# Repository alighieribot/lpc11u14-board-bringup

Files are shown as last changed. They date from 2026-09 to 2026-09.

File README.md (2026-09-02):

# Board Bring-Up e Validação de Protótipo Eletrônico Embarcado
## Plataforma de Instrumentação e Controle Baseada no MCU NXP LPC11U14F (ARM Cortex-M0)








Este repositório reúne a documentação técnica integral, os projetos de engenharia eletrônica (esquemático elétrico, layout de PCI de 2 camadas e modelos 3D desenvolvidos no KiCad 9) e o firmware embarcado modular em linguagem C (bare-metal) estruturado em **Máquina de Estados Finitos (FSM)** para validação física e *board bring-up* de uma placa com o microcontrolador **NXP LPC11U14F** (núcleo ARM Cortex-M0).

O projeto foi concebido e implementado no âmbito da disciplina **PBLE02 (Projeto Baseado em Laboratório de Engenharia / Projeto de Hardware e Firmware)** do **Instituto de Engenharia de Sistemas e Tecnologia da Informação (IESTI)** da **Universidade Federal de Itajubá (UNIFEI)**, sob a orientação do **Prof. Dr. Rodrigo Maximiano Antunes de Almeida**.

---

## Equipe do Projeto (Grupo 1)

| Integrante | Matrícula |
| :--- | :---: |
| **Leonardo Mendonça Costa** | `2024001025` |
| **Fabricio Augusto Antonio** | `2025000031` |
| **Pedro Henrique Oliveira Francisco** | `2022003245` |
| **Luis Gustavo Ribeiro Chacon** | `2025004890` |

**Agradecimentos Institucionais:**
À equipe técnica de laboratório do IESTI/UNIFEI, em especial aos técnicos em eletrônica **José Anderson Reis** e **Nedson Joaquim Maia**, pelo auxílio instrumental de bancada, suporte de montagem e retrabalho de protótipos; e ao **Prof. Dr. Rodrigo Maximiano Antunes de Almeida** pelas orientações e direcionamento técnico durante a validação experimental.

---

## Visão Geral da Placa de Circuito Impresso (PCB)

A placa física foi projetada respeitando dimensões compactas de $80 \times 80\text{ mm}^2$ em substrato de fibra de vidro FR-4 de duas camadas condutivas, espessura de 1,6 mm, acabamento superficial HASL com chumbo, máscara de solda verde e serigrafia branca, fabricada pela JLCPCB.

| Face Superior 3D (Revisão Final Corrigida) | Face Inferior 3D (Plano de Terra Sólido) |
| :---: | :---: |
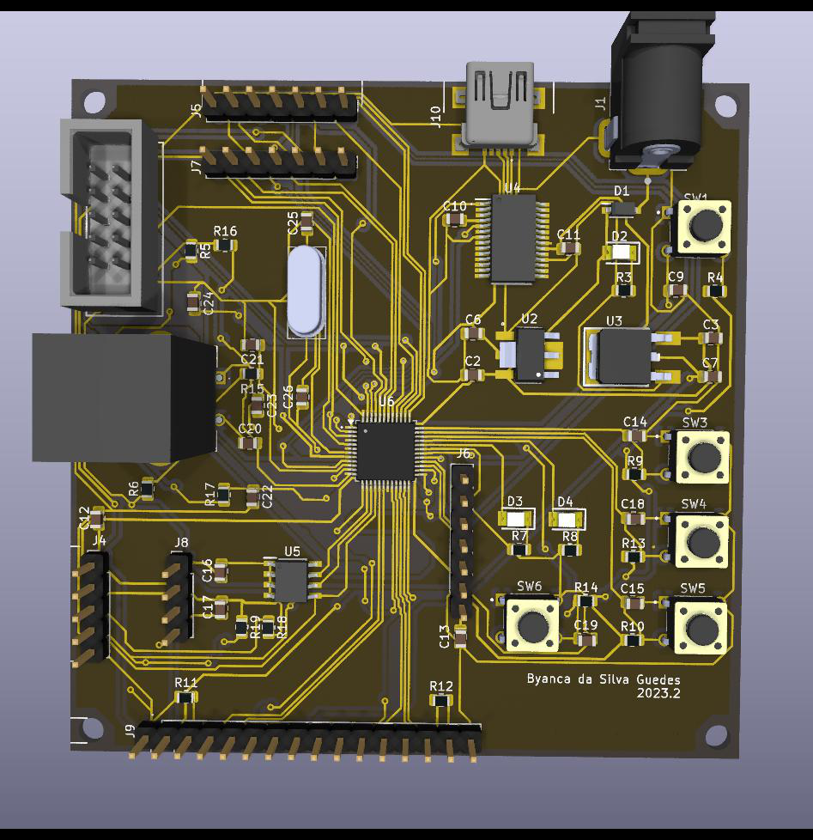
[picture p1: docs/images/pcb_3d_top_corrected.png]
PCB Top View
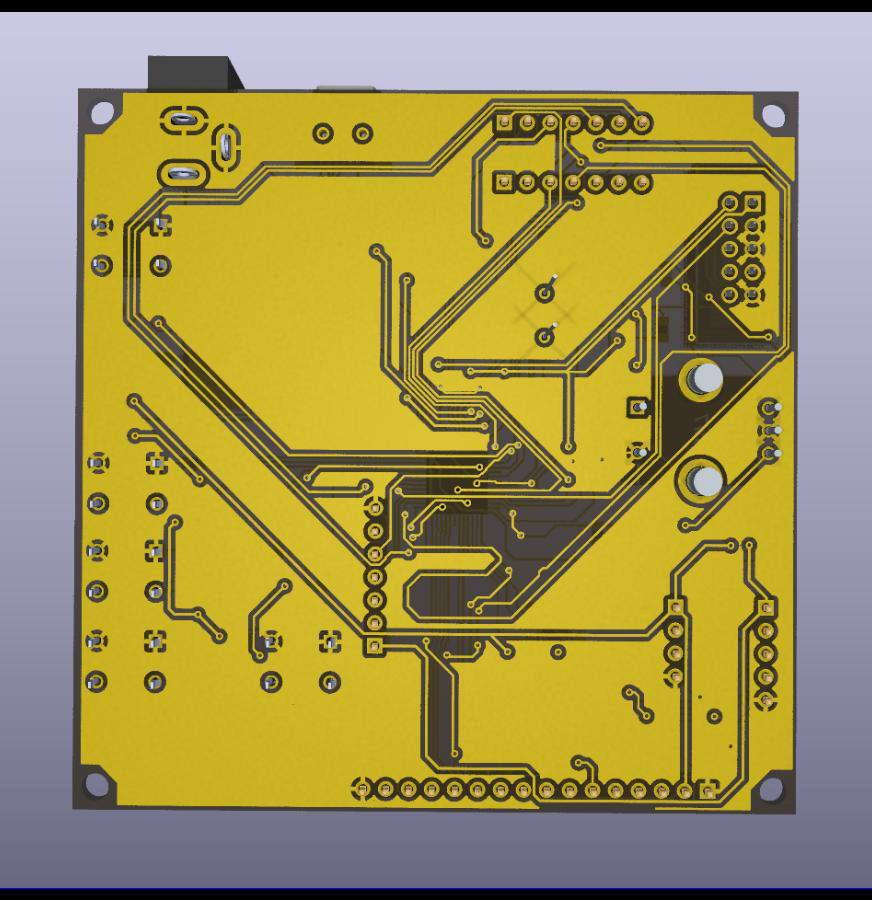
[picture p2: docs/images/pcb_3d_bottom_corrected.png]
PCB Bottom View
|  |  |

| Comparativo Histórico: Face Superior 3D Original |
| :---: |
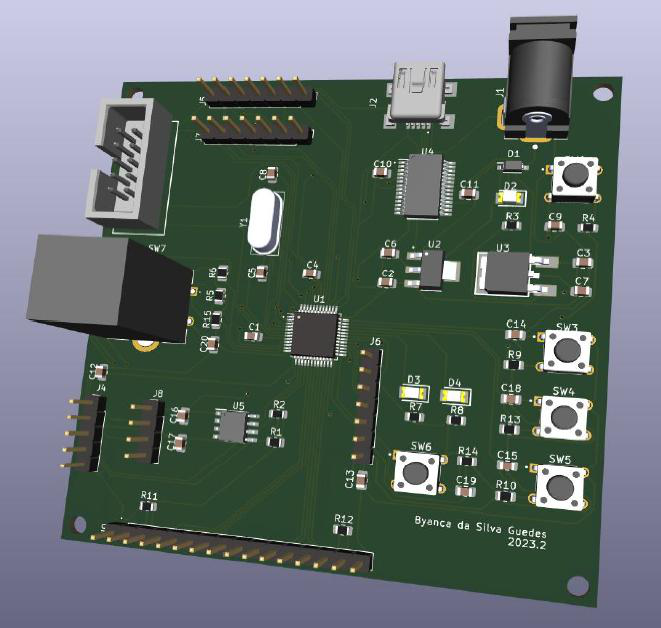
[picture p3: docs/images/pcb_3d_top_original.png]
PCB Top Original
|  |

> **BOM Interativo (iBOM):** O repositório inclui a lista de materiais interativa gerada pelo plugin *Interactive HTML BOM*. Para navegar visualmente por cada componente, ilha e footprint na placa, abra em seu navegador o arquivo [`KiCad/Projeto_Final/bom/ibom.html`](KiCad/Projeto_Final/bom/ibom.html).

---

## Arquitetura de Hardware & Subcircuitos

O sistema é subdividido em 5 subsistemas funcionais integrados:

```mermaid
graph TD
    PS["1. Subcircuito de Alimentação<br/>Jack DC 7-12V -> LD1117 5.0V & 3.3V"] --> MCU["2. Processamento Central<br/>NXP LPC11U14F ARM Cortex-M0 @ 48MHz"]
    PS --> COMM["5. Comunicação Serial<br/>FTDI FT232RL USB-UART"]
    PS --> HMI["3. Interface Homem-Máquina<br/>LCD 16x2, Encoder Bourns, 4x Teclas, LEDs"]
    PS --> PERIPH["4. Periféricos & Armazenamento<br/>EEPROM I2C 24LC512 + Headers Expansão"]

    MCU <-->|"UART 115200 bps"| COMM
    MCU <-->|"Barramento I2C 3.3V"| PERIPH
    MCU <-->|"GPIOs & PWM / Timers"| HMI
    MCU <-->|"ADC 10-bit / SPI / Expansão"| PERIPH
```

### 1. Subcircuito de Alimentação
- **Entrada:** Conector Jack fêmea P4 (PJ-002A) compatível com fontes externas DC na faixa de **7V a 12V**.
- **Proteção:** Diodo Schottky `1N5819HW-7-F` em série para bloqueio contra inversão de polaridade e transientes.
- **Regulação Linear em Cascata:**
  - `LD1117DT50TR` (DPAK): Converte a tensão de entrada para o barramento de **5.0V DC** (alimentação do display LCD).
  - `LD1117S33TR` (SOT-223): Fornece **3.3V DC** regulados (para microcontrolador, transceptor USB e EEPROM).
- **Filtragem e Desacoplamento:** Associação de capacitores eletrolíticos de $10\ \mu\text{F}$ e cerâmicos multicamada X7R de $220\text{ nF}$ nas entradas e saídas. LED piloto indicador de barramento energizado com resistor limitador de $1\text{ k}\Omega$.

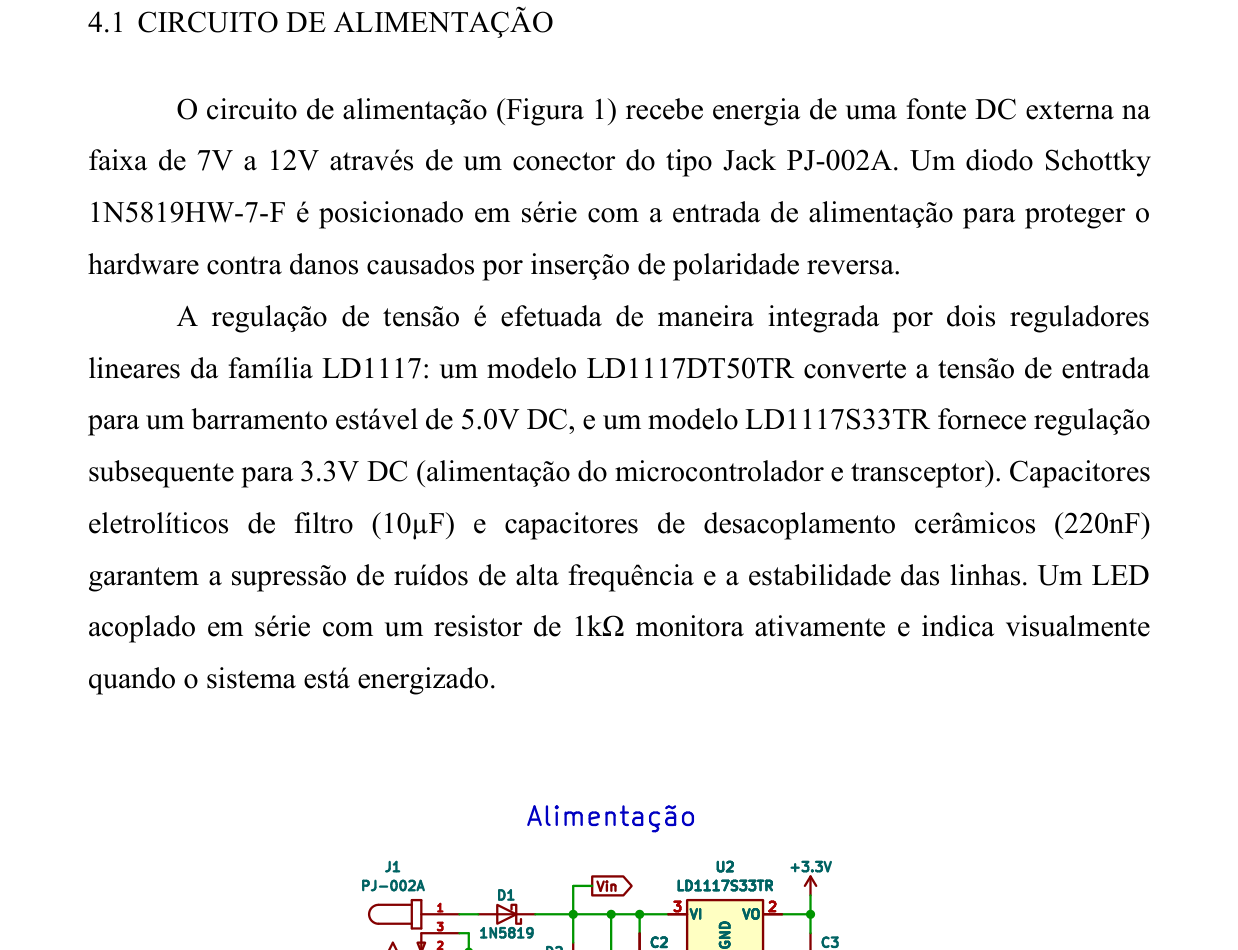
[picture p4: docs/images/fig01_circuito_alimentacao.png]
Circuito de Alimentação


---

### 2. Subcircuito de Processamento
- **MCU:** NXP `LPC11U14F/201` em encapsulamento LQFP-48, núcleo ARM Cortex-M0 operando a até **48 MHz**, dotado de 32 KB de memória Flash, 6 KB de SRAM, 4 KB de EEPROM integrada e controlador USB full-speed.
- **Oscilador de Clock:** Cristal de quartzo de alta precisão de **12.000 MHz** (CTS ATS12A) associado a capacitores de carga externos dimensionados em **18 pF**.
- **Reset e Bootloader ISP:**
  - Reset mestre com botão táctil `SW1`, pull-up de $4.7\text{ k}\Omega$ e capacitor de debounce de $10\ \mu\text{F}$.
  - Chave de programação em sistema (ISP) `SW6` com pull-up, interligada ao pino oficial de bootloader `PIO0_1` (Pino 4).
- **Depuração / Programação:** Header SWD (*Serial Wire Debug*) com pinos `SWDIO` (Pino 39) e `SWDCLK` (Pino 29).

| Processamento Original (LPC1114) | Processamento Corrigido (LPC11U14F) |
| :---: | :---: |
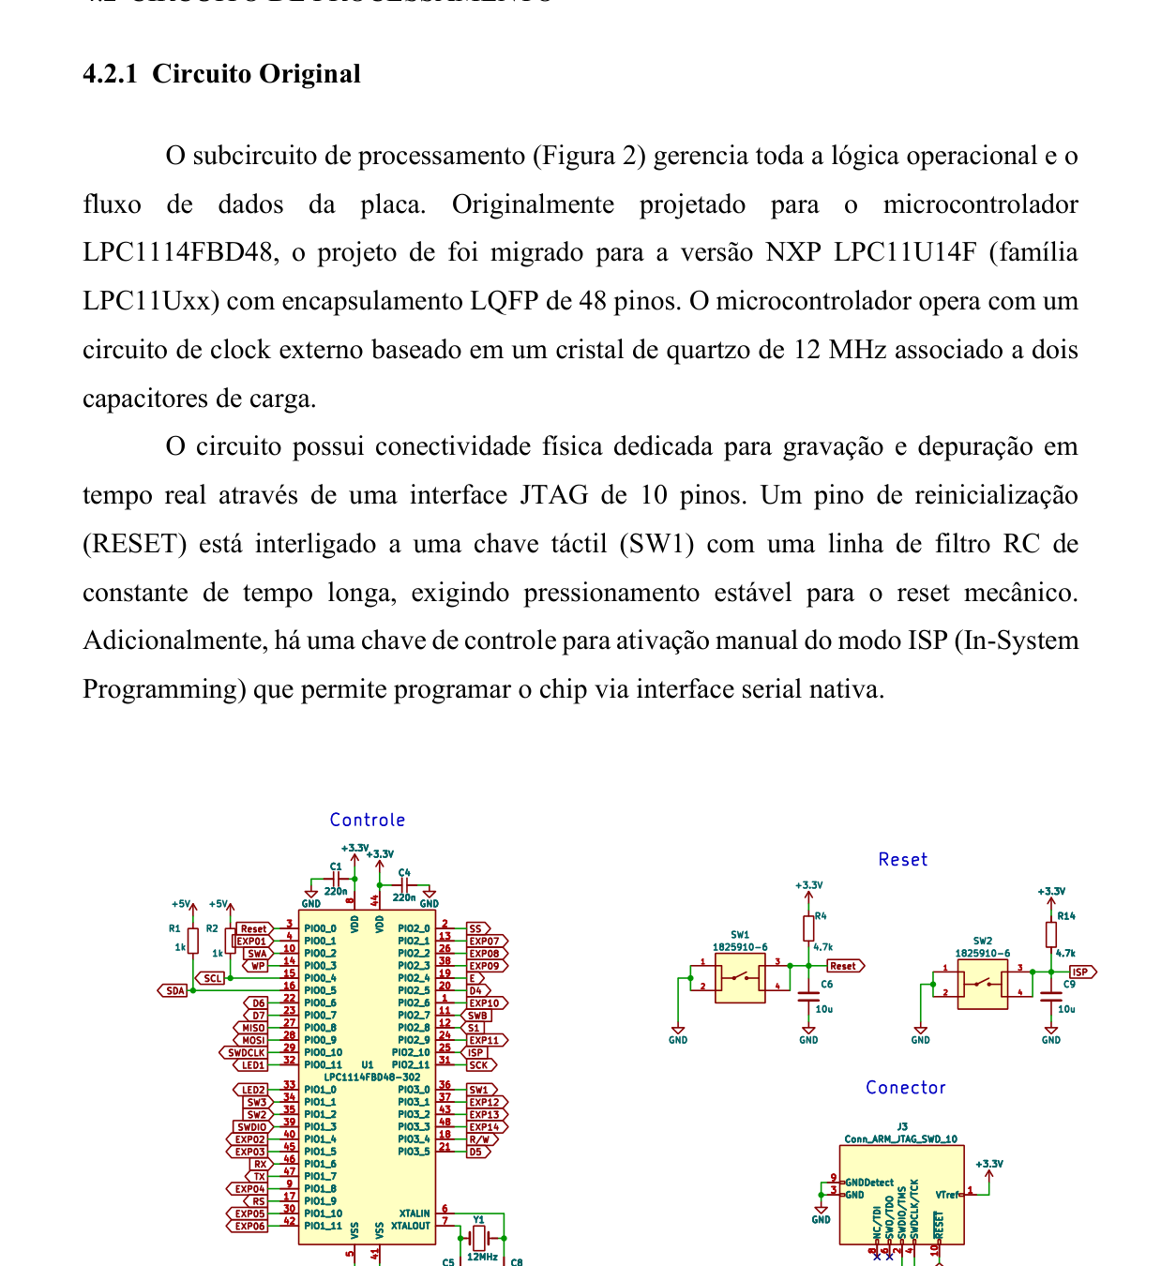
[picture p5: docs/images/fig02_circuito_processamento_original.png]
Processamento Original
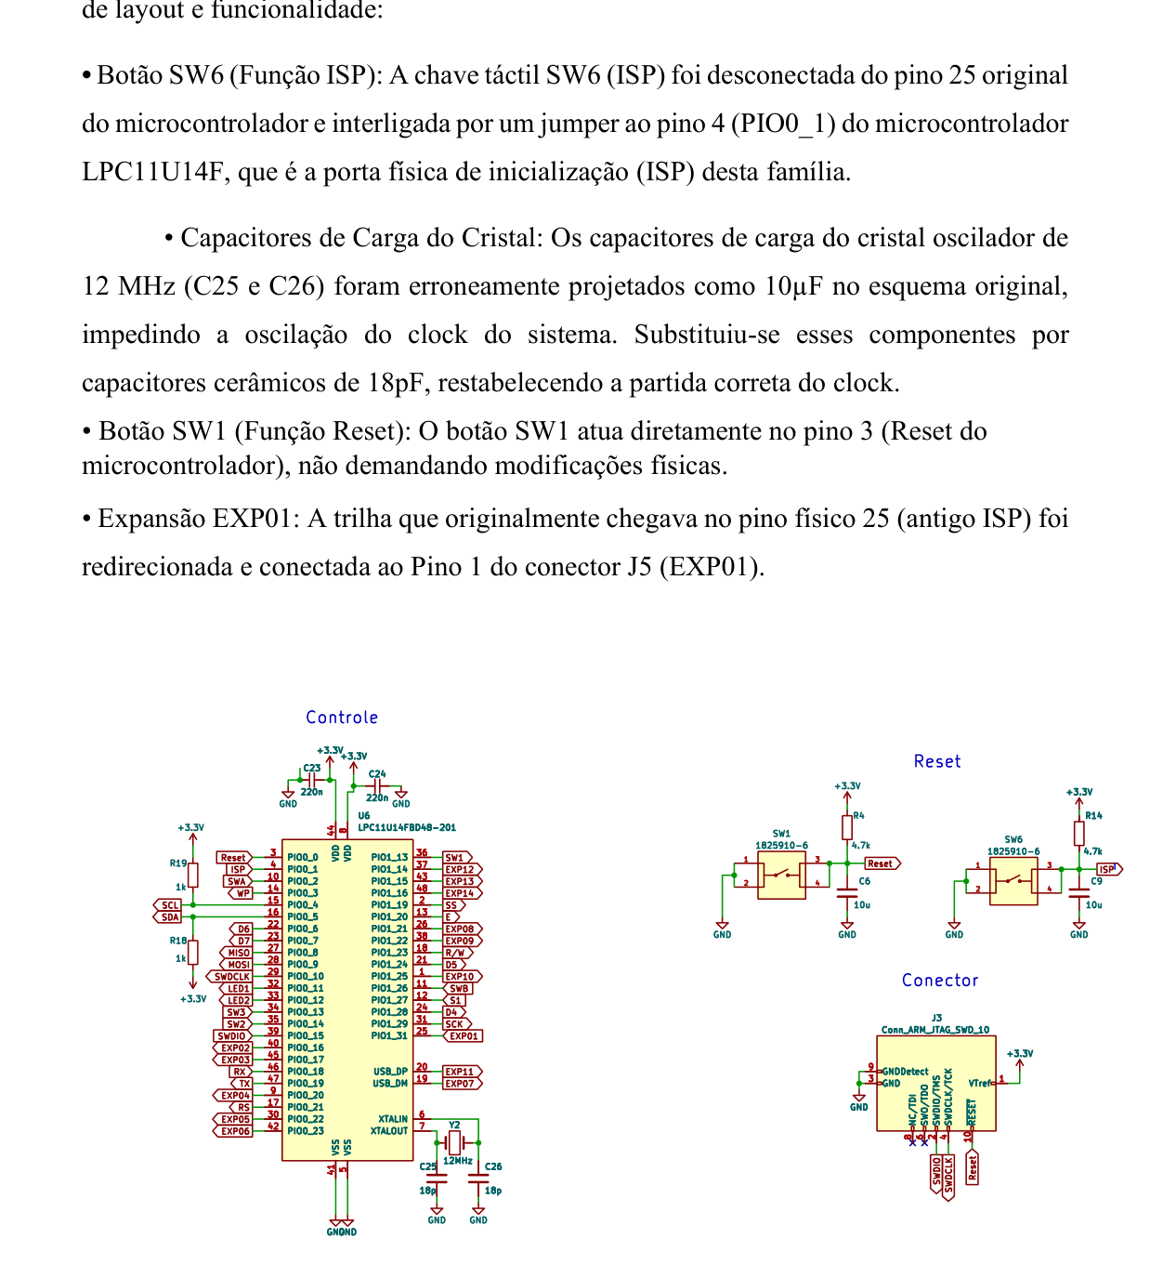
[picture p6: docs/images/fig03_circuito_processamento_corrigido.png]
Processamento Corrigido
|  |  |

---

### 3. Subcircuito de Interação com o Usuário (IHM)
- **Display Alfanumérico:** LCD 16×2 (compatível com controlador HD44780 / JHD162A) operando em barramento paralelo de **4 bits** (`D4` a `D7`), com controle pelos sinais `RS`, `R/W` e `ENABLE`. Ajuste de contraste via trimpot de precisão de $10\text{ k}\Omega$.
- **Encoder Rotativo Incremental:** Bourns `PEC12R` com 24 pulsos por rotação, canais em quadratura A e B, botão de clique central e filtro RC passivo anti-ruído mecânico (*debounce*).
- **Teclado Táctil:** 4 chaves tácteis push-button (`SW2`, `SW3`, `SW4`, `SW5`) com resistores de pull-up de $10\text{ k}\Omega$.
- **Sinalizadores Visuais:** Três LEDs SMD (`D2`, `D3`, `D4`) acionados diretamente pelas saídas digitais do microcontrolador com resistores limitadores de $100\ \Omega$.

| Interação Original | Interação Corrigida (Ajuste de R e C) |
| :---: | :---: |
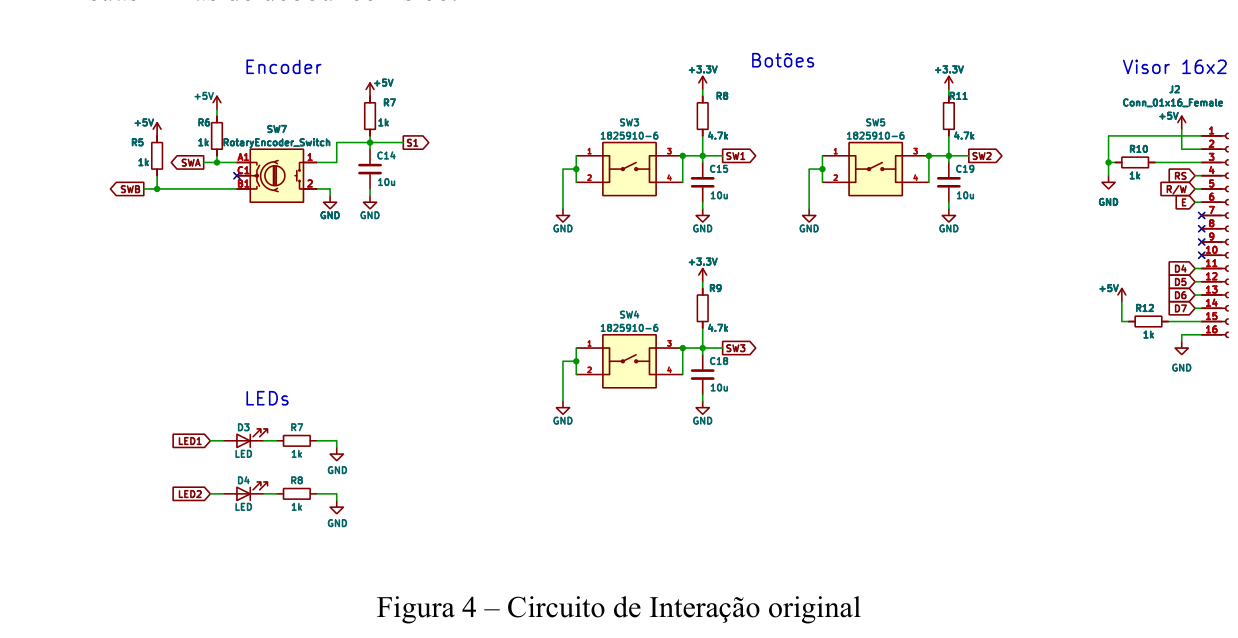
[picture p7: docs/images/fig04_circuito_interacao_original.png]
Interação Original
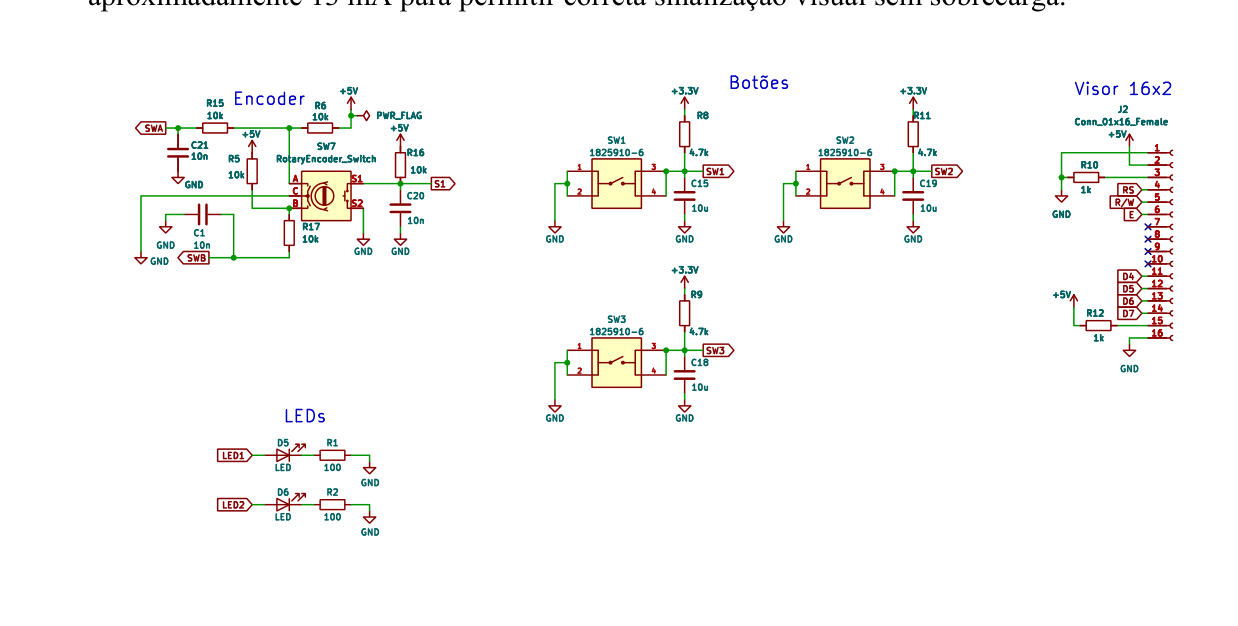
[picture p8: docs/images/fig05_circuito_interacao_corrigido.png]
Interação Corrigida
|  |  |

---

### 4. Subcircuito de Periféricos & Armazenamento
- **Memória EEPROM Externa:** Microchip `24LC512` (512 Kbit / 64 KByte) operando via barramento **I²C** com resistores de pull-up de $1\text{ k}\Omega$ polarizados em 3.3V.
- **Barramentos de Expansão:** Headers macho de passo 2.54 mm (`J4` a `J8`) expondo portas analógicas do ADC (10 bits), barramento SPI (`SCK`, `MISO`, `MOSI`, `SSEL`), alimentação e GPIOs livres.
- **Condicionamento de Sinal:** Canal de amplificação operacional para transdução de sinais analógicos externos com compensação de ganho em software (`GANHO_AMPOP`).

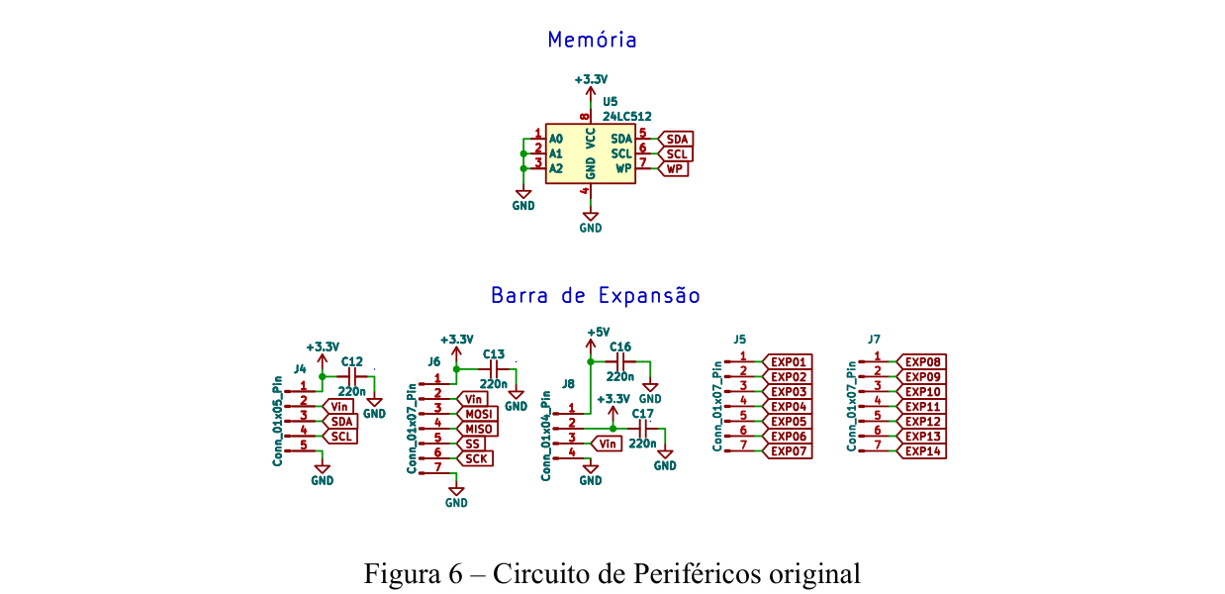
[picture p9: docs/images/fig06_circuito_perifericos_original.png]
Circuito de Periféricos


---

### 5. Subcircuito de Comunicação Serial
- **Transceptor USB-UART:** Chip dedicado FTDI `FT232RL` (SSOP-28) realizando a ponte entre o barramento USB da estação hospedeira e as portas seriais assíncronas do microcontrolador (`PIO0_18/RXD` e `PIO0_19/TXD`).
- **Conector Físico:** Porta Mini-USB Tipo B com filtragem e desacoplamento de alta frequência.

| Comunicação Original | Comunicação Corrigida (Isolamento VBUS) |
| :---: | :---: |
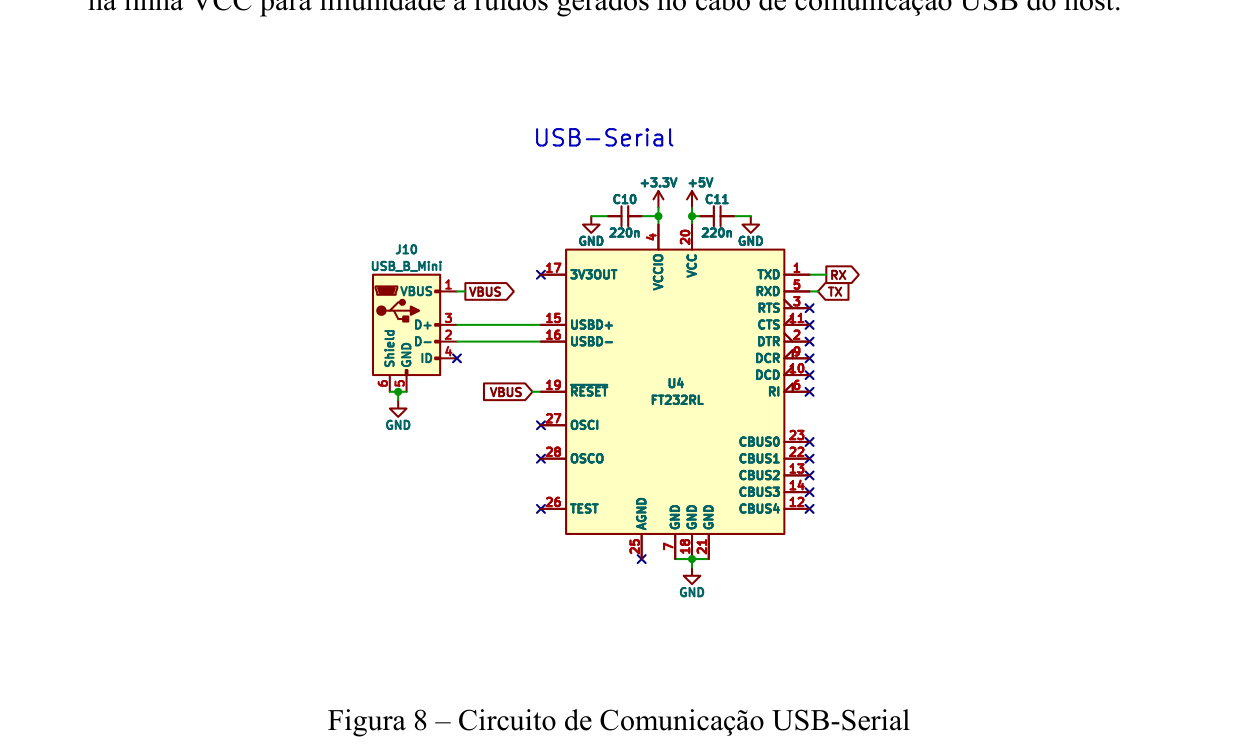
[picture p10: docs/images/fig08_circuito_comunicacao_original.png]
Comunicação Original
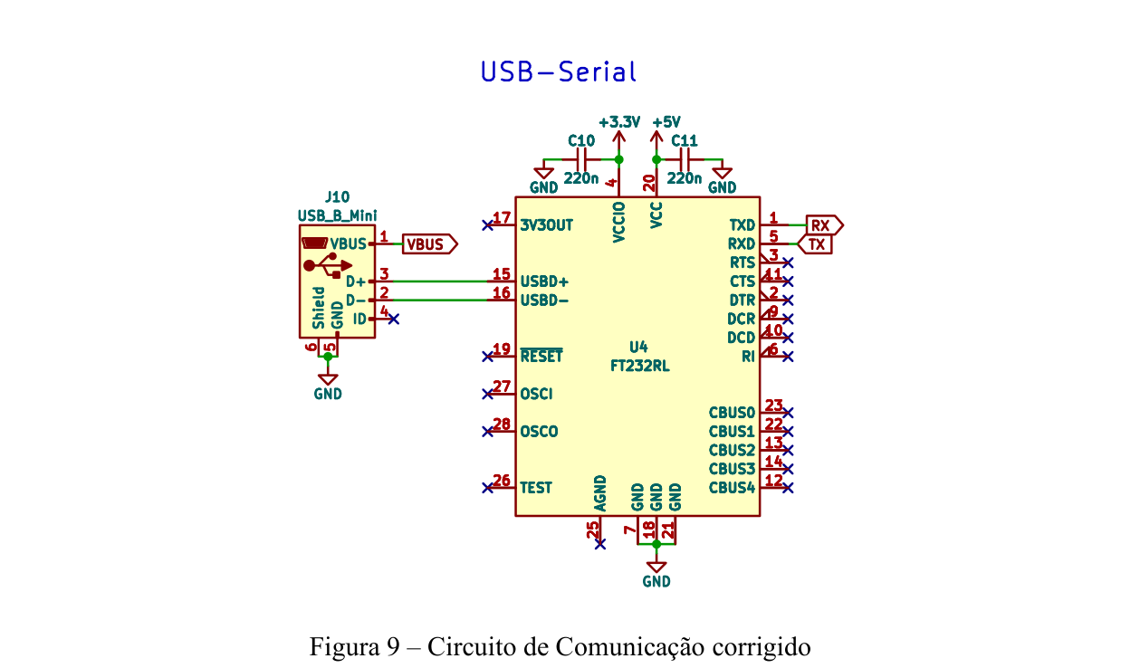
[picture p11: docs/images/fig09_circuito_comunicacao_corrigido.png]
Comunicação Corrigida
|  |  |

---

### Verificação de Regras Elétricas (ERC) e de Layout (DRC)
Durante o desenvolvimento no KiCad 9, a conformidade de conexões e fabricabilidade foi atestada:

| Esquema Elétrico ERC Original (Avisos) | Esquema Elétrico ERC Corrigido (0 Erros) |
| :---: | :---: |
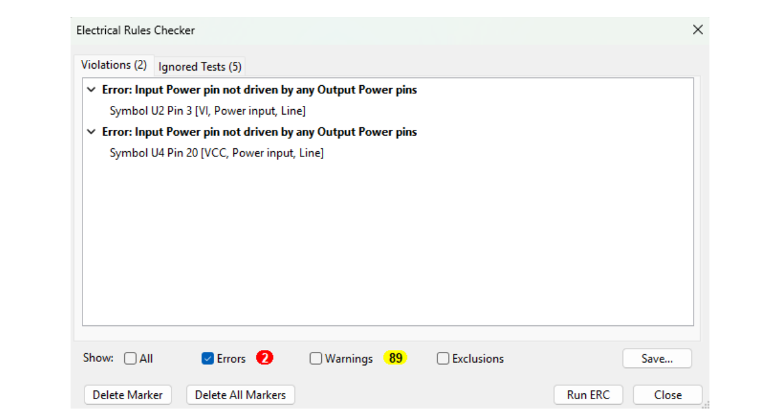
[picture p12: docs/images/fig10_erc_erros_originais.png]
ERC Original
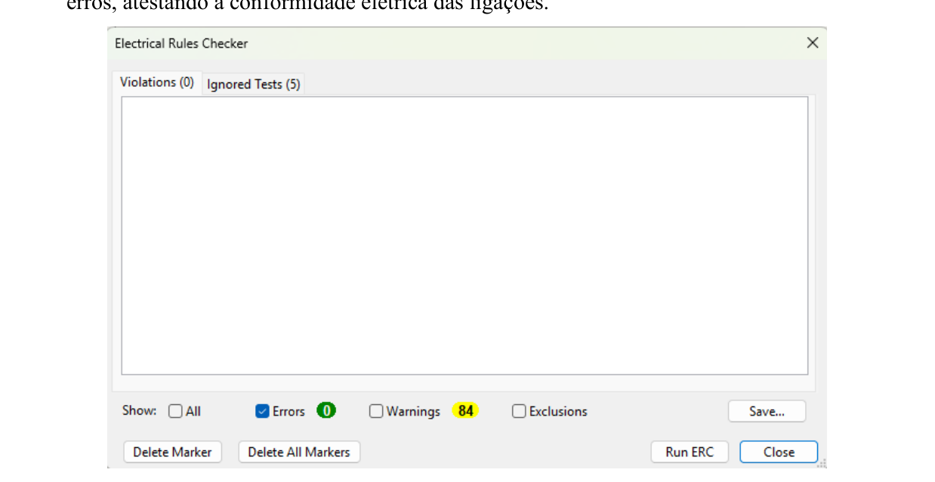
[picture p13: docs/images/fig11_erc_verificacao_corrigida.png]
ERC Corrigido
|  |  |

| DRC da Placa Original (Conflitos e Ilhas Isoladas) | DRC da Placa Corrigida (100% Validada) |
| :---: | :---: |
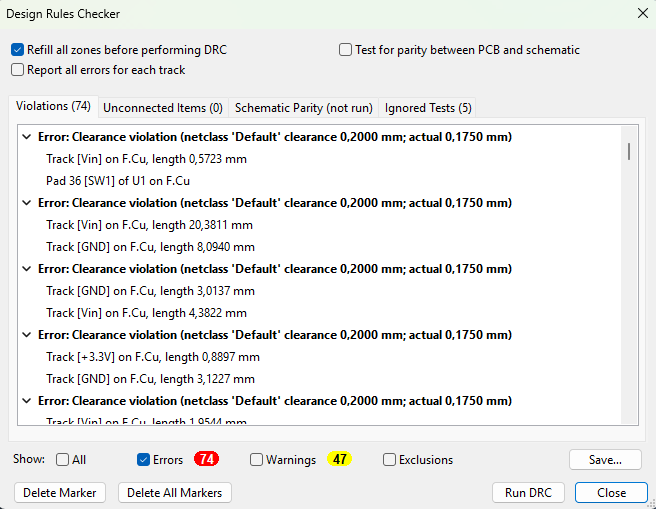
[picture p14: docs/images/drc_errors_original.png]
DRC Original
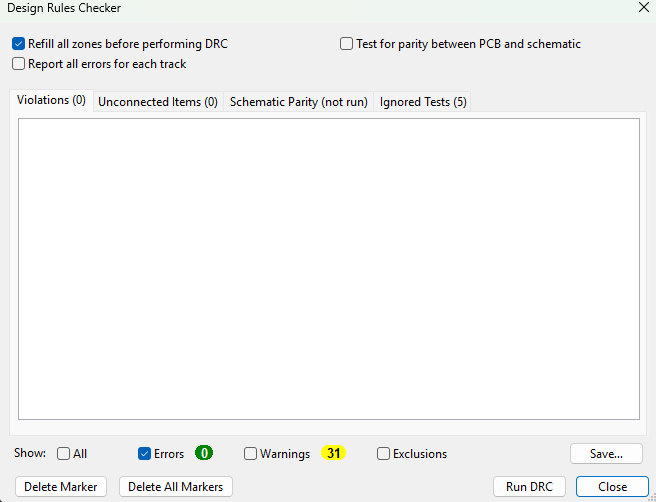
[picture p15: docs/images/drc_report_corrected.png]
DRC Corrigido
|  |  |

---

## Board Bring-Up: Modificações Físicas & Memorial de Cálculos

Durante a etapa prática de validação e *bring-up* em bancada com osciloscópio digital e multímetro de precisão, foram diagnosticadas discrepâncias no circuito original que demandaram **engenharia de retrabalho** (cortes de trilhas na PCI, soldagem de *jumpers* de precisão e readequação de componentes passivos).

### 1. Dimensionamento dos Capacitores de Carga do Cristal Oscilador (C25 e C26)
- **Problema Diagnosticado:** O esquemático original previa erroneamente capacitores de $10\ \mu\text{F}$ nas linhas `XTALIN` e `XTALOUT`. O excesso de reatância capacitiva aterrou os sinais de alta frequência e impediu qualquer ressonância do cristal de quartzo de 12 MHz, travando a inicialização do núcleo ARM.
- **Memorial de Cálculo da Capacitância Externa ($C_{ext}$):**
  O cristal de quartzo de 12 MHz (CTS ATS12A) especifica capacitância de carga nominal $C_L = 12\text{ pF}$. A capacitância parasita combinada das trilhas da PCI e pinos do chip é estimada em $C_s \approx 3\text{ pF}$. Como os dois capacitores de carga externos são idênticos ($C_1 = C_2 = C_{ext}$):
  $$C_L = \frac{C_1 \cdot C_2}{C_1 + C_2} + C_s = \frac{C_{ext}^2}{2 \cdot C_{ext}} + C_s = \frac{C_{ext}}{2} + C_s$$
  $$C_{ext} = 2 \cdot (C_L - C_s) = 2 \cdot (12\text{ pF} - 3\text{ pF}) = 2 \cdot 9\text{ pF} = \mathbf{18\text{ pF}}$$
- **Ação Realizada:** Substituição imediata dos capacitores $C_{25}$ e $C_{26}$ por cerâmicos C0G/NP0 de **18 pF**, viabilizando a oscilação estável do clock a 12 MHz.

---

### 2. Constante de Tempo do Filtro RC do Encoder Rotativo
- **Problema Diagnosticado:** O filtro RC do encoder `SW7` continha capacitores de $10\ \mu\text{F}$ com pull-ups de $10\text{ k}\Omega$, gerando constante de tempo $\tau = 100\text{ ms}$. Isso deformava os trens de pulso de quadratura durante giros normais, impossibilitando a leitura do sentido de rotação.
- **Memorial de Cálculo de Resposta em Frequência e Debounce:**
  Para filtrar o repique de contato mecânico (*bouncing*, típico de dezenas a centenas de microssegundos conforme Bourns) sem degradar giros manuais rápidos, os capacitores foram redimensionados para $C = 10\text{ nF}$:
  $$\tau = R \cdot C = (10 \times 10^3\ \Omega) \cdot (10 \times 10^{-9}\text{ F}) = 100\ \mu\text{s} = \mathbf{0.1\text{ ms}}$$
  A frequência de corte do filtro passa-baixas resultante é:
  $$f_c = \frac{1}{2 \cdot \pi \cdot R \cdot C} = \frac{1}{2 \cdot \pi \cdot 100\ \mu\text{s}} \approx \mathbf{1.59\text{ kHz}}$$
- **Ação Realizada:** Troca dos capacitores para **10 nF**, garantindo imunidade a repiques mecânicos e leitura instantânea de rotação em ambos os sentidos.

---

### 3. Tensão Lógica e Corrente de Dreno (Sink) no Barramento I²C
- **Problema Diagnosticado:** Os resistores de pull-up $R_1$ e $R_2$ ($1\text{ k}\Omega$) estavam conectados à malha de **5.0V**. Pela especificação oficial do protocolo I²C, a corrente de dreno em nível baixo ($I_{OL}$) em saídas open-drain não deve ultrapassar $3.0\text{ mA}$ para assegurar $V_{OL} \le 0.4\text{ V}$.
  $$I_{OL(5V)} = \frac{5.0\text{ V} - 0.4\text{ V}}{1\text{ k}\Omega} = \mathbf{4.6\text{ mA}} \quad (\text{Excede o limite normativo de 3 mA!})$$
- **Memorial de Cálculo com Alimentação Corrigida em 3.3V:**
  $$I_{OL(3.3V)} = \frac{3.3\text{ V} - 0.4\text{ V}}{1\text{ k}\Omega} = \mathbf{2.9\text{ mA}} \quad (< 3.0\text{ mA}, \text{em estrita conformidade})$$
- **Ação Realizada:** Corte da ilha de 5V e ligação por *jumper* dos resistores de pull-up $R_1$ e $R_2$ à tensão de 3.3V do pino 8 da EEPROM (U5).

---

### 4. Dimensionamento dos Resistores Limitadores dos LEDs (D2, D3, D4)
- **Problema Diagnosticado:** Com resistores originais de $1\text{ k}\Omega$ sob alimentação de 3.3V e queda direta $V_F = 2.0\text{ V}$ dos LEDs verdes Lite-On, a corrente era inexpressiva:
  $$I_{LED} = \frac{3.3\text{ V} - 2.0\text{ V}}{1\text{ k}\Omega} = \mathbf{1.3\text{ mA}}$$
- **Memorial de Cálculo para Corrente Nominal de Sinalização ($R_d$):**
  Para assegurar fluxo luminoso adequado com corrente de $\approx 13\text{ mA}$ (dentro do limite máximo de 40 mA por porta do LPC11U14F):
  $$R_d = \frac{V_{DD} - V_F}{I_{desejado}} = \frac{3.3\text{ V} - 2.0\text{ V}}{13\text{ mA}} = \frac{1.3\text{ V}}{0.013\text{ A}} = \mathbf{100\ \Omega}$$
- **Ação Realizada:** Instalação de resistores SMD de **100 Ω** (código 101).

---

### 5. Retrabalhos Físicos de Roteamento (Cortes e Jumpers)
1. **Migração LPC1114 -> LPC11U14F:** Adaptação da distribuição de pinos do microcontrolador e inclusão do header `LPC11Uxx.h` no firmware.
2. **LCD ENABLE (E):** Trilha cortada no pino 19 (`USB_DM`) e religada por *jumper* ao pino 13 (`PIO1_20`).
3. **LCD DATA 4 (DB4):** Trilha cortada no pino 20 (`USB_DP`) e religada por *jumper* ao pino 24 (`PIO1_28`).
4. **Tecla Bootloader ISP (SW6):** Desconectada do pino 25 e religada por *jumper* ao pino 4 (`PIO0_1`), pino de hardware que força a entrada no bootloader ISP ROM do LPC11U14F.
5. **Linha de Expansão EXP01:** Desviada para o pino 1 do conector `J5` (associada ao pino 25 `PIO1_31`).
6. **Proteção de Barramento USB (VBUS):** Corte da trilha que injetava 5V do conector Mini-USB no barramento da placa, eliminando circulação de corrente indesejada entre a fonte externa e o computador hospedeiro.

---

## Arquitetura de Software & Firmware Embarcado

O firmware foi desenvolvido em **C (padrão C99)** bare-metal para microcontroladores ARM Cortex-M0, estruturado em uma arquitetura orientada a eventos e baseada em uma **Máquina de Estados Finitos (FSM - Finite State Machine)** determinística.

### Diagrama UML da Arquitetura do Software
O design modular desacopla a camada de aplicação/controle da camada de drivers de baixo nível de hardware:

Diagrama UML da Arquitetura do Software

---

### Diagrama da Máquina de Estados Finitos (FSM)

A lógica central da aplicação é governada por estados mutuamente exclusivos que respondem a eventos gerados assincronamente pelo teclado, encoder, temporizadores ou recepção serial:

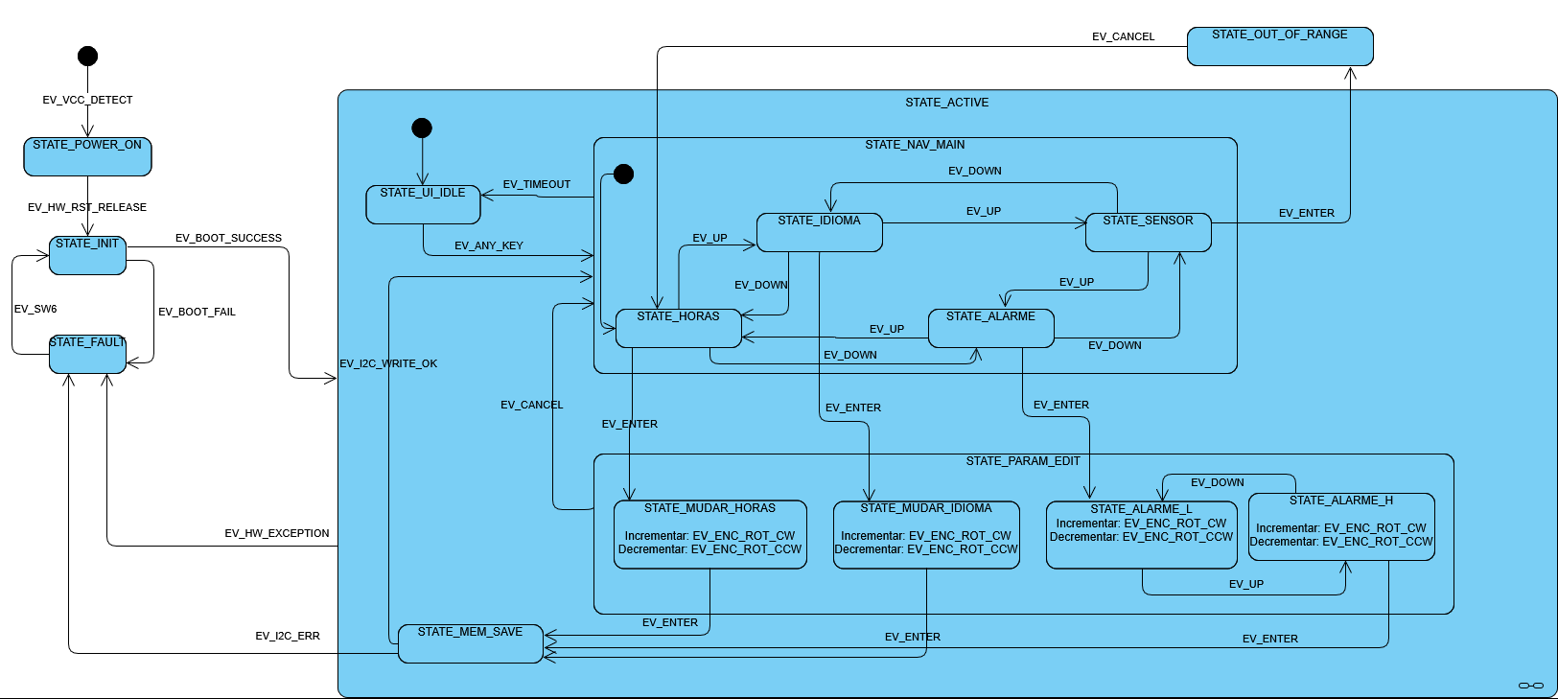
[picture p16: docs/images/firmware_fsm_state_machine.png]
Máquina de Estados do Firmware


#### Tabela de Estados Principais:
| Estado | Descrição Funcional | Transições & Eventos |
| :--- | :--- | :--- |
| `STATE_INIT` | Inicialização dos periféricos (GPIO, I²C, UART, Timer, LCD), restauração dos parâmetros salvos na EEPROM. | Avança automaticamente para `STATE_NAV_MAIN`. |
| `STATE_NAV_MAIN` | Carrossel principal de menus: Horas, Alarme, Leitura do Sensor e Idioma. | `EV_UP` (SW5) / `EV_DOWN` (SW3) alternam os menus. `EV_ENTER` (SW4) acessa o modo de edição. |
| `STATE_HORAS` | Exibição em tempo real do relógio RTC no display LCD. | `EV_ENTER` desvia para `STATE_MUDAR_HORAS`. |
| `STATE_MUDAR_HORAS`| Edição de horas e minutos em memória RAM. | Rotação horária (`EV_ENC_ROT_CW`) ou anti-horária (`EV_ENC_ROT_CCW`) ajusta o valor. Clique do encoder (`EV_CANCEL`) cancela. `EV_ENTER` salva na EEPROM (`STATE_MEM_SAVE`). |
| `STATE_ALARME` | Monitoramento dos limites de disparo de alarme de janela (Low e High). | `EV_ENTER` acessa edição dos limites `STATE_ALARME_L` e `STATE_ALARME_H`. |
| `STATE_SENSOR` | Aquisição contínua do valor analógico pelo conversor A/D (10 bits) com conversão em tensão ($V$). | Se a leitura violar os limites configurados, dispara `EV_OUT_OF_RANGE`. |
| `STATE_OUT_OF_RANGE`| **Estado de Segurança:** Alerta visual com piscamento em alta prioridade de LEDs e mensagem no LCD indicando condição anômala. | O sistema trava o alerta até que a variável analógica retorne à faixa de tolerância. |
| `STATE_IDIOMA` | Exibição do idioma de interface ativo (Português / Inglês). | `EV_ENTER` desvia para `STATE_MUDAR_IDIOMA`. |
| `STATE_MEM_SAVE` | Executa a rotina de gravação não-volátil na EEPROM externa via barramento I²C. | Retorna para `STATE_NAV_MAIN` após sucesso. |
| `STATE_UI_IDLE` | Modo de economia de energia por inatividade de teclas e escurecimento de display (*backlight*). | Disparado por `EV_TIMEOUT`. Qualquer tecla (`EV_ANY_KEY`) acorda o sistema. |
| `STATE_FAULT` | Tratamento de falha crítica (erro de barramento I²C ou perda de integridade). | Recuperação via `SW1` (Reset de hardware). |

---

### Estrutura Modular do Código-Fonte (`Código/PBLE02/src/`)
- **`programa.c / .h`**: Ponto de entrada (`main`), rotinas de inicialização de clock e laço infinito (`smLoop` e `processaComandoSerial`).
- **`ctl/stateMachine.c / .h`**: Implementação da FSM, definição dos estados e lógica de transição.
- **`ctl/event.c / .h`**: Amostragem periódica de periféricos e fila circular de eventos (`EV_UP`, `EV_DOWN`, `EV_ENTER`, `EV_CANCEL`, etc.).
- **`ctl/timer.c / .h`**: Configuração da interrupção periódica SysTick (base de tempo de 1 ms).
- **`ctl/var.c / .h`**: Gestão de variáveis globais do sistema, strings de menu multilíngue e controle de alarmes.
- **`ctl/output.c / .h`**: Mapeamento das saídas visuais e atualização de display.
- **`hardware/LCD.c / .h`**: Driver de baixo nível para display alfanumérico HD44780 em barramento de 4 bits.
- **`hardware/ENCODER.c / .h`**: Decodificador de quadratura dos canais A/B do encoder Bourns.
- **`hardware/Teclado.c / .h`**: Varredura das teclas tácteis de navegação com debounce digital.
- **`hardware/EEPROM.c / .h` & `I2C.c / .h`**: Driver mestre I²C para leitura/gravação não-volátil de blocos na memória 24LC512.
- **`hardware/RTC.c / .h`**: Relógio de tempo real implementado por software com base no SysTick.
- **`hardware/Serial.c / .h`**: Driver assíncrono UART com buffer circular de recepção/transmissão e decodificador ASCII.
- **`hardware/ADC.c / .h` & `DAC.c / .h`**: Amostragem analógica de 10 bits e conversão D/A.
- **`hardware/LED.c / .h`**: Acionamento e controle de estados dos LEDs.

---

### Protocolo de Telemetria e Comandos Serial (UART @ 115200 bps)

O transceptor USB-Serial executa um *parser* de comandos ASCII permitindo tanto a consulta (*getters*) quanto a calibração remota de parâmetros (*setters*):

| Comando Serial | Direção | Formato da Resposta / Ação | Exemplo de Saída |
| :--- | :---: | :--- | :--- |
| `gettime` | Entrada | Retorna o horário atual do RTC interno | `#time=14:32:05#` |
| `getsensor` | Entrada | Retorna o valor raw do ADC (10 bits) e a tensão calibrada em Volts | `#sensor=0512/1.65V#` |
| `getalarmelow` | Entrada | Retorna o limiar inferior do alarme | `#alarmeLow=250#` |
| `getalarmehigh`| Entrada | Retorna o limiar superior do alarme | `#alarmeHigh=400#` |
| `alarmelow:<val>` | Entrada | Ajusta o limiar inferior e grava na EEPROM | `#alarmeLow=280#` |
| `alarmehigh:<val>`| Entrada | Ajusta o limiar superior e grava na EEPROM | `#alarmeHigh=420#` |
| `time:<hh>:<mm>:<ss>`| Entrada| Sincroniza o relógio RTC de software | `#time=09:15:00#` |
| `language:<0\|1>`| Entrada | Seleciona o idioma (0: Português, 1: Inglês) | `#language=0#` |
| `'0'`, `'1'`, `'2'`, `'3'` | Entrada | Comuta (*toggle*) o estado lógico dos LEDs indicadores de status | Ecoa o caractere transmitido |

---

## Mapa de Pinos do Microcontrolador LPC11U14F

Diagrama oficial do encapsulamento LQFP-48 e mapa de conexão das portas com o hardware físico:

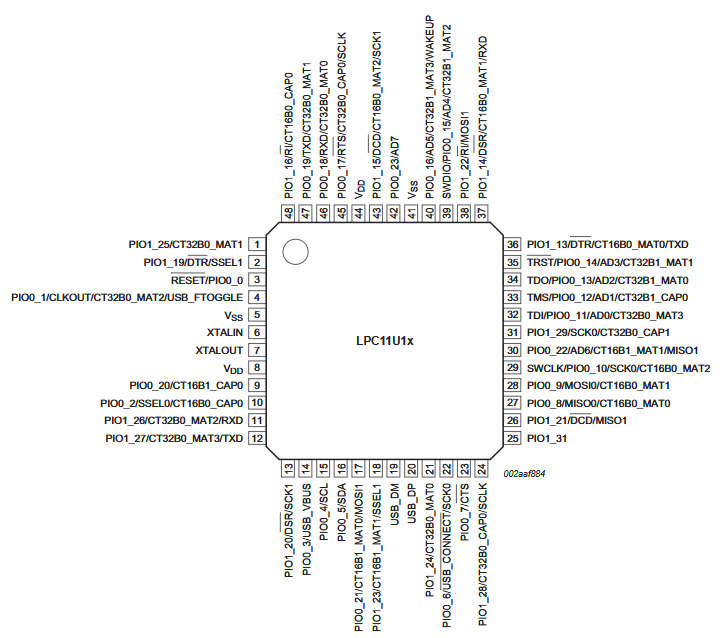
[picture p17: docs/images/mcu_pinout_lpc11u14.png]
Pinout LPC11U14F


<details open>
<summary><b>Tabela Completa dos 48 Pinos do LPC11U14F</b></summary>

| Pino | Porta GPIO | Função / Conexão no Esquemático | Destino Físico |
| :---: | :---: | :--- | :--- |
| 1 | `PIO1_25` | `EXP10` | Header de Expansão J7.3 |
| 2 | `PIO1_19` | `SS` (SPI Slave Select) | Header de Expansão J6.5 |
| 3 | `PIO0_0` | `RESET` | Botão Reset SW1 com pull-up |
| 4 | `PIO0_1` | `ISP` (Bootloader de Gravação) | Botão táctil SW6 (Jumper de correção) |
| 5 | `VSS` | Terra Digital (`GND`) | Plano de Terra |
| 6 | `XTALIN` | Entrada do Oscilador de Quartzo | Cristal 12MHz Pino 1 / C25 (18pF) |
| 7 | `XTALOUT`| Saída do Oscilador de Quartzo | Cristal 12MHz Pino 3 / C26 (18pF) |
| 8 | `VDD` | Alimentação Positiva `+3.3V` | Barramento de 3.3V |
| 9 | `PIO0_20` | `EXP04` | Header de Expansão J5.4 |
| 10 | `PIO0_2` | Canal A do Encoder Rotativo (`SWA`) | Chave Bourns SW7.A1 |
| 11 | `PIO1_26` | Canal B do Encoder Rotativo (`SWB`) | Chave Bourns SW7.B1 |
| 12 | `PIO1_27` | Botão Integrado do Encoder (`S1`) | Chave Bourns SW7.1 |
| 13 | `PIO1_20` | Habilitação do LCD (`ENABLE` / `E`) | Conector LCD J9.6 (Jumper de correção) |
| 14 | `PIO0_3` | Proteção de Escrita da EEPROM (`WP`) | Pino 7 da EEPROM U5 |
| 15 | `PIO0_4` | Clock I²C (`SCL`) | Pino 6 da EEPROM U5 (Pull-up em 3.3V) |
| 16 | `PIO0_5` | Dados I²C (`SDA`) | Pino 5 da EEPROM U5 (Pull-up em 3.3V) |
| 17 | `PIO0_21` | Seleção de Registrador LCD (`RS`) | Conector LCD J9.4 |
| 18 | `PIO1_23` | Leitura/Escrita do LCD (`R/W`) | Conector LCD J9.5 |
| 19 | `USB_DM` | `EXP07` (Livre após corte do LCD) | Header de Expansão J5.7 |
| 20 | `USB_DP` | `EXP11` (Livre após corte do LCD) | Header de Expansão J7.4 |
| 21 | `PIO1_24` | Barramento de Dados LCD (`D5`) | Conector LCD J9.12 |
| 22 | `PIO0_6` | Barramento de Dados LCD (`D6`) | Conector LCD J9.13 |
| 23 | `PIO0_7` | Barramento de Dados LCD (`D7`) | Conector LCD J9.14 |
| 24 | `PIO1_28` | Barramento de Dados LCD (`D4`) | Conector LCD J9.11 (Jumper de correção) |
| 25 | `PIO1_31` | `EXP01` | Header de Expansão J5.1 |
| 26 | `PIO1_21` | `EXP08` | Header de Expansão J7.1 |
| 27 | `PIO0_8` | Linha SPI `MISO` | Header de Expansão J6.4 |
| 28 | `PIO0_9` | Linha SPI `MOSI` | Header de Expansão J6.3 |
| 29 | `PIO0_10` | Depuração SWD Clock (`SWDCLK`) | Header de Gravação J3.4 |
| 30 | `PIO0_22` | `EXP05` | Header de Expansão J5.5 |
| 31 | `PIO1_29` | Linha SPI Clock (`SCK`) | Header de Expansão J6.6 |
| 32 | `PIO0_11` | LED Indicador de Status 1 | LED D3.2 |
| 33 | `PIO0_12` | LED Indicador de Status 2 | LED D4.2 |
| 34 | `PIO0_13` | Tecla Navegação Baixo (`SW3`) | Chave Táctil SW5.3 |
| 35 | `PIO0_14` | Tecla Confirmação Enter (`SW2`) | Chave Táctil SW4.3 |
| 36 | `PIO1_13` | Tecla Navegação Cima (`SW1`) | Chave Táctil SW3.3 |
| 37 | `PIO1_14` | `EXP12` | Header de Expansão J7.5 |
| 38 | `PIO1_22` | `EXP09` | Header de Expansão J7.2 |
| 39 | `PIO0_15` | Depuração SWD Dados (`SWDIO`) | Header de Gravação J3.2 |
| 40 | `PIO0_16` | `EXP02` | Header de Expansão J5.2 |
| 41 | `VSS` | Terra Digital (`GND`) | Plano de Terra |
| 42 | `PIO0_23` | `EXP06` | Header de Expansão J5.6 |
| 43 | `PIO1_15` | `EXP13` | Header de Expansão J7.6 |
| 44 | `VDD` | Alimentação Positiva `+3.3V` | Barramento de 3.3V |
| 45 | `PIO0_17` | Linha Analógica ADC (`EXP03`) | Header de Expansão J5.3 |
| 46 | `PIO0_18` | Recepção Serial UART (`RXD`) | Saída TXD do transceptor FT232RL |
| 47 | `PIO0_19` | Transmissão Serial UART (`TXD`) | Entrada RXD do transceptor FT232RL |
| 48 | `PIO1_16` | `EXP14` | Header de Expansão J7.7 |

</details>

---

## Balanço Elétrico & Consumo de Potência

A estimativa do consumo total do protótipo foi calculada considerando correntes máximas em regime contínuo:

| Subsistema / Componente | Tensão ($V$) | Corrente Máx. Estimada ($mA$) | Potência Ativa ($W$) |
| :--- | :---: | :---: | :---: |
| Microcontrolador NXP LPC11U14F | $3.3\text{ V}$ | $100\text{ mA}$ | $0.330\text{ W}$ |
| Transceptor USB-Serial FT232RL | $3.3\text{ V}$ | $25\text{ mA}$ | $0.082\text{ W}$ |
| Memória EEPROM 24LC512 | $3.3\text{ V}$ | $3\text{ mA}$ | $0.010\text{ W}$ |
| Módulo Display LCD 16×2 (com Backlight)| $5.0\text{ V}$ | $120\text{ mA}$ | $0.600\text{ W}$ |
| LEDs Indicadores (3x) | $3.3\text{ V}$ | $39\text{ mA}$ | $0.129\text{ W}$ |
| Carga de Expansão / Sensores (Reserva Máx.) | $3.3\text{ V} / 5.0\text{ V}$ | $\approx 600\text{ mA}$ | $\approx 3.080\text{ W}$ |
| **Total Máximo Projetado em Carga Plena** | ‒ | ‒ | **$\approx 4.23\text{ W}$** |

---

## Orçamento e Custos de Fabricação

- **Lote de Componentes Eletrônicos (BOM):** **US$ 29,54** (aquisição em distribuidores autorizados como Mouser e Digi-Key).
- **Manufatura das Placas (JLCPCB):** **US$ 2,00** (lote com 5 unidades em FR-4 dupla face, 1.6 mm, 1 oz cobre, acabamento HASL).
- **Logística e Envio Internacional:** **US$ 3,30** (frete econômico internacional).
- **Investimento Consolidado:** **US$ 34,84** (custo unitário de fabricação da placa avulsa de apenas US$ 1,06).

---

## Guia de Compilação e Gravação

### 1. Ferramentas Necessárias
- **KiCad EDA:** Versão 9.0.2 ou superior.
- **IDE C/C++:** MCUXpresso IDE ou Eclipse com GCC ARM Embedded (`arm-none-eabi-gcc`).
- **Gravador Serial:** **Flash Magic** (ferramenta oficial NXP para microcontroladores LPC).

### 2. Procedimento de Gravação via Bootloader ISP
1. Conecte a placa ao computador utilizando um cabo Mini-USB conectado à porta serial FTDI.
2. Segure pressionado o botão **`SW6` (ISP)**.
3. Pressione e solte o botão **`SW1` (RESET)**.
4. Solte o botão `SW6`. O microcontrolador entrará no bootloader ISP gravado em ROM.
5. Abra o **Flash Magic**, configure:
   - **Device:** `LPC11U14/201`
   - **COM Port:** Porta serial atribuída ao chip FTDI
   - **Baud Rate:** `115200`
   - **Interface:** None (ISP)
   - **Oscillator (MHz):** `12`
6. No campo *Hex File*, selecione o binário compilado localizado em `Código/PBLE02/Release/PBLE02.bin`.
7. Marque *Erase blocks used by Firmware* e clique em **Start** para regravar o microcontrolador.

---

## Estrutura de Diretórios do Repositório

```text
.
├── Código/
│   └── PBLE02/
│       ├── .cproject
│       ├── .project
│       ├── PBLE02.fmx
│       ├── configFlashMagic.fmx
│       └── src/
│           ├── ctl/               # Lógica de Controle, FSM, Temporizador, Eventos
│           │   ├── event.c / .h
│           │   ├── output.c / .h
│           │   ├── stateMachine.c / .h
│           │   ├── timer.c / .h
│           │   └── var.c / .h
│           ├── hardware/          # Drivers dos Periféricos de Baixo Nível
│           │   ├── ADC.c / .h
│           │   ├── DAC.c / .h
│           │   ├── EEPROM.c / .h
│           │   ├── ENCODER.c / .h
│           │   ├── LCD.c / .h
│           │   ├── LED.c / .h
│           │   ├── Memoria.c
│           │   ├── RTC.c / .h
│           │   ├── Serial.c / .h
│           │   └── Teclado.c / .h
│           ├── cr_startup_lpc11xx.c
│           ├── I2C.c / .h
│           ├── programa.c / .h    # Ponto de entrada (main) e laço operacional
│           ├── sysinit.c
│           └── util.c / .h
├── KiCad/
│   └── Projeto_Final/
│       ├── bom/
│       │   └── ibom.html          # Interactive HTML BOM (iBOM dinâmico)
│       ├── Footprints/            # Bibliotecas de footprints locais
│       ├── Projeto_Final.kicad_pcb # Layout da placa de circuito impresso
│       ├── Projeto_Final.kicad_sch # Esquema elétrico hierárquico
│       ├── Projeto_Final.kicad_pro # Arquivo de projeto do KiCad
│       └── sym-lib-table
├── docs/
│   └── images/                    # Imagens, renderizações 3D, diagramas e fotos
│       ├── pcb_3d_top_corrected.png
│       ├── pcb_3d_bottom_corrected.png
│       ├── pcb_3d_top_original.png
│       ├── fig01_circuito_alimentacao.png
│       ├── fig02_circuito_processamento_original.png
│       ├── fig03_circuito_processamento_corrigido.png
│       ├── fig04_circuito_interacao_original.png
│       ├── fig05_circuito_interacao_corrigido.png
│       ├── fig06_circuito_perifericos_original.png
│       ├── fig08_circuito_comunicacao_original.png
│       ├── fig09_circuito_comunicacao_corrigido.png
│       ├── fig10_erc_erros_originais.png
│       ├── fig11_erc_verificacao_corrigida.png
│       ├── drc_errors_original.png
│       ├── drc_report_corrected.png
│       ├── mcu_pinout_lpc11u14.png
│       ├── firmware_fsm_state_machine.png
│       └── uml_software_architecture.svg
├── Documentacao.pdf               # Relatório técnico completo da disciplina (66 páginas)
├── uml.svg                        # Diagrama UML original em vetor
├── .gitignore                     # Filtro de arquivos temporários e binários de build
├── LICENSE                        # Licença MIT
└── README.md                      # Documentação técnica consolidada do repositório
```

---

## Licença

Este projeto é disponibilizado sob os termos da licença **MIT**. Para maiores informações, consulte o arquivo [LICENSE](LICENSE).

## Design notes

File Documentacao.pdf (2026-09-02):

UNIVERSIDADE FEDERAL DE ITAJUBÁ

CAMPUS DE ITAJUBÁ

BOARD BRING-UP E VALIDAÇÃO DE PROTÓTIPOS ELETRÔNICOS

PBLE02 - RELATÓRIO DO PROJETO (GRUPO 1)

LEONARDO MENDONÇA COSTA

FABRICIO AUGUSTO ANTONIO

PEDRO HENRIQUE OLIVEIRA FRANCISCO

LUIS GUSTAVO RIBEIRO CHACON

ITAJUBÁ

2026

Grupo 1:

Leonardo Mendonça Costa – 2024001025 – Hardware

Fabricio Augusto Antonio – 2025000031 – Hardware

Pedro Henrique Oliveira Francisco – 2022003245 – Documentação

Luis Gustavo Ribeiro Chacon – 2025004890 – Software

AGRADECIMENTOS

Agradecemos à Universidade Federal de Itajubá (UNIFEI) e ao Instituto de

Engenharia de Sistemas e Tecnologia da Informação (IESTI) pelo suporte institucional e

infraestrutura. Agradecemos especialmente aos técnicos em eletrônica José Anderson

Reis e Nedson Joaquim Maia, membros da equipe técnica do IESTI no campus sede de

Itajubá, pelo apoio e suporte prático de bancada e laboratório, e ao Prof. Dr. Rodrigo

Maximiano Antunes de Almeida, professor adjunto do IESTI/UNIFEI, pelas valiosas

orientações, direcionamento e suporte técnico prestados durante a validação deste projeto.

RESUMO

Este trabalho apresenta o relatório de validação do protótipo eletrônico desenvolvido para

a disciplina de PBLE02. O sistema baseia-se no microcontrolador ARM Cortex-M0

LPC11U14F, após migração da família LPC1114. O projeto compreende os cinco

subcircuitosintegrados: alimentação, processamento, interação com o usuário, periféricos

e comunicação. O documento detalha as etapas de montagem física da PCI, a realização

de correções de hardware através de jumpers e cortes de trilhas, os ajustes dos circuitos.

Apresenta-se o firmware de validação modular orientado a casos de uso estruturado em

máquina de estados. Ao final, a análise de custos do protótipo totalizou US$ 29,54 para

componentes e US$ 5,30 para fabricação da placa, confirmando o sucesso da integração

física e lógica do sistema eletrônico.

LISTA DE ILUSTRAÇÕES

LISTA DE TABELAS

LISTA DE ABREVIATURAS E SIGLAS

ARM | Advanced RISC Machines
PCI | Placa de Circuito Impresso
PCB | Printed Circuit Board
USB | Universal Serial Bus
UART | Universal Asynchronous Receiver-Transmitter
ISP | In-System Programming
GPIO | General Purpose Input/Output
EEPROM | Electrically Erasable Programmable Read-Only Memory
I2C | Inter-Integrated Circuit
JTAG | Joint Test Action Group
DRC | Design Rule Check
ERC | Electrical Rule Check

LISTA DE SÍMBOLOS

Ω | Ohm (unidade de resistência elétrica)
F | Farad (unidade de capacitância elétrica)
V | Volt (unidade de tensão elétrica)
A | Ampere (unidade de corrente elétrica)
W | Watt (unidade de potência elétrica ativa)
Hz | Hertz (unidade de frequência)

SUMÁRIO

### 1 INTRODUÇÃO

Este documento descreve o processo de validação de um protótipo eletrônico,

desenvolvido como atividade prática da disciplina PBLE02. O objetivo principal do

projeto consiste na transposição de um projeto esquemático para uma Placa de Circuito

Impresso (PCI) física, seguida pela implementação do firmware necessário para a

operação e verificação de todos os subcircuitos integrados.

O sistema baseia-se em um microcontrolador de arquitetura ARM Cortex-M0,

originalmente especificado na família LPC11xx. Durante a execução deste projeto, foi

realizada uma migração para o componente NXP LPC11U14F, visando a compatibilidade

de componentes. O escopo de desenvolvimento contempla cinco subcircuitos

interconectados: alimentação, processamento, interação com o usuário, periféricos e

comunicação serial.

O subcircuito de alimentação é responsável por converter a tensão de entrada (7V

a 12V DC) em tensões de operação estáveis de 3.3V e 5V DC. O subcircuito de

processamento gerencia a execução do firmware, controlando a lógica do sistema e

interfaceando com os demais módulos. O módulo de interação inclui periféricos como

display LCD alfanumérico, chaves tácteis e encoder rotativo, essenciais para a interface

homem-máquina. O sistema conta com memória não-volátil (EEPROM) para

armazenamento de dados via barramento I2C e um transceptor USB-UART para

viabilizar a comunicação com dispositivos externos.

A proposta técnica deste projeto abrange as etapas de montagem, verificação de

integridade física da PCI, ajuste de trilhas através de jumpers para correção de roteamento

e a implementação de drivers no firmware. O desenvolvimento do código embarcado

exigiu a manipulação direta de registradores para a configuração de pinos de propósito

geral e o ajuste de protocolos de comunicação.

Este manual documenta as modificações realizadas durante a fase de montagem,

detalhando as divergências entre o projeto teórico inicial e a implementação física final.

São apresentados os mapas de pinos atualizados, a análise de consumo de energia, o

relatório de erros de projeto (DRC/ERC) e o levantamento de custos para viabilizar a

produção desta unidade. O resultado demonstra a capacidade de integração de

componentes eletrônicos e software.

### 2 REQUISITOS

Os requisitos técnicos que guiaram o projeto, as especificações dimensionais e o

comportamento lógico do sistema são detalhados na Tabela 1.

Tabela 1 ‒ Requisitos técnicos

Requisito | Descrição
R1 - Características físicas da placa de circuito impresso | Dimensões máximas estruturais limitadas a 8×8cm², utilizando placa de circuito impresso do tipo dupla face de condução. A face inferior deve atuar integralmente como plano de terra (GND). Deve conter furos dedicados para fixação mecânica nas extremidades e identificação clara em serigrafia de todos os componentes, pinagens de conectores.
R2 - Alimentação | Circuito projetado para receber tensões externas na faixa de 7V a 12V através de conector de energia. Deve efetuar a regulação interna para disponibilizar barramentos estáveis de 3.3V e 5V. Inclui diodo Schottky para proteção contra inserção de tensão reversa e sinalização visual ativa por LED de status.
R3 - Operação | Processamento digital central executado por microcontrolador de arquitetura ARM Cortex-M0 de 32 bits, com suporte a rotinas de clock estável via cristal externo, pinos de depuração e controle de reinicialização de hardware.
R4 - Interação com o usuário | Interface física de controle e monitoramento direta contendo chaves tácteis configuráveis, LEDs de sinalização visual, encoder rotativo incremental com chave integrada e display alfanumérico LCD de 16x2 caracteres para exibição de dados e estados.
R5 - Periféricos e expansão | Presença de memória não-volátil do tipo EEPROM conectada via barramento serial I2C para retenção de dados locais. Inclusão de barras de expansão (headers) para

acesso direto aos pinos de entrada e saída (I/O) não utilizados pelo sistema base.

R6 - Comunicação | Subsistema de comunicação serial assíncrona baseado em transceptor integrado USB-UART dedicado para conversão de níveis e tráfego de dados bidirecional com o computador via linhas RX e TX.
R7 - Embarcado de validação | Desenvolvimento de firmware modular específico para a validação periférica completa do hardware, baseado em uma arquitetura orientada a casos de uso e controle de fluxo gerenciado por máquina de estados.
R8 - Espaçamento e dimensões de trilhas e afins | Dimensionamento elétrico de larguras de trilhas para alimentação e linhas de sinal, respeitando limites de capacidade de corrente, isolação física e minimização de ruídos em conformidade com as diretrizes de fabricação da PCI. Fonte: Autores (2026).

### 3 AMBIENTE DE DESENVOLVIMENTO

Para a elaboração do projeto esquemático, do layout da placa de circuito impresso

e para a programação e validação do firmware do sistema, utilizou-se o conjunto de

ferramentas especificado na Tabela 2.

Tabela 2 ‒ Recursos de desenvolvimento

Item | Recurso / Descrição | Versão
1 | KiCad - Automação de
| design eletrônico (EDA) | 9.0.2
2 | MPLAB X IDE - Programação embarcada (Linguagem C)

6.0.0

Fonte: Autores (2026).

### 4 ESQUEMA ELÉTRICO

Nesta seção é detalhado o esquema elétrico do circuito, subdividido em blocos

funcionais conforme os requisitos do projeto. As imagens representam as estruturas do

circuito antes da montagem e correções físicas realizadas em bancada.

4.1 CIRCUITO DE ALIMENTAÇÃO

O circuito de alimentação (Figura 1) recebe energia de uma fonte DC externa na

faixa de 7V a 12V através de um conector do tipo Jack PJ-002A. Um diodo Schottky

1N5819HW-7-F é posicionado em série com a entrada de alimentação para proteger o

hardware contra danos causados por inserção de polaridade reversa.

A regulação de tensão é efetuada de maneira integrada por dois reguladores

lineares da família LD1117: um modelo LD1117DT50TR converte a tensão de entrada

para um barramento estável de 5.0V DC, e um modelo LD1117S33TR fornece regulação

subsequente para 3.3V DC (alimentação do microcontrolador e transceptor). Capacitores

eletrolíticos de filtro (10µF) e capacitores de desacoplamento cerâmicos (220nF)

garantem a supressão de ruídos de alta frequência e a estabilidade das linhas. Um LED

acoplado em série com um resistor de 1kΩ monitora ativamente e indica visualmente

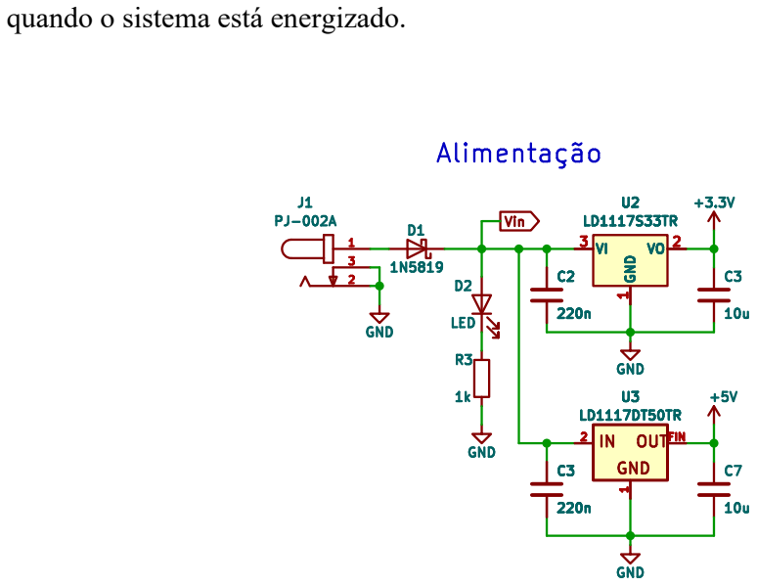
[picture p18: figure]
quando o sistema está energizado.

Figura 1 ‒ Circuito de Alimentação

Fonte: Adaptado de Byanca (2023).

4.2 CIRCUITO DE PROCESSAMENTO

### 4.2.1 Circuito Original

O subcircuito de processamento (Figura 2) gerencia toda a lógica operacional e o

fluxo de dados da placa. Originalmente projetado para o microcontrolador

LPC1114FBD48, o projeto de foi migrado para a versão NXP LPC11U14F (família

LPC11Uxx) com encapsulamento LQFP de 48 pinos. O microcontrolador opera com um

circuito de clock externo baseado em um cristal de quartzo de 12 MHz associado a dois

capacitores de carga.

O circuito possui conectividade física dedicada para gravação e depuração em

tempo real através de uma interface JTAG de 10 pinos. Um pino de reinicialização

(RESET) está interligado a uma chave táctil (SW1) com uma linha de filtro RC de

constante de tempo longa, exigindo pressionamento estável para o reset mecânico.

Adicionalmente, há uma chave de controle para ativação manual do modo ISP (In-System

Programming) que permite programar o chip via interface serial nativa.

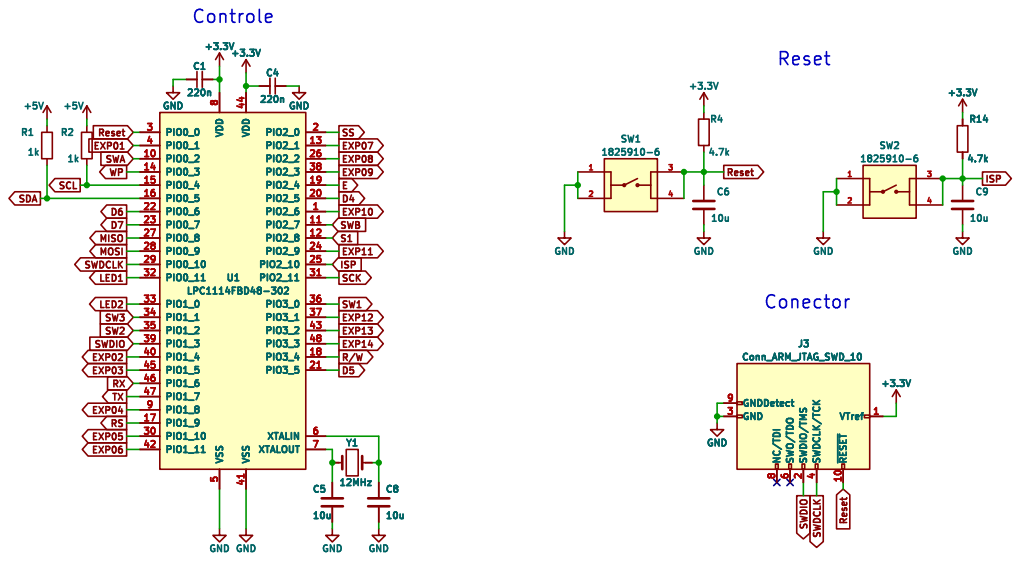
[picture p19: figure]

Figura 2 ‒ Circuito de Processamento original

Fonte: Adaptado de Byanca (2023).

### 4.2.2 Circuito corrigido

Foram efetuadas modificações físicas no circuito de processamento para adequação

de layout e funcionalidade:

- Botão SW6 (Função ISP): A chave táctil SW6 (ISP) foi desconectada do pino 25 original

do microcontrolador e interligada por um jumper ao pino 4 (PIO0_1) do microcontrolador

LPC11U14F, que é a porta física de inicialização (ISP) desta família.

- Capacitores de Carga do Cristal: Os capacitores de carga do cristal oscilador de

12 MHz (C25 e C26) foram erroneamente projetados como 10µF no esquema original,

impedindo a oscilação do clock do sistema. Substituiu-se esses componentes por

capacitores cerâmicos de 18pF, restabelecendo a partida correta do clock.

- Botão SW1 (Função Reset): O botão SW1 atua diretamente no pino 3 (Reset do microcontrolador), não demandando modificações físicas.
- Expansão EXP01: A trilha que originalmente chegava no pino físico 25 (antigo ISP) foi

redirecionada e conectada ao Pino 1 do conector J5 (EXP01).

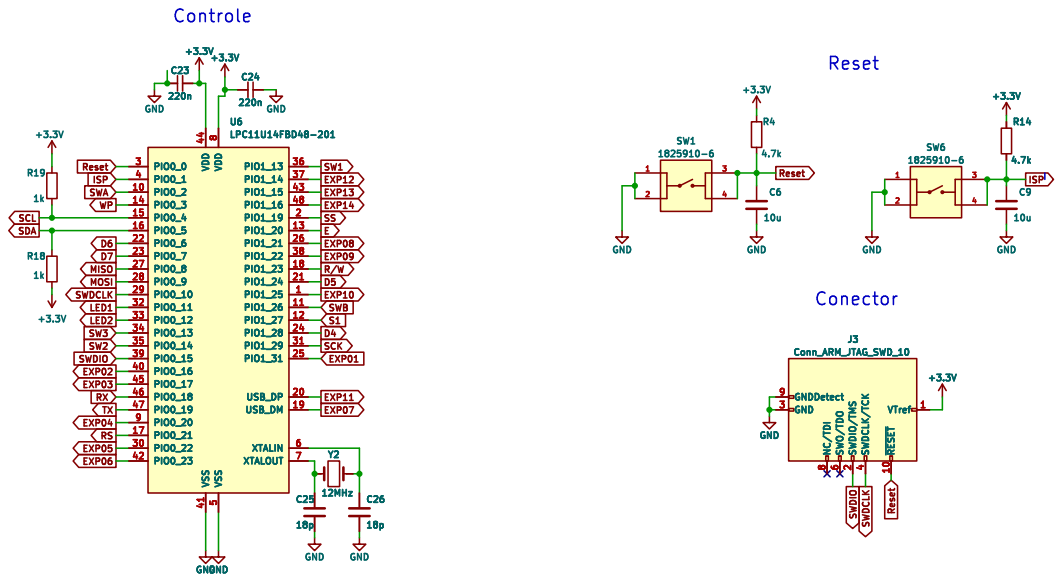
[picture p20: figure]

Figura 3 ‒ Circuito de Processamento corrigido

Fonte: Autores (2026).

4.3 CIRCUITO DE INTERAÇÃO

### 4.3.1 Circuito Original

O circuito de interação inicial (Figura 4) é composto pelas chaves de navegação

física tácteis SW3 a SW6, sinalizadores de status visuais baseados em LEDs (D2 a D4) e

pelo encoder rotativo incremental (SW7) com clique integrado. Para viabilizar a

visualização de dados, o circuito integra um display LCD alfanumérico padrão de 16x2

caracteres. O encoder contava com um filtro RC passivo com capacitores de 10µF em

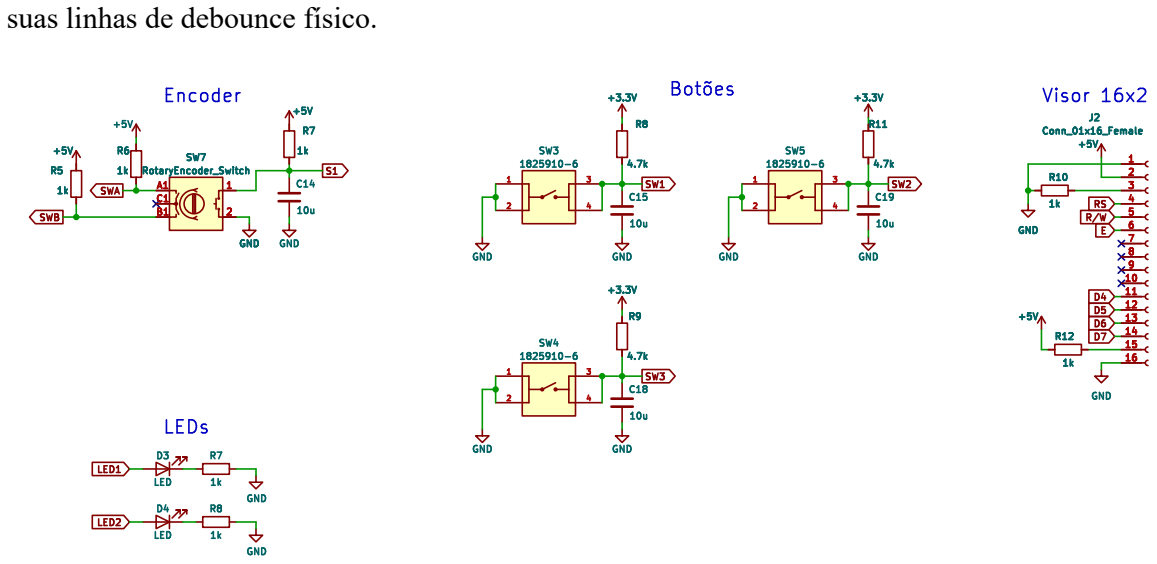
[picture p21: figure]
suas linhas de debounce físico.

Figura 4 ‒ Circuito de Interação original

Fonte: Adaptado de Byanca (2023).

### 4.3.2 Circuito corrigido

Foram identificadas incompatibilidades e gargalos físicos que demandaram as

seguintes correções de hardware (representadas na Figura 5):

- Jumpers de Roteamento de Controle do LCD: O display LCD demandou

redirecionamento físico de trilhas por conflitos estruturais com a pinagem do

LPC11U14F. O sinal ENABLE (E) do display foi fisicamente cortado e religado ao pino

13 (PIO1_20), e o pino de dados DATA 4 (DB4) foi remapeado para o pino 24 (PIO1_28).

- Filtro de Debounce do Encoder: Os capacitores eletrolíticos de 10µF originais

causavam atrasos excessivos de leitura devido à constante de tempo alta. Seguindo as diretrizes do datasheet do fabricante do encoder rotativo (Bourns), os capacitores foram

alterados para componentes cerâmicos de 10nF, otimizando o debounce físico e

restabelecendo a sensibilidade às transições dos canais A e B.

- Dimensionamento dos Resistores dos LEDs: Os resistores de polarização dos

LEDs (D2, D3 e D4), projetados com 1kΩ no esquema original, limitavam a corrente de

operação em torno de 1,3 mA, tornando a intensidade luminosa insuficiente. Modificou-

se o valor desses resistores para 100Ω, estabelecendo a corrente de operação em

aproximadamente 13 mA para permitir correta sinalização visual sem sobrecarga.

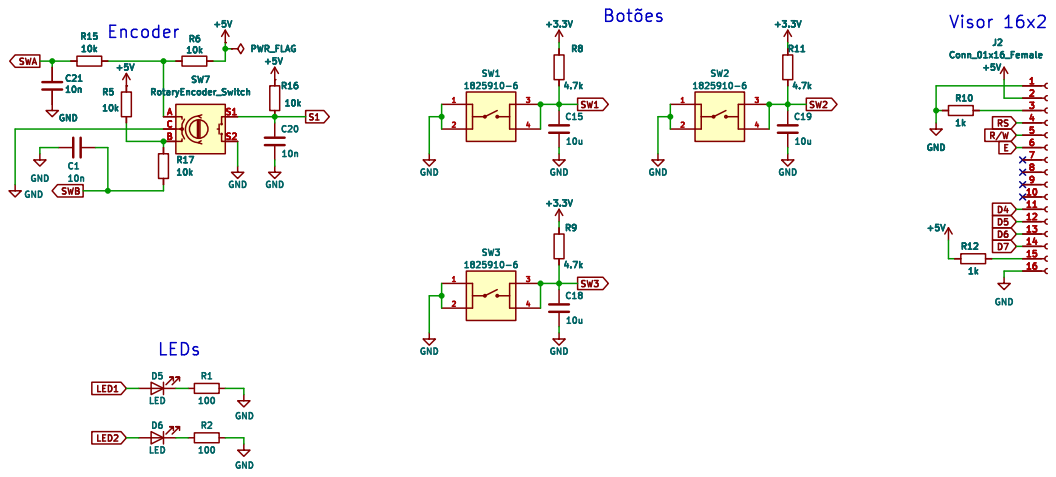
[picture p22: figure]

Figura 5 ‒ Circuito de Interação corrigido

Fonte: Autores (2026).

4.4 CIRCUITO DE PERIFÉRICOS

### 4.4.1 Circuito Original

O circuito de periféricos (Figura 6) estende a funcionalidade do microcontrolador

principal fornecendo armazenamento não-volátil de dados e acesso físico de expansão.

Ele compreende uma memória EEPROM serial externa modelo 24LC512, com

capacidade de 512 Kbits, conectada via barramento serial de dois fios I2C. As linhas SCL

(Clock) e SDA (Dados) possuem resistores de pull-up externos de 1kΩ para assegurar os

níveis lógicos corretos do protocolo.

Além da memória, o bloco disponibiliza headers de pinos macho de passo de 2,54

mm (barramentos J4 a J8). Estes conectores expõem diretamente todos os pinos de E/S analógicos e digitais não utilizados pela aplicação principal, gerando extensibilidade

física para conexões a circuitos periféricos de suporte.

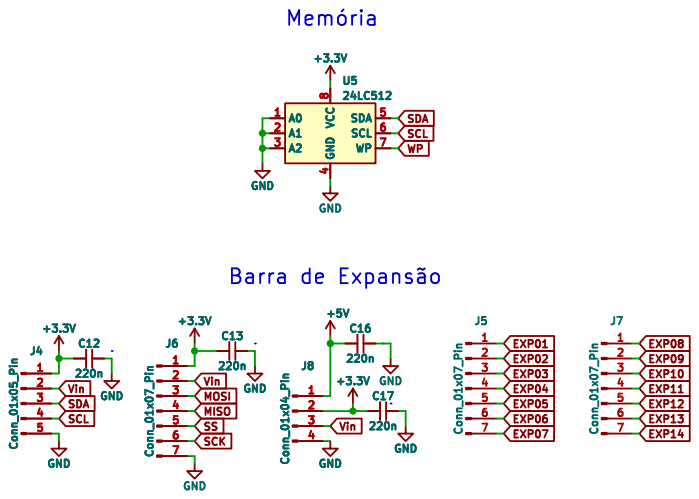
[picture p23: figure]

Figura 6 ‒ Circuito de Periféricos original

Fonte: Adaptado de Byanca (2023).

### 4.4.2 Correção no circuito

Durante a validação, foi necessária a seguinte modificação no circuito de

periféricos para adequar as tensões de sinal:

- Interface I2C e Níveis de Tensão: Os resistores de pull-up R1 e R2 (linhas SDA e SCL)

originalmente ligados à malha de 5V foram isolados e alimentados com 3.3V. A

modificação física consistiu na soldagem de um jumper partindo do Pino 8 (VCC de 3.3V)

da memória EEPROM (U5) até os resistores R1 e R2, de forma a adequar as tensões do

barramento I2C aos níveis lógicos tolerados pelo microcontrolador (3.3V) para proteção

e estabilidade da comunicação.

4.5 CIRCUITO DE COMUNICAÇÃO

O subcircuito de comunicação (Figura 8) é responsável por estabelecer a

comunicação serial assíncrona entre o microcontrolador e a estação de desenvolvimento

externa. Ele se baseia no transceptor circuito integrado conversor USB-UART modelo

FT232RL fabricado pela FTDI.

O transceptor realiza o interfaceamento dos níveis seriais assíncronos digitais de

3.3V (linhas de transmissão TXD e recepção RXD do microcontrolador) com a interface

física serial do conector Mini-USB Tipo B. O circuito contém capacitores de filtro local

na linha VCC para imunidade a ruídos gerados no cabo de comunicação USB do host.

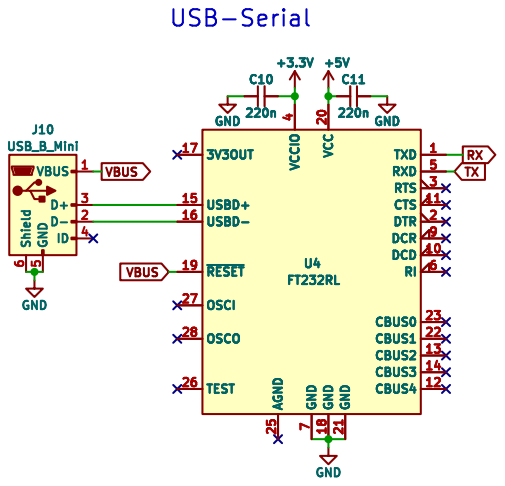
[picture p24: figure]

Figura 8 ‒ Circuito de Comunicação USB-Serial

Fonte: Adaptado de Byanca (2023).

### 4.5.1 Correção no circuito

A trilha que conectava a linha VBUS do conector USB à alimentação do

transceptor FT232RL e ao barramento interno da placa foi cortada. A modificação física

eliminou a alimentação cruzada do circuito de comunicação a partir da fonte de energia

interna de 5V da placa quando o cabo USB está desconectado, garantindo isolamento de

potência.

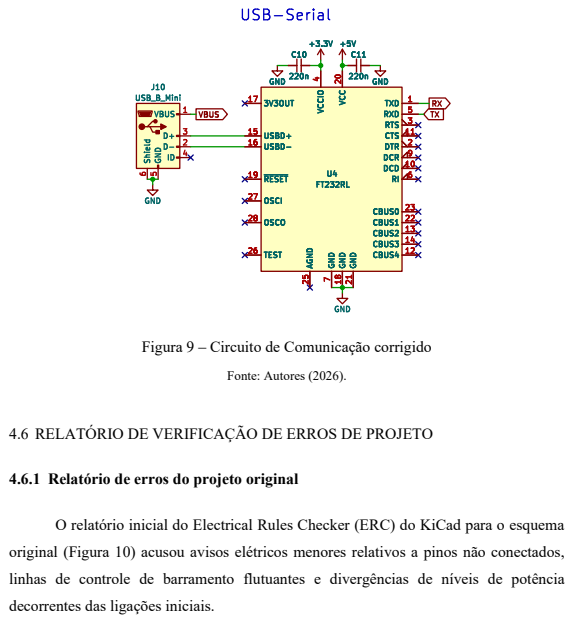
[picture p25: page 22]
Fonte: Autores (2026).

Figura 9 ‒ Circuito de Comunicação corrigido

4.6 RELATÓRIO DE VERIFICAÇÃO DE ERROS DE PROJETO

4.6.1 Relatório de erros do projeto original

O relatório inicial do Electrical Rules Checker (ERC) do KiCad para o esquema

original (Figura 10) acusou avisos elétricos menores relativos a pinos não conectados,
linhas de controle de barramento flutuantes e divergências de níveis de potência
decorrentes das ligações iniciais.

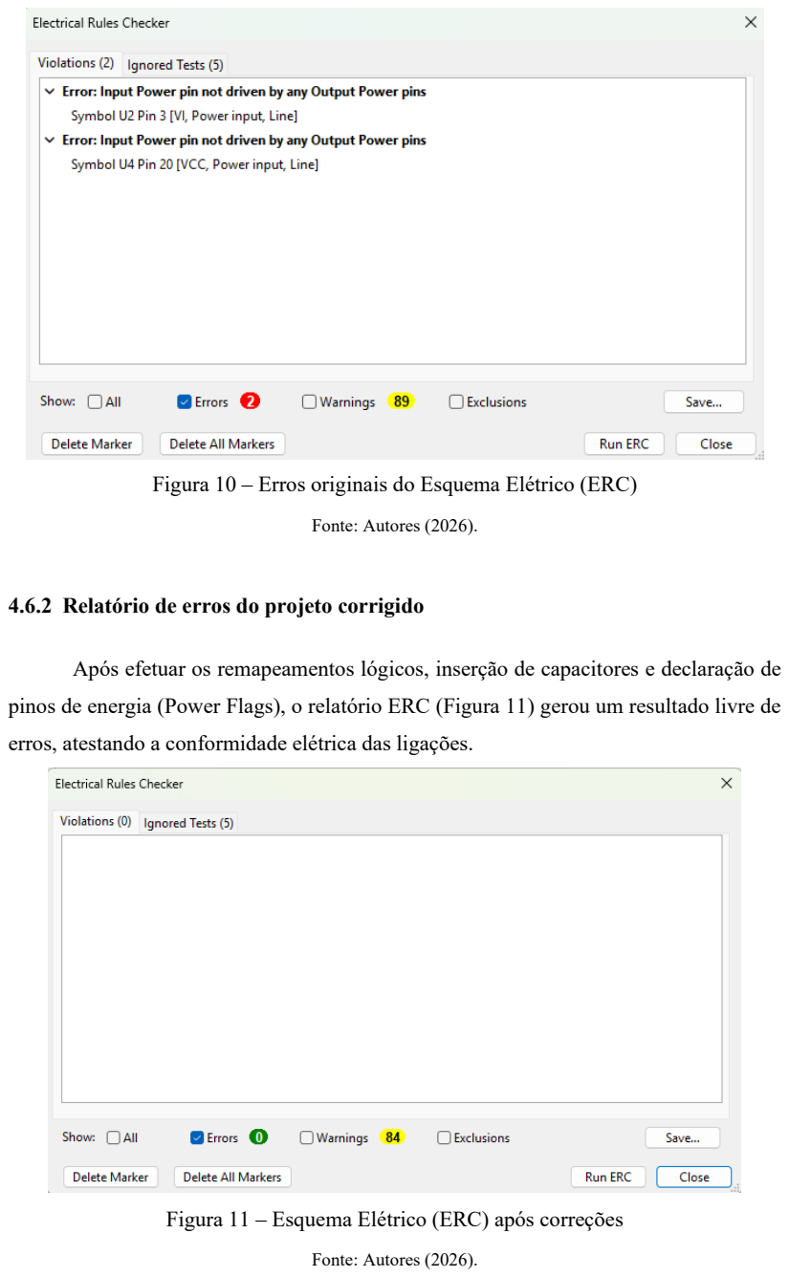
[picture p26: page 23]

Figura 10 ‒ Erros originais do Esquema Elétrico (ERC)

Fonte: Autores (2026).

### 4.6.2 Relatório de erros do projeto corrigido

Após efetuar os remapeamentos lógicos, inserção de capacitores e declaração de

pinos de energia (Power Flags), o relatório ERC (Figura 11) gerou um resultado livre de

erros, atestando a conformidade elétrica das ligações.

Figura 11 ‒ Esquema Elétrico (ERC) após correções

Fonte: Autores (2026).

### 5 PLACA DE CIRCUITO IMPRESSO

O desenvolvimento físico da placa de circuito impresso (PCI) seguiu diretrizes

para evitar ruídos e garantir a imunidade a interferências eletromagnéticas. O roteamento

foi separado em blocos lógicos estruturados, utilizando uma arquitetura dupla face com

plano de terra (GND) integral na face inferior e as conexões de alimentação (3.3V/5V) e

sinais dispostos preferencialmente na face superior.

A Tabela 3 destaca os requisitos de layout aplicados para a confecção física da

PCI.

Tabela 3 ‒ Requisitos de design da PCI

Requisito | | Descrição

R1 - Características físicas da placa de circuito impresso

Dimensões limitadas a 8×8cm², uso de dupla face condutiva FR4 com plano de terra sólido no lado inferior para atenuação de ruídos de acoplamento elétrico. Furos estruturais nas extremidades e legenda descritiva de componentes no lado de solda
| | superior.

R8 - Espaçamento e dimensões de trilhas e afins

Larguras das trilhas calculadas para a capacidade máxima de corrente. Trilhas de alimentação dimensionadas com 1.0mm e linhas de sinal lógico com 0.3mm. Respeito ao limite mínimo de isolamento físico de 0.25mm para evitar fuga de corrente ou
| | curtos-circuitos.
| Fonte: Autores (2026).

A Tabela 4 compila todos os componentes eletrônicos montados fisicamente no

protótipo, destacando seus encapsulamentos e fabricantes de referência.

Tabela 4 ‒ Lista de especificações físicas dos componentes

Componente / Item | Modelo / Encapsulamento | Fabricante de referência
Processador (U1) | LPC11U14F / LQFP48 | NXP Semiconductors
Relógio de tempo real | Circuitos de Clock / RTC Interno | Genérico

Conversor Digital-Analógico Barramento / R-2R ou Equivalente

Genérico

Resistores | Película de Carbono / SMD
| 0805

Stackpole / YAGEO

Capacitores cerâmicos | MLCC 10nF e 220nF / SMD
| 0805

KEMET / Murata

Capacitores polarizados | Tântalo ou Eletrolítico 10µF / SMD 1206

Murata / Genérico

Barra de pinos | Headers Macho e Fêmea .100" (2.54mm)

TE Connectivity / Sullins

Conector de energia | DC Power Jack PJ-002A | CUI Devices
Diodos emissores de luz (LEDs) | LED Verde e Vermelho SMD / SMD 0805 | Lite-On Electronics
Conector USB (J10) | Receptáculo Mini USB 2.0 Tipo B SMD

TE Connectivity

Chaves tácteis (SW1-SW6) Tactile Switch 1825910-6 / PTH

TE Connectivity

Reguladores de tensão (U2,
U3)

LD1117S33TR e
LD1117DT50TR / SOT-223 /
DPAK

STMicroelectronics

Cristal (Y1) | Cristal de Quartzo 12 MHz / HC-49/US SMD

CTS Electronic Components

Diodo retificador (D1) | 1N5819HW-7-F Schottky / SOD-123

Diodes Incorporated

Display LCD (J9) | Visor Alfanumérico 1602A | Genérico
Transceptor USB-serial (U4) | CI Interface USB UART FT232RL / SSOP28 | FTDI Chip

Fonte: Autores (2026).

5.1 DESENHO DA PLACA DE CIRCUITO IMPRESSO

### 5.1.1 Desenho original

A Figura 12 ilustra a visualização 3D do layout original, mostrando a disposição

inicial dos blocos de componentes e conectores antes das modificações físicas.


Figura 12 ‒ Vista superior 3D original

Fonte: Byanca (2023).

### 5.1.2 Desenho corrigido

As Figuras 11 e 12 representam a placa com correções integradas de layout,

incluindo a reestruturação física das trilhas de alimentação e desacoplamentos

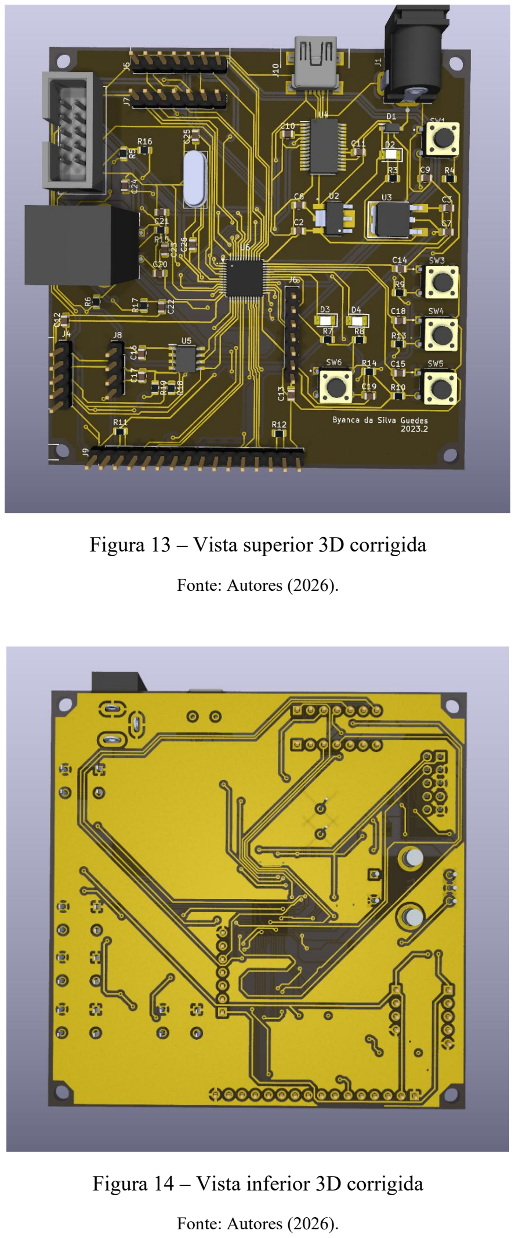
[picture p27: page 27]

Figura 13 ‒ Vista superior 3D corrigida

Fonte: Autores (2026).

Figura 14 ‒ Vista inferior 3D corrigida

Fonte: Autores (2026).

5.2 RELATÓRIO DE VERIFICAÇÃO DE ERROS DE PROJETO

### 5.2.1 Relatório original

O DRC da placa original (Figura 15) registrou falhas de conexão de ilhas de plano

de terra, curtos-circuitos provocados pela sobreposição de vias e erro de largura nas

conexões.


Figura 15 ‒ Relatório de erros de regras de design (DRC) da PCI original

Fonte: Autores (2026).

### 5.2.2 Relatório corrigido

Com o remapeamento lógico e o ajuste manual das conexões, o relatório DRC

corrigido (Figura 16) obteve uma verificação livre de erros nas regras elétricas de e

isolamento físico.


Figura 16 ‒ Relatório de erros de regras de design (DRC) da PCI corrigido

Fonte: Autores (2026).

### 6 CARACTERÍSTICAS GERAIS

Nesta seção serão encontradas as características gerais da placa, onde poderão ser

observados alguns detalhes a mais sobre informações da placa.

6.1 MAPAS DE PINOS

A relação física entre os pinos do microcontrolador LPC11U14F e as suas funções

associadas no firmware de validação são descritas na Tabela 5. O mapa do chip é ilustrado

na Figura 17.

Tabela 5 ‒ Mapa de pinos do microcontrolador LPC11U14F

Pino | Porta | Função e pino
1 | PIO1_25 | EXP10 (J7.3)
2 | PIO1_19 | SS (J6.5)
3 | PIO0_0 | Reset (SW1)
4 | PIO0_1 | ISP (SW6)
5 | VSS | GND
6 | XTALIN | Cristal 12MHz (Pino 1)
7 | XTALOUT | Cristal 12MHz (Pino 3)
8 | VDD | 3.3V
9 | PIO0_20 | EXP04 (J5.4)
10 | PIO0_2 | SWA (SW7.A1)
11 | PIO1_26 | SWB (SW7.B1)
12 | PIO1_27 | S1 (SW7.1)
13 | PIO1_20 | E (J9.6)
14 | PIO0_3 | WP (U5.7)

15 | PIO0_4 | EEPROM I2C (SCL) - U5.6 (3.3V)
16 | PIO0_5 | EEPROM I2C (SDA) - U5.5 (3.3V)
17 | PIO0_21 | RS (J9.4)
18 | PIO1_23 | R/W (J9.5)
19 | USB_DM | EXP07 (J5.7)
20 | USB_DP | EXP11 (J7.4)
21 | PIO1_24 | D5 (J9.12)
22 | PIO0_6 | D6 (J9.13)
23 | PIO0_7 | D7 (J9.14)
24 | PIO1_28 | D4 (J9.11)
25 | PIO1_31 | EXP01 (J5.1)
26 | PIO1_21 | EXP08 (J7.1)
27 | PIO0_8 | MISO (J6.4)
28 | PIO0_9 | MOSI (J6.3)
29 | PIO0_10 | SWDCLK (J3.4)
30 | PIO0_22 | EXP05 (J5.5)
31 | PIO1_29 | SCK (J6.6)
32 | PIO0_11 | LED1 (D3.2)
33 | PIO0_12 | LED2 (D4.2)
34 | PIO0_13 | SW3 (SW5.3)
35 | PIO0_14 | SW2 (SW4.3)
36 | PIO1_13 | SW1 (SW3.3)

37 | PIO1_14 | EXP12 (J7.5)
38 | PIO1_22 | EXP09 (J7.2)
39 | PIO0_15 | SWDIO (J3.2)
40 | PIO0_16 | EXP02 (J5.2)
41 | VSS | GND
42 | PIO0_23 | EXP06 (J5.6)
43 | PIO1_15 | EXP13 (J7.6)
44 | VDD | 3.3V
45 | PIO0_17 | EXP03 (J5.3)
46 | PIO0_18 | RX (U4.1)
47 | PIO0_19 | TX (U4.5)
48 | PIO1_16 | EXP14 (J7.7)
| Fonte: Autores (2026).


Figura 17 ‒ Diagrama de pinos do microcontrolador LPC11U14F

Fonte: NXP Semiconductors (2026).

A interface do potenciômetro e sua pinagem de entrada física nas barras de

expansão são mostradas na Tabela 6.

Tabela 6 ‒ Mapa de pinos de interface

Componente respectivo e
pino
Interface e respectivo pino | Polaridade
J6 (Expansão) - Pino 5 | 3V3 - (Pino 1) | Positiva (+)
J5 (Expansão) – Pino 3 | Sinal do cursor - (EXP03, Pino 30) | -
J6 (Expansão) - Pino 6 | GND – (Pino 3) | Negativa (-)
| Fonte: Autores (2026).

6.2 ALIMENTAÇÃO E CONSUMO

O balanço elétrico e a estimativa de consumo de corrente e potência ativa

calculados para o protótipo eletrônico, baseados nas correntes máximas especificadas nos

datasheets de cada componente, encontram-se compilados na Tabela 7. O consumo de

potência total estimado para a placa sob operação máxima é de 4,23 W.

Tabela 7 ‒ Consumo de corrente e potência estimado

Componente | Corrente Estimada | Consumo de Potência
Microcontrolador (LPC11U14F) | 100 mA | 0.33 W

Transceptor USB-Serial
(FT232RL)
15 mA | 0.075 W

Memória EEPROM
(24LC512)
400 µA | 0.0013 W

Diodos Emissores de Luz
(LEDs)
30 mA | 0.099 W

Conector USB B mini (Carga de Barramento)

1 A | 3.3 W

Botões Tácteis | 50 mA | 0.165 W
Regulador 3.3V (LD1117S33TR) | 10 mA | 0.12 W

Regulador 5V
(LD1117DT50TR)
10 mA | 0.12 W
Encoder Rotativo | 10 mA | 0.02 W
Total Estimado | - | 4.23 W
| Fonte: Autores (2026).

### 7 PROGRAMA EMBARCADO DE VALIDAÇÃO

O firmware foi desenvolvido com foco na validação funcional de todos os barramentos de hardware. A arquitetura baseia-se em uma Máquina de Estados Finitos hierárquica e orientada a eventos, implementada via estrutura de controle polling com switch-case.

7.1 MODELO DE OPERAÇÃO GERAL

O fluxo de estados, ilustrado na Figura 18, compreende a seguinte estrutura:

- STATE_POWER_ON: Estado inicial energizado. A transição para a etapa subsequente ocorre mediante a liberação do barramento de reset (EV_HW_RST_RELEASE).
- STATE_INIT: Configura registradores e periféricos. Transita para STATE_ACTIVE mediante sucesso na inicialização (EV_BOOT_SUCCESS) ou para STATE_FAULT em caso de falha (EV_BOOT_FAIL).
- STATE_FAULT: Estado de interrupção por erro. Acessado por falhas de inicialização, exceções de hardware (EV_HW_EXCEPTION) ou erros de comunicação I2C (EV_I2C_ERR). A saída exige o evento de reset físico (botão SW1), reiniciando o fluxo em STATE_INIT.
- STATE_ACTIVE: Super-estado operacional que encapsula a interface do usuário (IHM), subdividido em:
- STATE_UI_IDLE: Modo de espera. Acessado após o evento de timeout (EV_TIMEOUT). A detecção de qualquer interação (EV_ANY_KEY) retorna o sistema para STATE_NAV_MAIN.
- STATE_NAV_MAIN: Gerencia a navegação cíclica entre STATE_HORAS, STATE_ALARME, STATE_SENSOR e STATE_IDIOMA. A alternância de estados é comandada por EV_UP (SW5, sentido horário) e EV_DOWN (SW3, sentido anti-horário). O acesso aos subníveis de edição ou leitura ocorre via EV_ENTER (SW4).
- STATE_PARAM_EDIT: Estado de modificação de parâmetros. Redireciona para STATE_MUDAR_HORAS e STATE_MUDAR_IDIOMA (ajustes únicos), ou para STATE_ALARME_L no ajuste de alarme. Em STATE_ALARME_L, o evento EV_ENTER (SW4) transita para STATE_ALARME_H. Nestes estados, a rotação do encoder (EV_ENC_ROT_CW para incrementar e EV_ENC_ROT_CCW para decrementar) ajusta os valores em memória RAM. O evento EV_CANCEL (clique do encoder) aborta a edição, enquanto EV_ENTER (SW4) finaliza a operação e transita para STATE_MEM_SAVE.

- STATE_MEM_SAVE: Executa a gravação de dados na memória EEPROM. A conclusão da escrita (EV_I2C_WRITE_OK) retorna o fluxo para STATE_NAV_MAIN.
- STATE_OUT_OF_RANGE: Estado de monitoramento de segurança. Acessado a partir de estados de leitura quando os valores do sensor ultrapassam os limites definidos. Este estado prioriza a sinalização visual de alerta até que os valores retornem à faixa nominal, momento em que o sistema transita de volta para STATE_HORAS.


Figura 18 ‒ Diagrama da Máquina de Estados do Firmware

Fonte: Autores (2026).

7.2 ARQUITETURA

A Figura 19 apresenta o diagrama UML lógico do firmware.

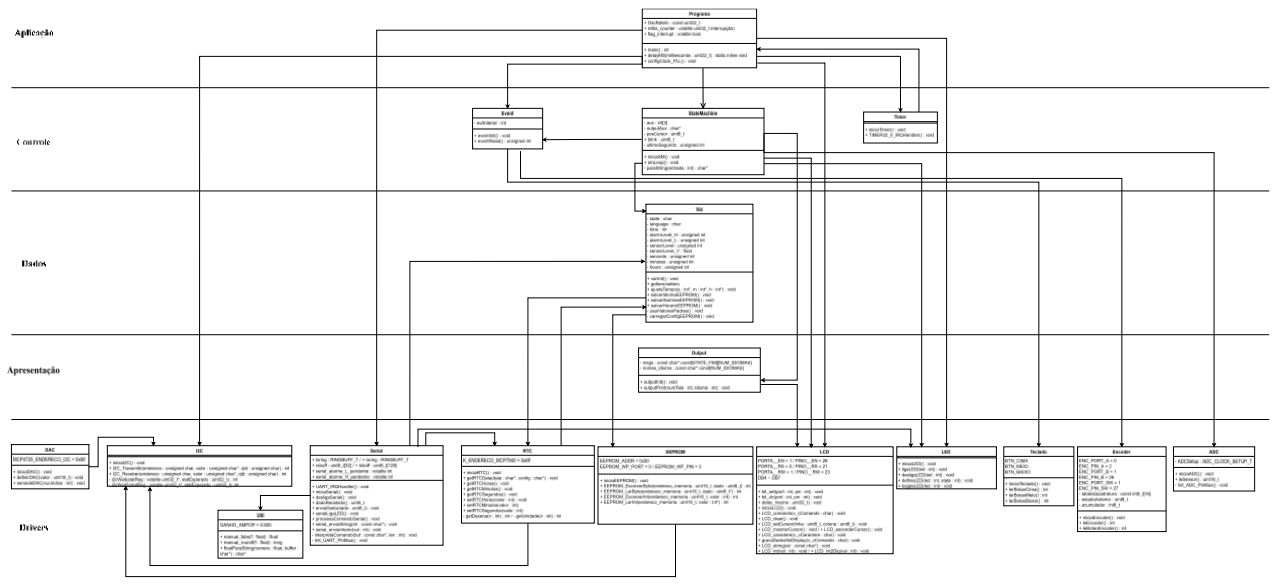
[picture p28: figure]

Figura 19 ‒ Diagrama UML da Arquitetura do Software

Fonte: Autores (2026).

7.3 CASOS DE USO

A interação do usuário com a placa nos menus do display ocorre através dos

botões físicos:

- Navegação Cíclica (STATE_NAV_MAIN): O usuário navega entre os menus

de visualização de dados (Horas, Alarme, Leitura do Sensor e Idioma) utilizando os

botões táteis SW3 (gera o evento EV_DOWN) e SW5 (gera o evento EV_UP), operando

em lógica de carrossel bidirecional.

- Edição de Parâmetros (STATE_PARAM_EDIT): O pressionamento do botão

tátil SW4 (evento EV_ENTER) habilita a edição de valores de ajuste. O incremento e

decremento das variáveis na memória RAM (como horas, minutos ou limites do alarme)

é | realizado | pela | rotação | horária | (EV_ENC_ROT_CW) | ou | anti-horária

(EV_ENC_ROT_CCW) do encoder rotativo SW7, proporcionando ajuste preciso e

intuitivo.

- Confirmação e Gravação (STATE_MEM_SAVE): O botão SW4 (evento

EV_ENTER) confirma a edição do parâmetro corrente, acionando a rotina de escrita I2C

para salvar os novos valores na memória EEPROM externa, retornando em seguida para

a navegação principal.

- Cancelamento e Abortabilidade: O clique central do encoder SW7 (evento

EV_CANCEL) aborta a edição do parâmetro sem salvar, retornando o sistema ao menu

principal.

- Suspensão por Inatividade (STATE_UI_IDLE): Se o sistema permanecer inativo

sem interações por um período predefinido, um temporizador estoura (evento

EV_TIMEOUT), desviando a máquina de estados para o repouso com redução de brilho

do display. O acionamento de qualquer tecla (evento EV_ANY_KEY) recupera

instantaneamente a tela de operação.

- Recuperação de Falhas e Reset (STATE_FAULT): Caso ocorra erro de

inicialização ou no barramento I2C, o firmware entra no modo de falha. A recuperação

exige o pressionamento do botão SW1 (Reset físico) para restaurar a máquina de estados

para STATE_INIT.

### 8 MODIFICAÇÕES DE HARDWARE

Durante a validação do protótipo físico na bancada de testes, foram realizadas

correções físicas em relação ao projeto esquemático original. Estas modificações são

listadas a seguir:

- | Migração | do | Microcontrolador: | Substituição | do | microcontrolador

LPC1114FBD48/302 pelo LPC11U14F (arquitetura ARM Cortex-M0). No firmware,

substituiu-se a biblioteca LPC11xx.h pela LPC11Uxx.h.

- Remapeamento de Sinais do LCD: Devido à diferença de pinagem entre os

microcontroladores, realizou-se o corte físico de trilhas e a soldagem de jumpers. O sinal

ENABLE (E) do display foi redirecionado do pino 19 (USB_DM) para o pino 13

(PIO1_20). O sinal DATA 4 (D4) foi redirecionado do pino 20 (USB_DP) para o pino 24

(PIO1_28).

- Configuração de Pinos do Encoder: As trilhas dos canais A, B e do interruptor

do encoder rotativo SW7 conectam-se aos pinos 10 (PIO0_2), 11 (PIO1_26) e 12

(PIO1_27).

- Nomenclatura e Configuração de Portas: Atualização das macros lógicas das

portas no firmware para compatibilidade com o barramento do LPC11U14F. O LED1 foi

associado ao pino PIO0_11 e o LED2 ao pino PIO0_12.

- Ajustes de Componentes Passivos e Filtro RC: Substituição dos capacitores de

filtro RC do encoder de 10µF para 10nF para conformidade com a constante de tempo de

debounce exigida pelo datasheet do fabricante Bourns. O capacitor de 10µF na linha de

reset foi mantido para filtragem de transientes.

- Dimensionamento dos Resistores dos LEDs: Substituição dos resistores de

polarização dos LEDs D2, D3 e D4 de 1kΩ para 100Ω para elevar a corrente de operação

de 1,3 mA para 13 mA, corrigindo o brilho de sinalização.

- Isolamento de Tensão do Barramento I2C: Os resistores de pull-up R1 e R2 das

linhas SDA e SCL foram desconectados do barramento de 5V. Soldou-se um jumper

interligando a alimentação de 3.3V do pino 8 da EEPROM (U5) a esses resistores,

adequando a tensão lógica às entradas tolerantes a 3.3V do microcontrolador.

- Redirecionamento da Linha EXP01: A trilha conectada ao pino 25 do

microcontrolador foi cortada e interligada ao pino 1 do conector de expansão J5 (EXP01),

permitindo o reaproveitamento da linha.

- Chave SW6 para Função ISP: A chave táctil SW6 (ISP) foi desconectada do pino

25 original do microcontrolador e interligada por um jumper ao pino 4 (PIO0_1) do

microcontrolador LPC11U14F, que é a porta física de bootloader (ISP) desta família.

- Substituição dos Capacitores do Cristal (C25 e C26): Correção dos capacitores

de carga do oscilador de quartzo de 12 MHz de 10µF para 18pF, viabilizando a oscilação

do clock e a inicialização estável do microcontrolador.

### 9 CUSTOS

O orçamento financeiro do projeto do protótipo eletrônico divide-se nas

estimativas de aquisição de componentes e confecção da placa descritas a seguir.

9.1 MATERIAIS

O custo total de aquisição para o lote de componentes eletrônicos ativos e passivos

utilizados na montagem da placa de testes foi de aproximadamente US$ 29,54. Esta

cotação foi elaborada com base no somatório individual dos preços de mercado dos

componentes listados no Apêndice B, excluindo custos de frete internacional ou impostos

locais.

9.2 CONFECÇÃO

A confecção física do lote básico de 5 unidades de placas de circuito impresso foi

cotada junto ao fabricante internacional especializado JLCPCB. O projeto foi submetido

respeitando as especificações dimensionais em substrato padrão de fibra de vidro FR-4

com espessura de 1,6 mm, duas camadas condutivas (dupla face), espessura de cobre

externo de 1 oz, acabamento das ilhas em HASL com chumbo e processo de teste elétrico

por sonda móvel (Flying Probe Fully Test). Visualmente, determinou-se a aplicação de

máscara de solda na cor verde com serigrafia dos componentes em branco.

O valor nominal calculado pelo sistema para a manufatura do lote foi de US$ 4,00.

Contudo, com a aplicação de uma oferta especial de prototipagem, o custo base de

fabricação da placa sem componentes montados foi reduzido para US$ 2,00. Somado ao

custo logístico de envio internacional para a instituição fixado em US$ 3,30 via modal

econômico (Global Standard Direct Line), o investimento final consolidado para a

aquisição e entrega das placas totalizou US$ 5,30.

REFERÊNCIAS

BOURNS. PEC12R - 12 mm Rotary Encoder. Riverside: Bourns Inc., 2019. Disponível em: https://www.bourns.com/docs/Product-Datasheets/pec12r.pdf. Acesso em: 5 jul. 2026.

GUEDES, Byanca da Silva. PBLE01 - Co-projeto de produtos eletrônicos: Manual. Itajubá: UNIFEI, Rev. 01, nov. 2023.

NXP SEMICONDUCTORS. LPC11U1x User Manual: LPC11U14 Microcontroller. Eindhoven: NXP Semiconductors, Rev. 1.0, abr. 2021. Disponível em: https://www.nxp.com/docs/en/user-manual/UM10462.pdf. Acesso em: 5 jul. 2026.

APÊNDICE A – Memorial de cálculos

Cálculo da Constante de Tempo do Filtro RC do Encoder Rotativo

A atenuação de ruídos de contato elétrico (debounce) no encoder rotativo SW7 é

feita por um filtro passa-baixas RC passivo. Na modificação física, os capacitores foram

reduzidos para C = 10nF e os resistores de pull-up são R = 10kΩ. A constante de tempo

(τ) é calculada por:

τ = R · C

Substituindo os valores correspondentes da placa:
τ = 10 kΩ · 10 nF = (10 · 10³ Ω) · (10 · 10⁻⁹ F) = 100 μs = 0,1 ms

A frequência de corte (fc) correspondente é obtida pela expressão:

fc =

1
2 · π · R · C

=

1
2 · π · 100 μs

≈ 1,59 kHz

Este tempo de resposta de 0,1 ms filtra transitórios de alta frequência do repique

mecânico (bounce), que ocorrem na faixa de microssegundos, sem atenuar os pulsos úteis

gerados durante a rotação manual do encoder (que possuem período na ordem de

milissegundos). A capacitância de 10µF originalmente projetada gerava uma constante

de tempo de 100 ms, impedindo a leitura das transições rápidas do encoder.

Cálculo do Filtro RC da Linha de Reset

A linha de reinicialização (RESET) do microcontrolador LPC11U14F possui um

circuito de filtragem contra transientes e ruídos elétricos na inicialização. O circuito é

composto por um resistor de pull-up R = 4,7kΩ e um capacitor de filtro C = 10µF

conectados à chave táctil de Reset (SW1). A constante de tempo (τ) é dada por:

τ = R4 · C9

Substituindo os valores da placa:
τ = 4,7 kΩ · 10 μF = (4,7 · 10³ Ω) · (10 · 10⁻⁶ F) = 47 ms

Para que a tensão decresça abaixo do limiar lógico baixo de entrada (VIL ≤ 0,3 *

VDD) necessário para acionar o circuito interno de reset do chip, o botão físico SW1 deve

ser pressionado por um intervalo estimado em:

tpressionamento ≈ 3 · τ = 3 · 47 ms = 141 ms

Esta constante de tempo longa protege o microcontrolador contra reinicializações

acidentais originadas por transientes rápidos no barramento de alimentação.

Cálculo da Corrente de Sink no Barramento I2C

A modificação do barramento I2C alterou a alimentação dos resistores de pull-up

R1 e R2 (1kΩ) de 5V para 3,3V. A especificação do protocolo I2C limita a corrente

máxima de sink (IOL) dos canais de dreno aberto a 3 mA para garantir um nível lógico

baixo de saída (VOL) de no máximo 0,4 V. A expressão geral para a corrente de dreno é:

IOL =

VDD − VOL
Rp

Substituindo os valores para a tensão corrigida de 3,3V:

IOL =

3,3 V − 0,4 V
1 kΩ = 2,9 mA

A corrente de 2,9 mA está em conformidade com o limite máximo de 3 mA do

padrão I2C. Se os resistores fossem mantidos conectados ao barramento de 5V, a corrente

seria de:

IOL =

5,0 V − 0,4 V
1 kΩ = 4,6 mA

Este valor excederia o limite máximo especificado, sobrecarregando as saídas

internas de dreno aberto do LPC11U14F e deslocando a tensão lógica baixa (VOL) para

níveis inseguros.

Cálculo do Resistor Limitador de Corrente dos LEDs

O subcircuito de interação contém LEDs de sinalização (D2, D3 e D4) controlados

diretamente pelas portas digitais do microcontrolador (tensão de 3,3V). A tensão direta

típica (VF) do LED verde utilizado (Lite-On LTST-C150GKT) é de 2,0V e a corrente

nominal de operação é de aproximadamente 10 mA a 20 mA. O dimensionamento do

resistor limitador de corrente (Rd) é determinado por:

Rd =

VDD − VF

ILED

Com o resistor de 1kΩ originalmente projetado, a corrente resultante era de:

ILED =

3,3 V − 2,0 V
1 kΩ = 1,3 mA

Com a alteração do resistor limitador para Rd = 100Ω, a corrente de operação

corrigida passa a ser:

ILED =

3,3 V − 2,0 V 100 Ω | = 13 mA

Esta corrente de 13 mA garante a intensidade luminosa necessária para sinalização

visual adequada e encontra-se dentro das especificações de corrente máxima por pino (40

mA) e acumulada do encapsulamento do LPC11U14F.

Cálculo dos Capacitores de Carga do Cristal Oscilador

O circuito de clock externo utiliza um cristal de quartzo de 12 MHz (CTS

ATS12A). De acordo com as especificações do fabricante, o cristal possui uma

capacitância de carga nominal (CL) de 12 pF. O circuito possui uma capacitância parasita

(Cs) estimada pelas trilhas da PCI e pelos pinos do microcontrolador na ordem de 3 pF.

A capacitância de carga total vista pelo cristal é expressa por:

CL =

C1 · C2
C1 + C2

+ Cs

Como os capacitores de carga externos (C1 e C2, correspondentes a C25 e C26 na

placa) possuem o mesmo valor nominal (Cext), a equação é simplificada para obter Cext:

Cext = 2 · (CL − Cs

)

Substituindo os valores nominais do projeto:

Cext = 2 · (12 pF − 3 pF) = 2 · 9 pF = 18 pF

Portanto, os capacitores C25 e C26 foram dimensionados em 18 pF. O valor de

10µF originalmente projetado (comum em capacitores de desacoplamento) impediria

qualquer oscilação devido ao tempo de resposta do circuito LC e ao excesso de

impedância capacitiva nas linhas XTALIN e XTALOUT.

APÊNDICE B – Lista de compras

A lista completa com a quantidade, part numbers e custos estimados de aquisição

de cada componente do projeto da placa de circuito impresso é detalhada na Tabela 8.

Tabela 8 ‒ Lista de compras dos componentes

Item | Qtd | Ref.
PCI
Descrição | Part Number | Preço
(USD)

Fabricante

1 | 1 | U1 | MCU ARM Cortex-M0 LPC11U14F

LPC11U14FBD48/
301
4.95 | NXP
Semiconductors
2 | 1 | U4 | Transceptor USB-UART FT232RL
FT232RL-REEL | 4.80 | FTDI Chip
3 | 1 | U5 | Memória EEPROM 512K I2C
24LC512-I/SN | 1.70 | Microchip
Technology
4 | 11 | R1- R3, R5- R8, R11, R12, R15, R21

Resistor
1kΩ SMD
0805 1%
RMCF0805FT1K00 | 0.10 | Stackpole Electronics
5 | 5 | R4,
R9,
R10,
R13,
R14

Resistor
4.7kΩ SMD
0805 1%
RC0805FR-074K7L | 0.10 | YAGEO
6 | 9 | C5- C9, C14, C15, C18, C19

Capacitor
10µF SMD
1206 X5R

GRM21BR61C106
KE15
0.16 | Murata
Electronics

7 | 10 | C1- C4, C10- C13, C16, C17

Capacitor
220nF SMD
0805 X7R

C0805C224K1REC
7800
0.24 | KEMET
8 | 2 | C20,
Cx

Capacitor
10nF SMD
0805 (Filtro
Debounce)
Genérico | 0.10 | Genérico
9 | 1 | J1 | Conector DC Power Jack PJ- 002A
PJ-002A | 0.70 | CUI Devices
10 | 3 | D2,
D3,
D4

LED SMD
Verde e
Vermelho
SMD 0805
LTST-C150GKT | 0.30 | Lite-On
Electronics
11 | 1 | J10 | Receptáculo Mini USB 2.0 Tipo B SMD
1734035-2 | 1.30 | TE Connectivity
12 | 5 | SW1,
SW3-
SW6

Chave Táctil
Tactile
Switch PTH
1825910-6 | 0.13 | TE Connectivity
13 | 1 | U2 | Regulador de Tensão LDO 3.3V SOT-223
LD1117S33TR | 0.66 | STMicroelectroni
cs
14 | 1 | U3 | Regulador de Tensão LDO 5V DPAK
LD1117DT50TR | 0.94 | STMicroelectroni
cs
15 | 1 | Y1 | Cristal de Quartzo 12 MHz HC- 49/US
ATS12A | 0.36 | CTS Electronic
Components

16 | 1 | J8 | Conector Header 4 pinos passo 2.54mm
3-644456-4 | 0.33 | TE Connectivity
17 | 1 | J4 | Conector Header 5 pinos passo 2.54mm
3-644456-5 | 0.41 | TE Connectivity
18 | 3 | J5, J6,
J7

Conector
Header 7
pinos passo
2.54mm
3-644456-7 | 0.49 | TE Connectivity
19 | 1 | D1 | Diodo Retificador Schottky SOD-123
1N5819HW-7-F | 0.43 | Diodes
Incorporated
20 | 1 | J9 | Display LCD Alfanuméric o 1602A
PPTC161LFBN-RC | 0.99 | Sullins /
Genérico
21 | 1 | SW7 | Encoder Rotativo PEC12R com clique

PEC12R-3222F-S0024

1.62 | Bourns
22 | 1 | J3 | Conector Placa JTAG 10 Pinos
0702461002 | 2.88 | Molex
23 | 2 | C25, C26

Capacitor
18pF SMD
0805 NP0
50V

GRM1885C1H180J
A01D

0.05 Murata
Electronics

Fonte: Autores (2026).

ANEXOS

Este anexo contém as folhas de rosto dos datasheets de todos os componentes

utilizados no projeto do protótipo eletrônico.

Anexo A ‒ Folha de rosto do datasheet do componente Capacitor Cerâmico Murata

GRM21 (10µF, 16V, SMD 0805)

Fonte: Murata Electronics (2026).

Anexo B ‒ Folha de rosto do datasheet do componente Capacitor Cerâmico Kemet X7R

(100nF, 50V, SMD 0805)

Fonte: Kemet Electronics (2026).

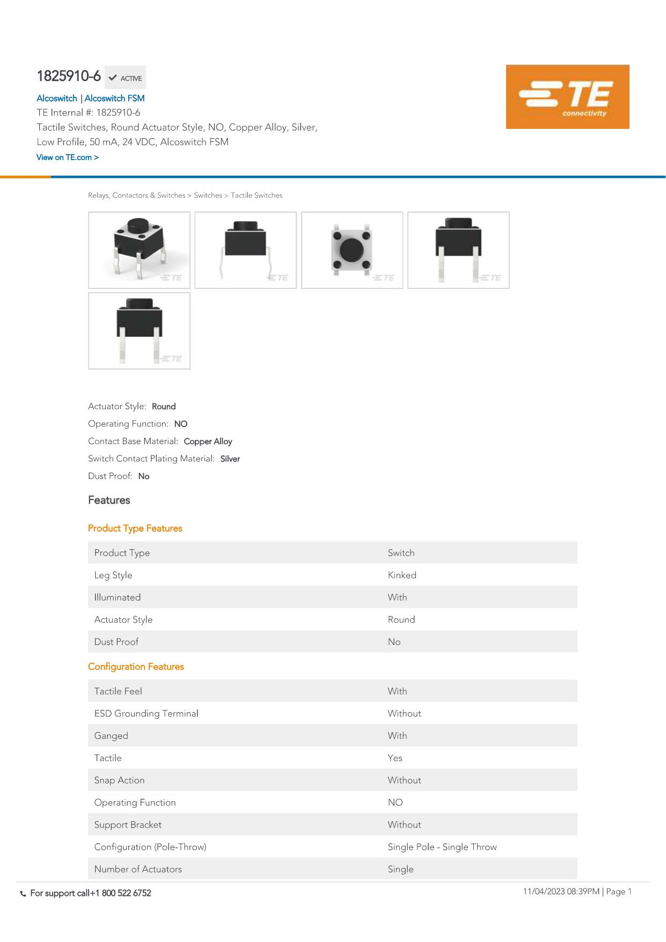
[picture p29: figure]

Anexo C ‒ Folha de rosto do datasheet do componente Chave Táctil TE Connectivity

1825910-6

Fonte: TE Connectivity (2026).

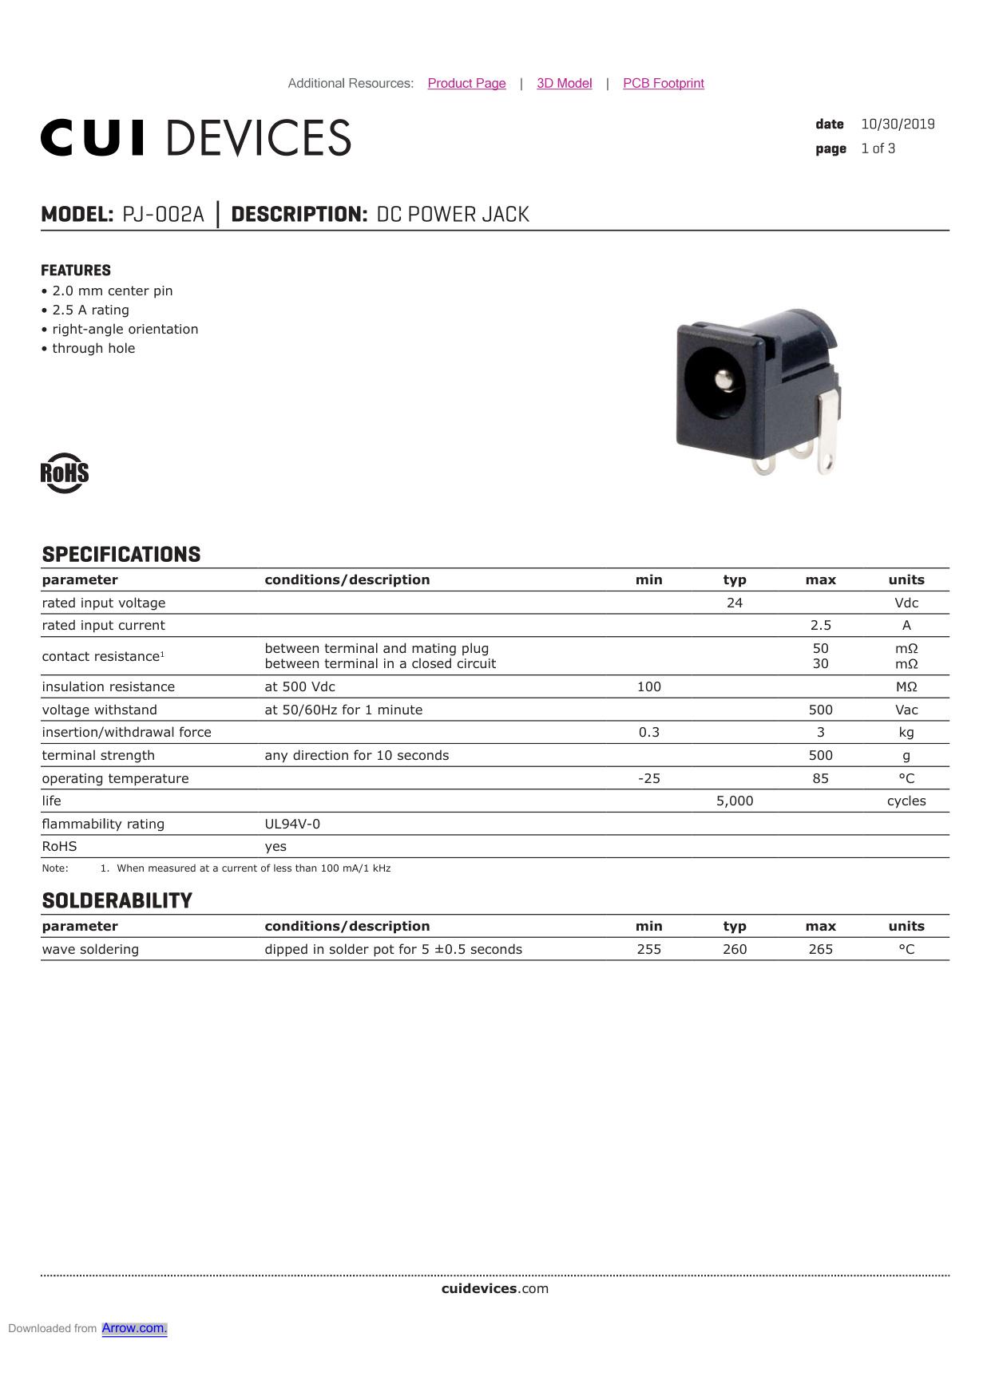
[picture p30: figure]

Anexo D ‒ Folha de rosto do datasheet do Conector de Alimentação Jack DC CUI

Devices PJ-002A

Fonte: CUI Devices (2026).

Anexo E ‒ Folha de rosto do datasheet do componente Conector JTAG Molex C-Grid

Shrouded Header 0702461002

Fonte: Molex (2026).

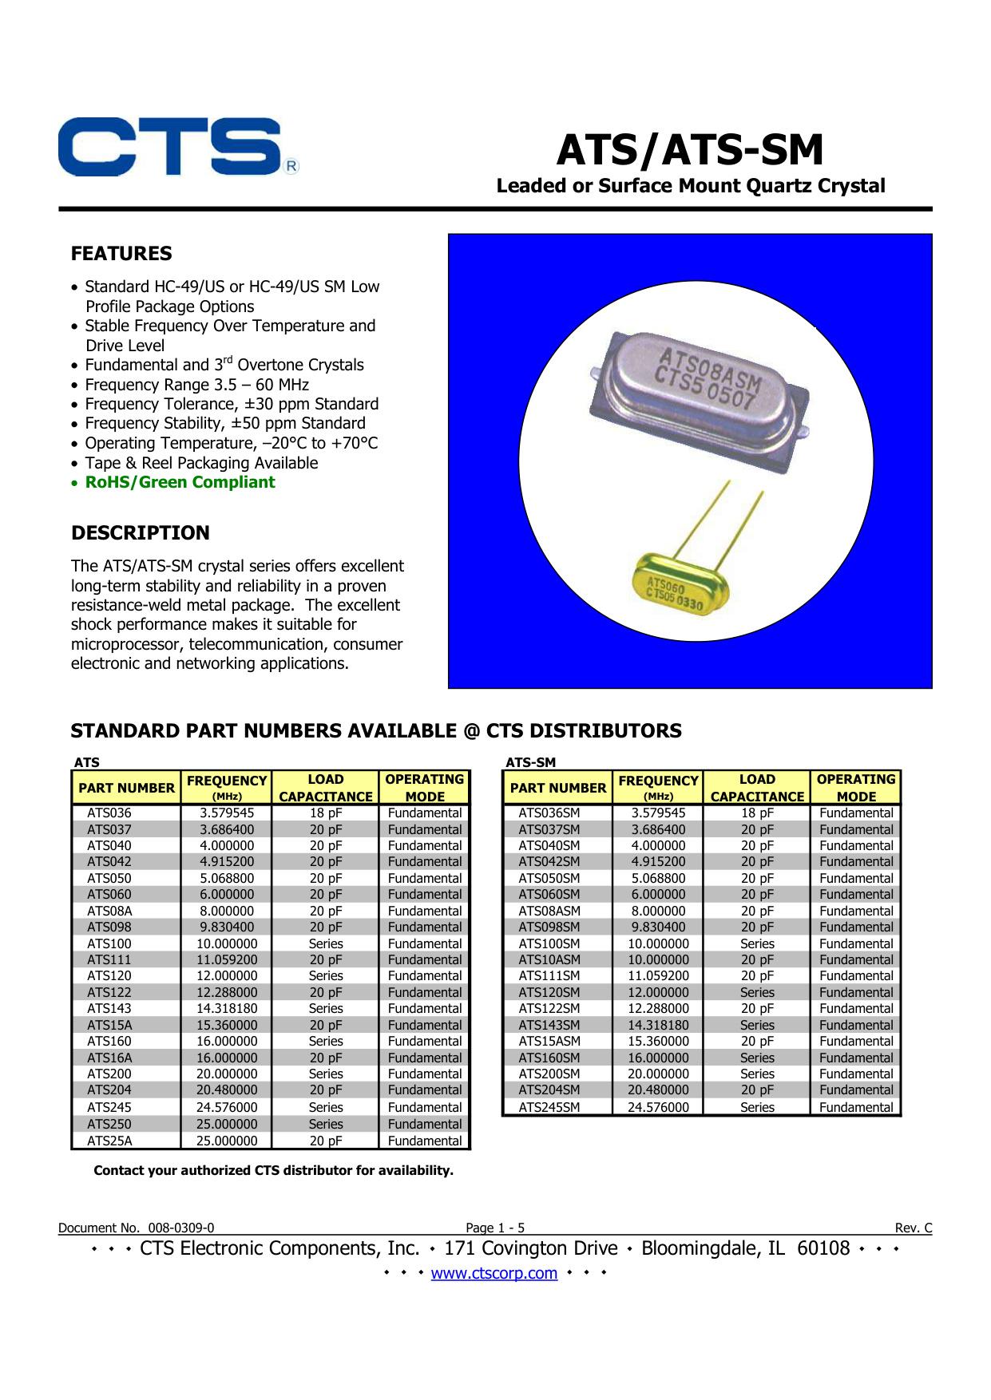
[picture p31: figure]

Anexo F ‒ Folha de rosto do datasheet do Cristal Oscilador de Quartzo CTS ATS12A

(12MHz)

Fonte: CTS Electronic Components (2026).

Anexo G ‒ Folha de rosto do datasheet do Diodo Schottky Diodes Incorporated

1N5819HW (1A, 40V)

Fonte: Diodes Incorporated (2026).

Anexo H ‒ Folha de rosto do datasheet do componente Encoder Rotativo Bourns

PEC12R-3222F

Fonte: Bourns (2026).

Anexo I ‒ Folha de rosto do datasheet do componente Conector Fêmea Sullins

Connector Solutions

Fonte: Sullins Connector Solutions (2026).

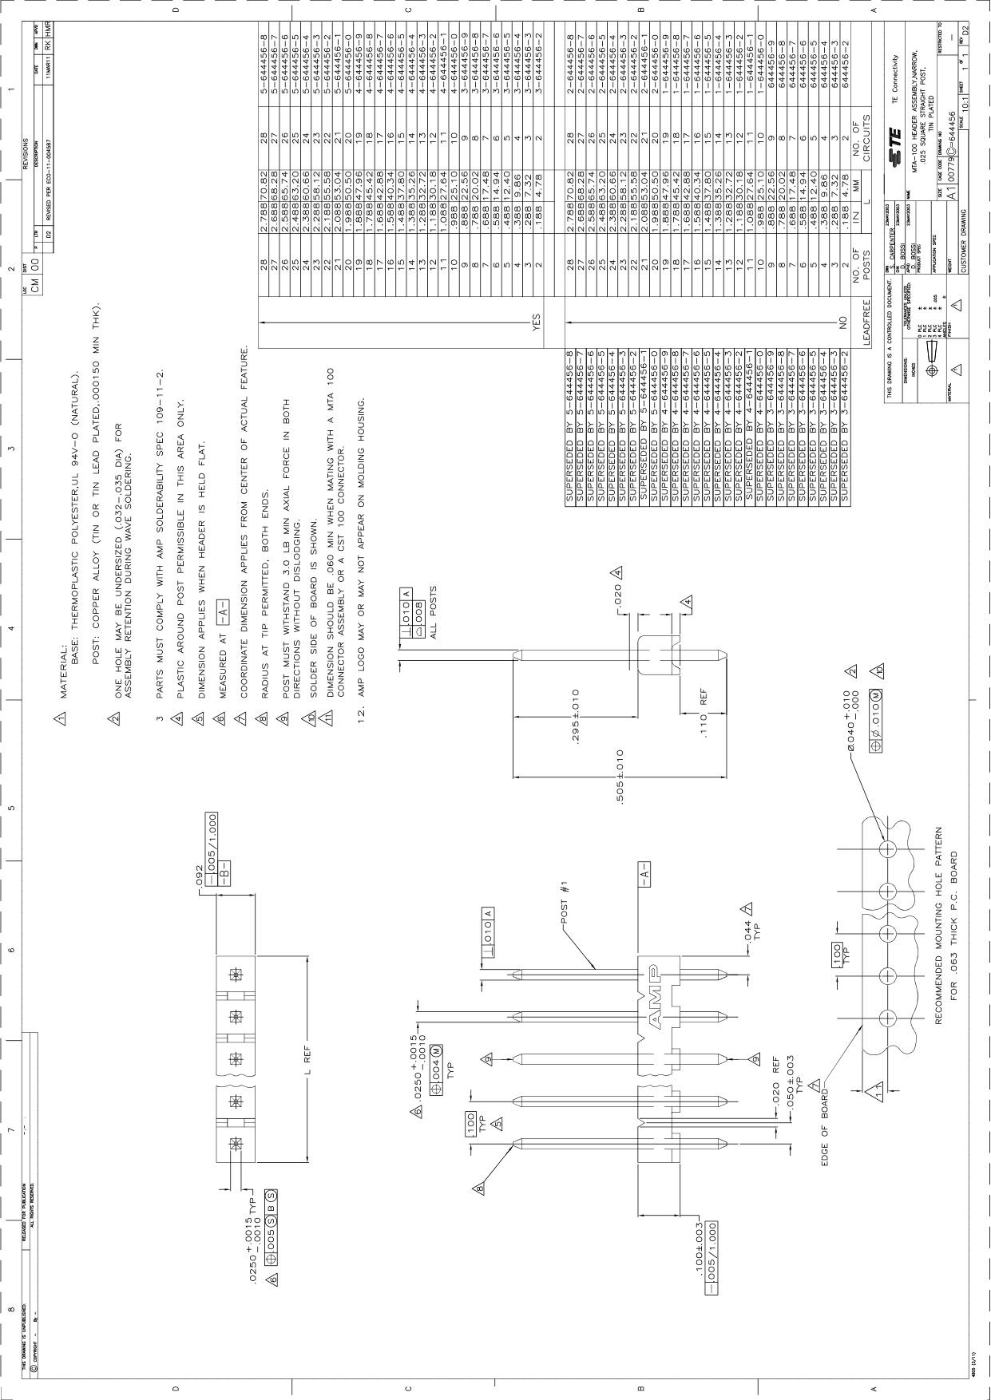
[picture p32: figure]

Anexo J ‒ Folha de rosto do datasheet do componente Conector Header MTA-100 TE

Connectivity

Fonte: TE Connectivity (2026).

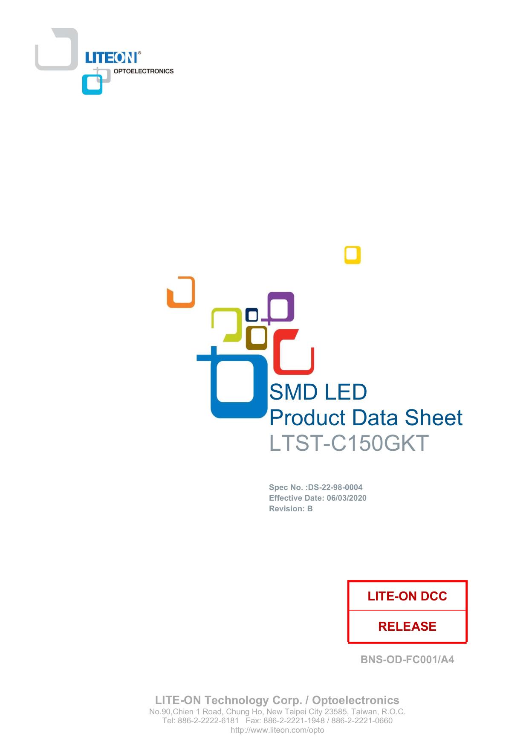
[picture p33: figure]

Anexo K ‒ Folha de rosto do datasheet do Diodo LED SMD Lite-On Technology Corp.

Fonte: Lite-On Technology (2026).

Anexo L ‒ Folha de rosto do datasheet da Memória EEPROM Microchip 24LC512

(512Kbit, I2C)

Fonte: Microchip Technology (2026).

Anexo M ‒ Folha de rosto do datasheet do Microcontrolador NXP

LPC11U14FBD48/301 (Cortex-M0)

Fonte: NXP Semiconductors (2026).

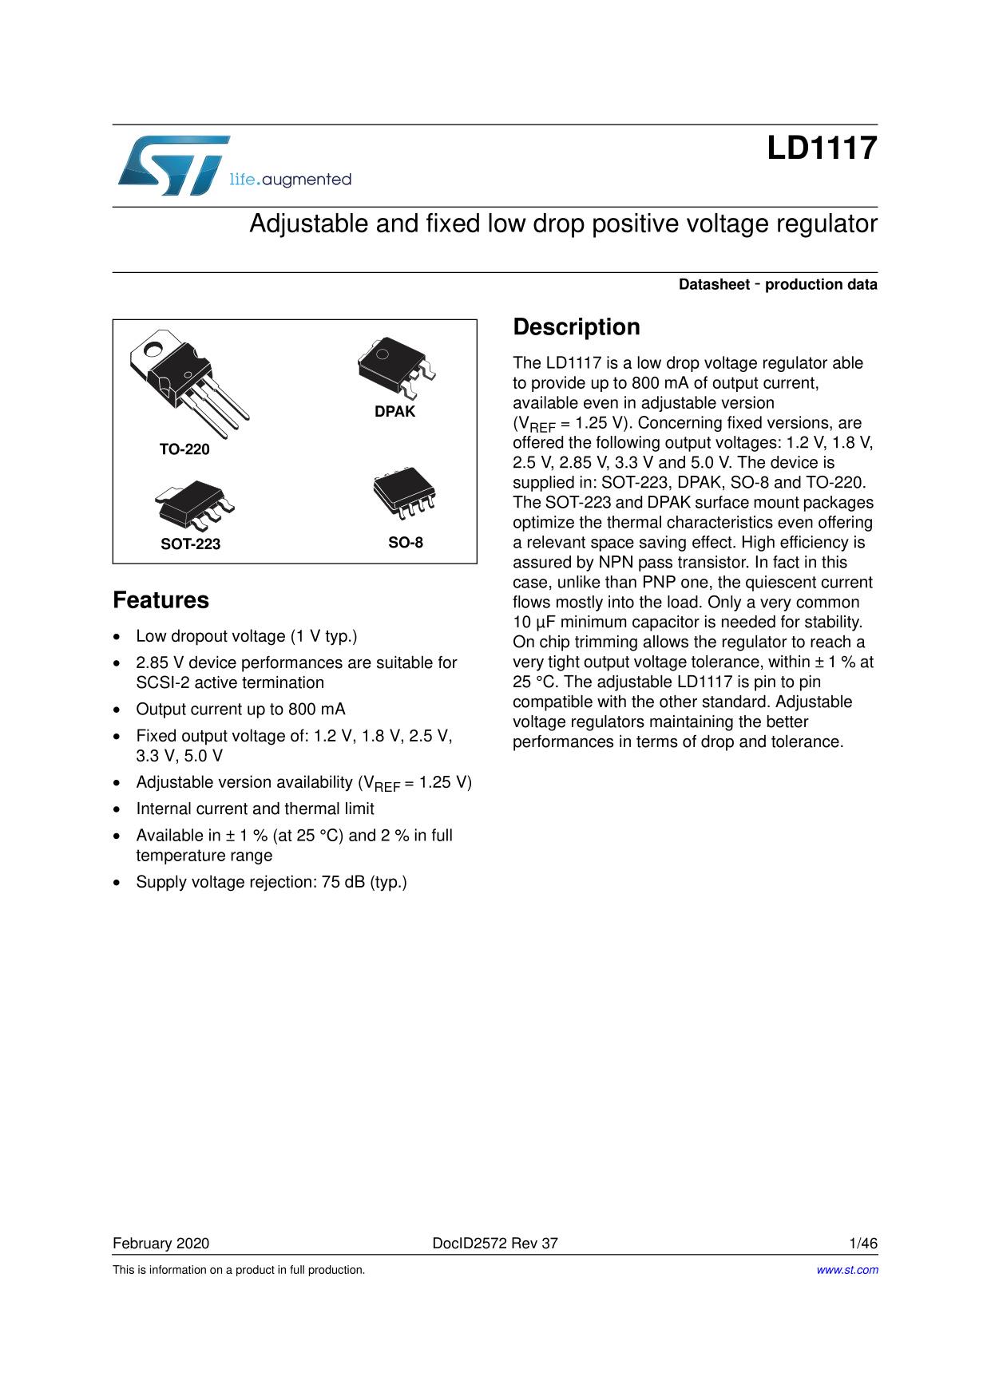
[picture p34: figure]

Anexo N ‒ Folha de rosto do datasheet do Regulador Linear de Tensão

STMicroelectronics LD1117

Fonte: STMicroelectronics (2026).

Anexo O ‒ Folha de rosto do datasheet do Resistor de Precisão SMD Stackpole

Electronics

Fonte: Stackpole Electronics (2026).

Anexo P ‒ Folha de rosto do datasheet do Resistor SMD Yageo RC_L Series (SMD

0805)

Fonte: Yageo (2026).

Anexo Q ‒ Folha de rosto do datasheet do Transceptor USB-Serial FTDI FT232RL

(USB UART)

Fonte: FTDI Chip (2026).

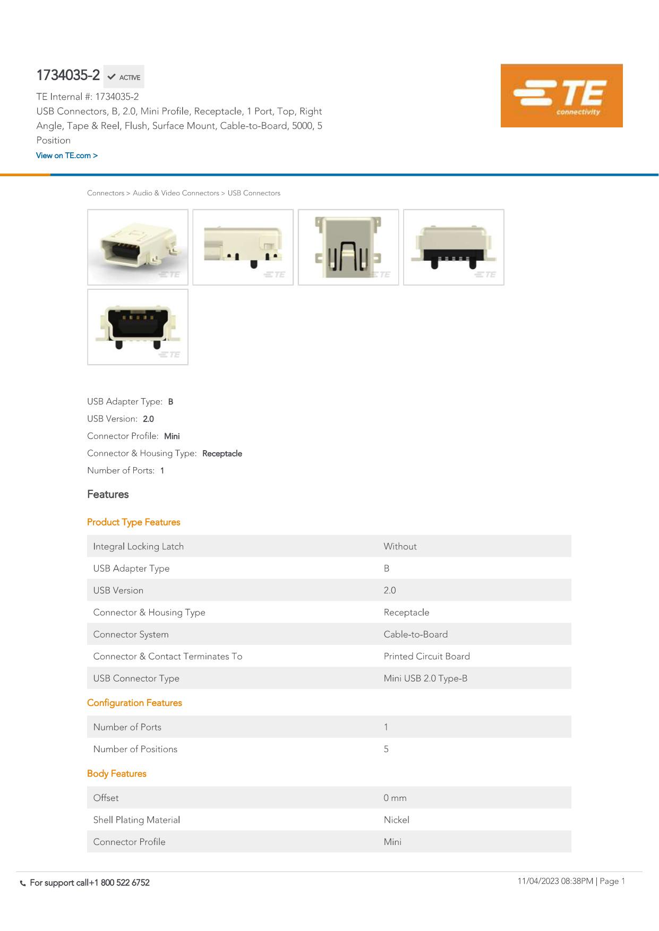
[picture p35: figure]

Anexo R ‒ Folha de rosto do datasheet do Conector Mini USB TE Connectivity

1734035-2

Fonte: TE Connectivity (2026).

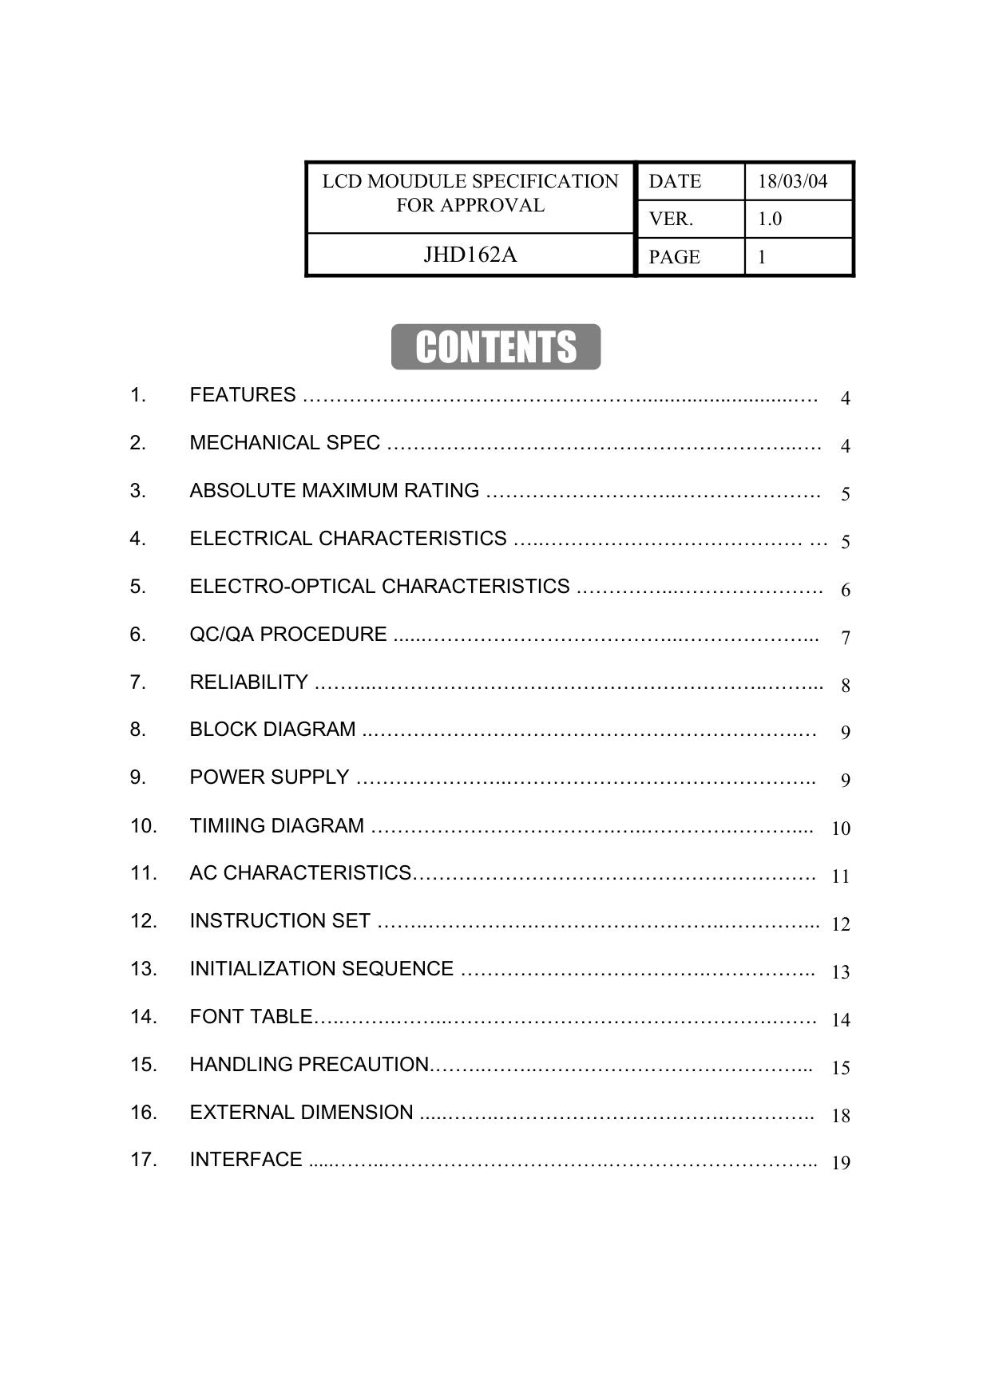
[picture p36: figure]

Anexo S ‒ Folha de rosto do datasheet do Display LCD Alfanumérico JHD JHD162A

(16x2 Caracteres)

Fonte: Shenzhen Jinghua Displays (2026).

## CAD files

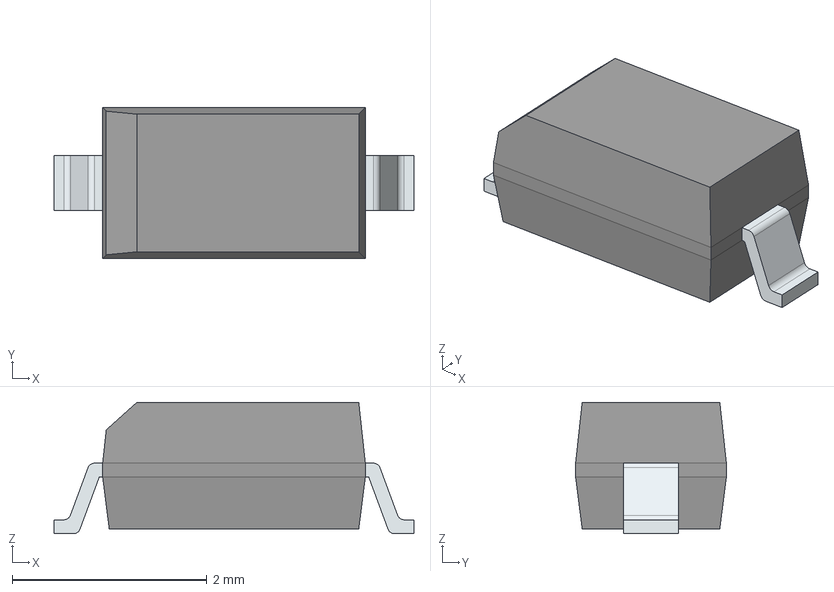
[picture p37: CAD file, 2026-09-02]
KiCad/Projeto_Final/Footprints/1N5819HW-7/1N5819HW-7.stp
3.70 x 1.55 x 1.35 mm
FilletPinL
FilletPinR

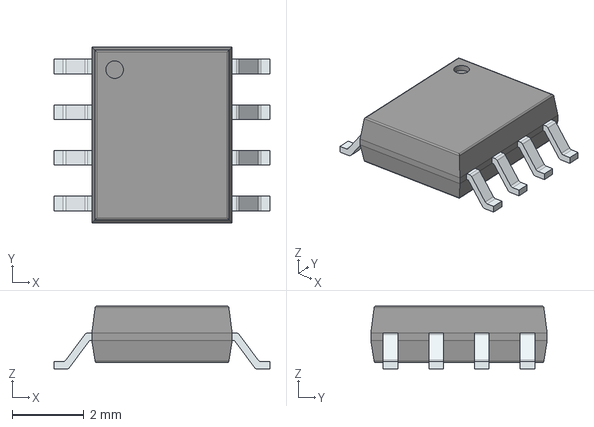
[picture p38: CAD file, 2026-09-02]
KiCad/Projeto_Final/Footprints/24LC512-SN/24LC512-I_SN.stp
6.00 x 4.90 x 1.75 mm
PinsArrayLR

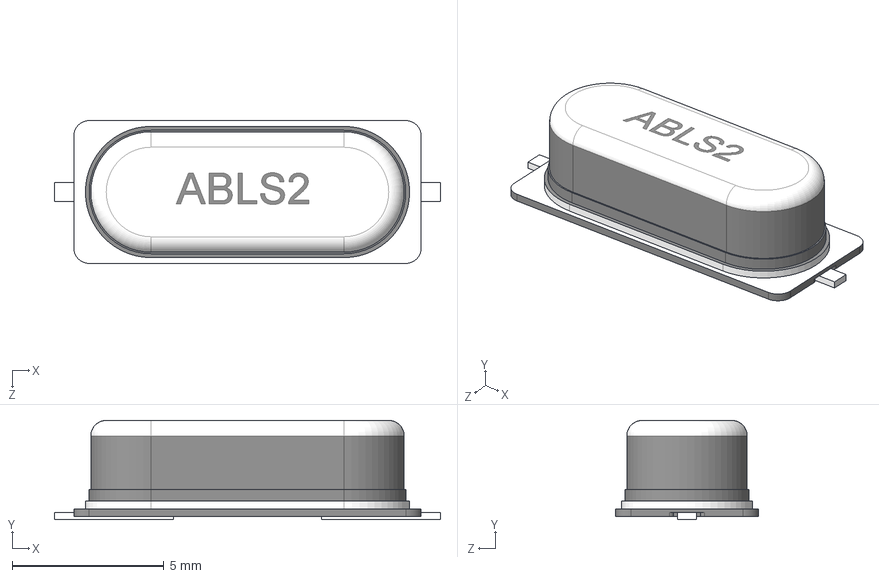
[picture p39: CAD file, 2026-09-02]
KiCad/Projeto_Final/Footprints/ATS12A/ABLS2-29.4912MHZ-D4YF-T.step
12.7 x 3.27 x 4.70 mm

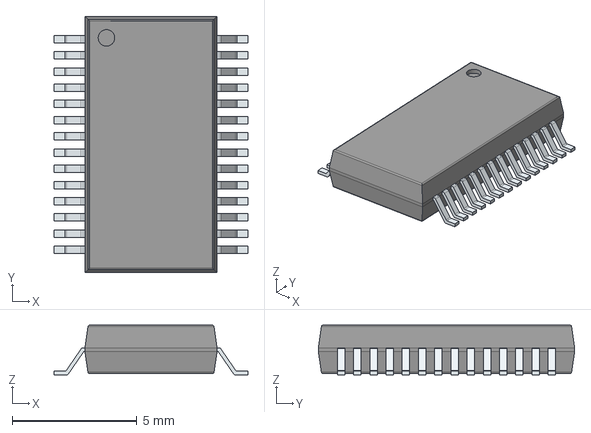
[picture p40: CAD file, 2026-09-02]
KiCad/Projeto_Final/Footprints/FT232RL/FT232RL.stp
7.78 x 10.3 x 2.00 mm
PinsArrayLR

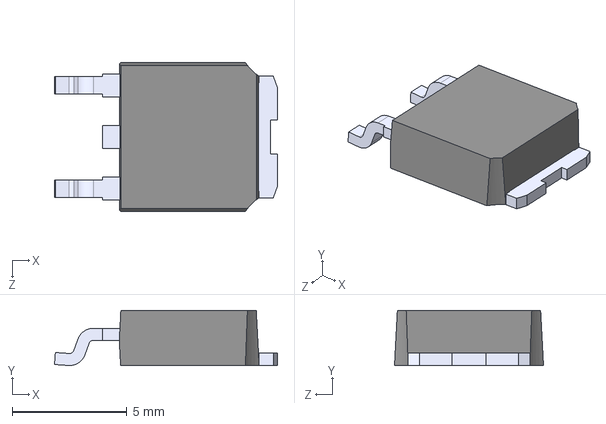
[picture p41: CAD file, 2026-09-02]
KiCad/Projeto_Final/Footprints/LD1117DT50TR/LD1117DT50TR.STEP
9.72 x 2.40 x 6.50 mm

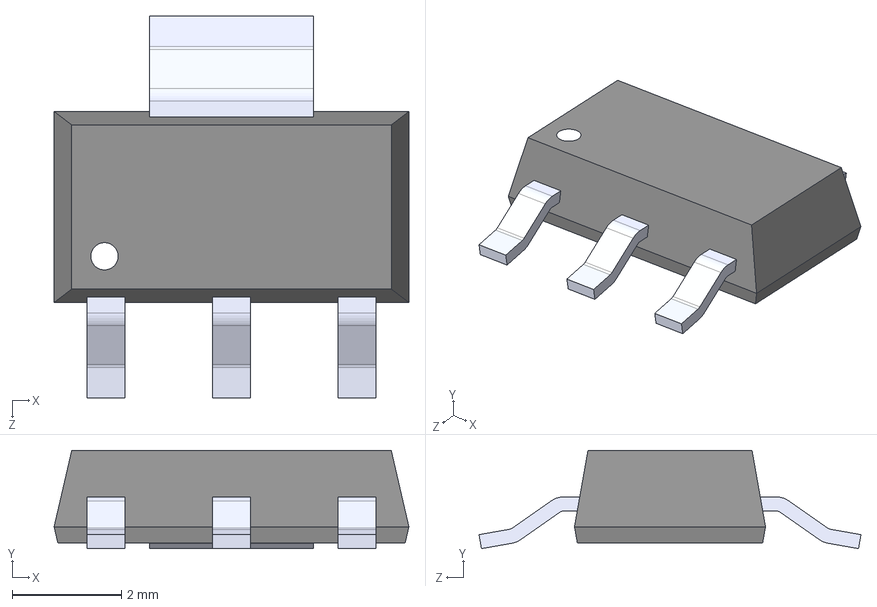
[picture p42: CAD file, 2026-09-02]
KiCad/Projeto_Final/Footprints/LD1117S33TR/LD1117S33TR.step
6.50 x 1.80 x 7.00 mm

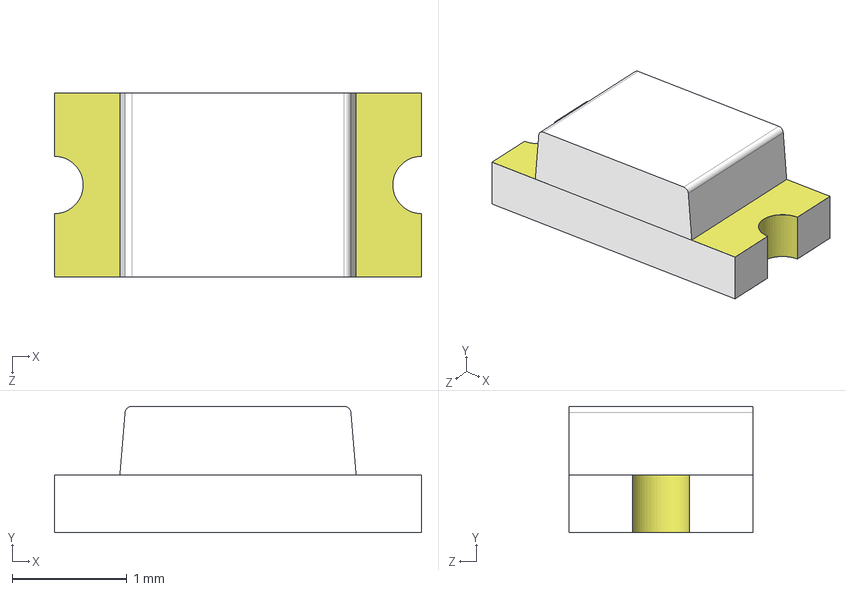
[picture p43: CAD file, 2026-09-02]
KiCad/Projeto_Final/Footprints/LTST-C150GKT/LTST-C150GKT.stp
3.20 x 1.10 x 1.60 mm

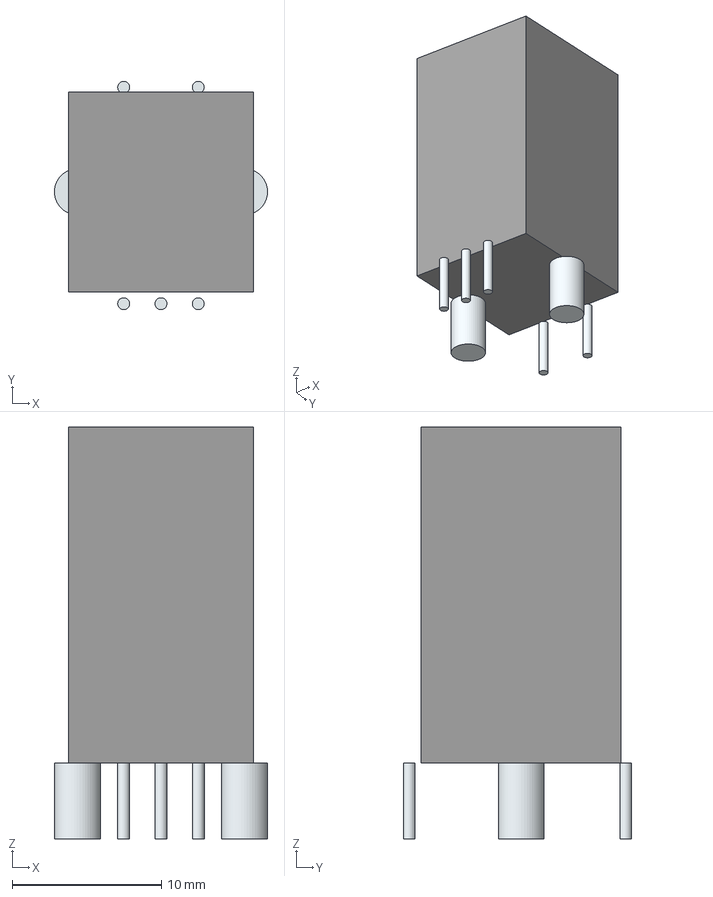
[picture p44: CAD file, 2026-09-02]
KiCad/Projeto_Final/Footprints/PEC12R-3222F/PEC12R-3222F-S0024.stp
14.3 x 15.3 x 27.6 mm
Leads

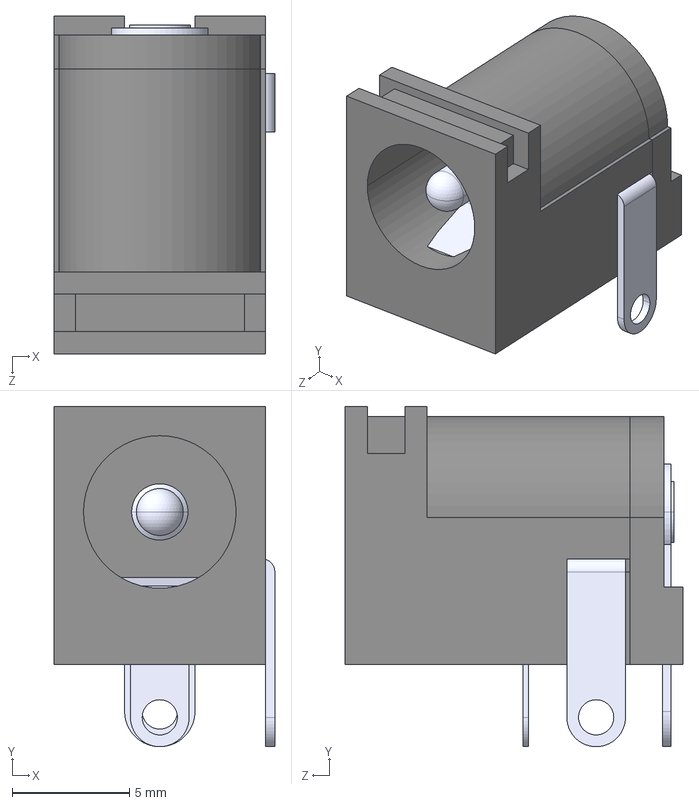
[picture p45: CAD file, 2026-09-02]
KiCad/Projeto_Final/Footprints/PJ-002A/PJ-002A--3DModel-STEP-56544.STEP
9.40 x 14.5 x 14.4 mm

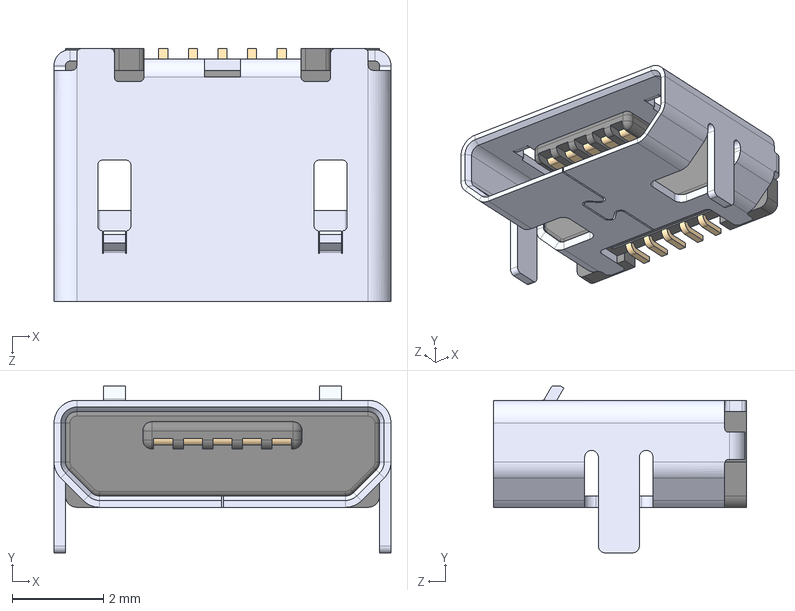
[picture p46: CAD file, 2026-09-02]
KiCad/Projeto_Final/Footprints/USBB_micro/USB3076-XX-X_REVC5.step
7.40 x 3.66 x 5.55 mm

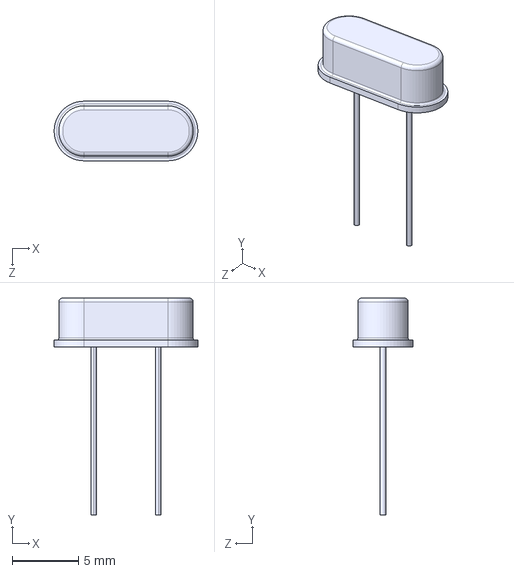
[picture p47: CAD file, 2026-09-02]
KiCad/Projeto_Final/Footprints/ATS12A/ATS12A-E.STEP
10.9 x 16.4 x 4.50 mm

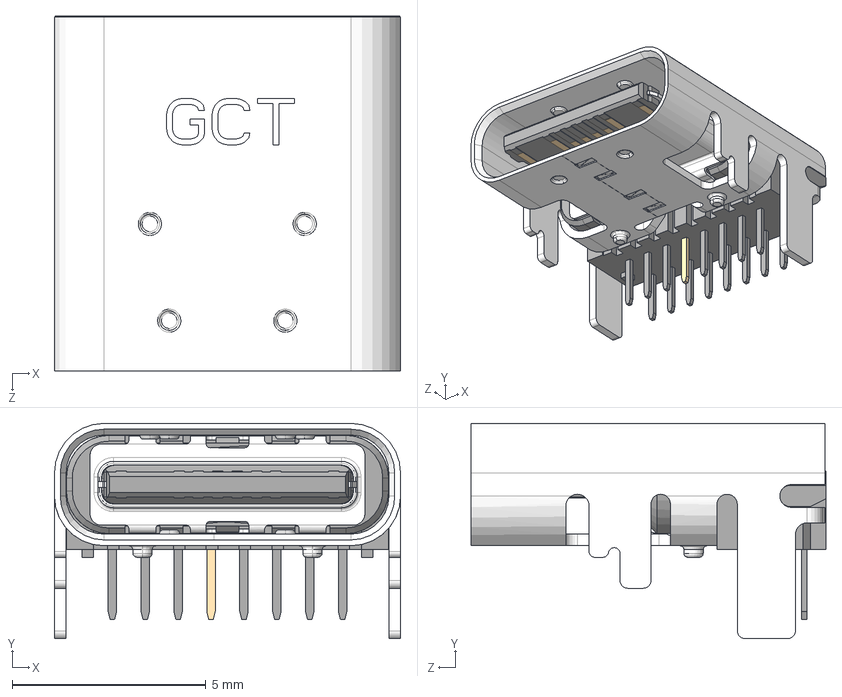
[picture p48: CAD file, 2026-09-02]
KiCad/Projeto_Final/Footprints/USBB_micro/USB4085-GF-A.stp
8.94 x 5.56 x 9.17 mm
USB4085-GF-A_PART3
USB4085-GF-A_PART2
USB4085-GF-A_PART1

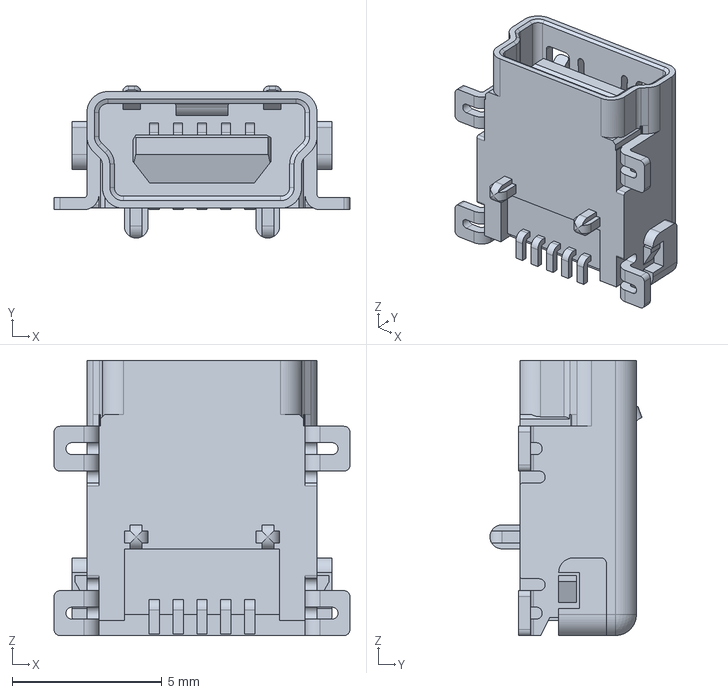
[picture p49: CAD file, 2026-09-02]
KiCad/Projeto_Final/Footprints/1734035-2/1734035-2.stp
9.90 x 5.09 x 9.20 mm

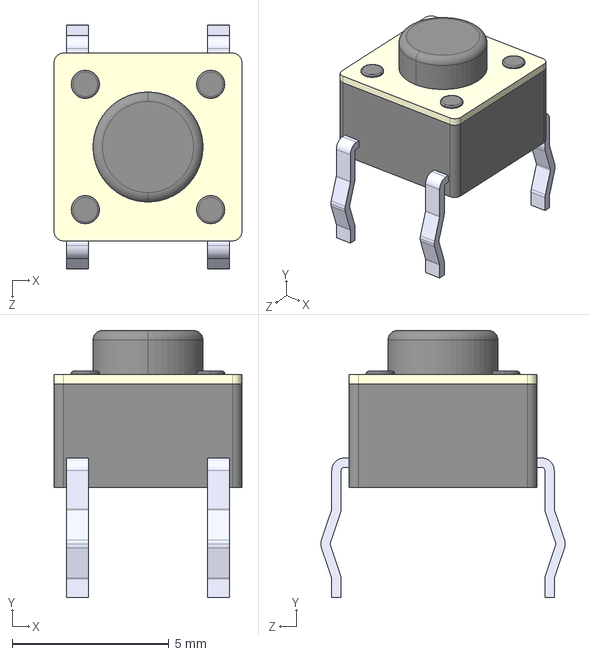
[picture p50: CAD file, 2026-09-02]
KiCad/Projeto_Final/Footprints/1825910-6/1825910-6.step
5.99 x 8.52 x 7.80 mm

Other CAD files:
KiCad/Projeto_Final/Footprints/70246-1002/70246-1002.stp

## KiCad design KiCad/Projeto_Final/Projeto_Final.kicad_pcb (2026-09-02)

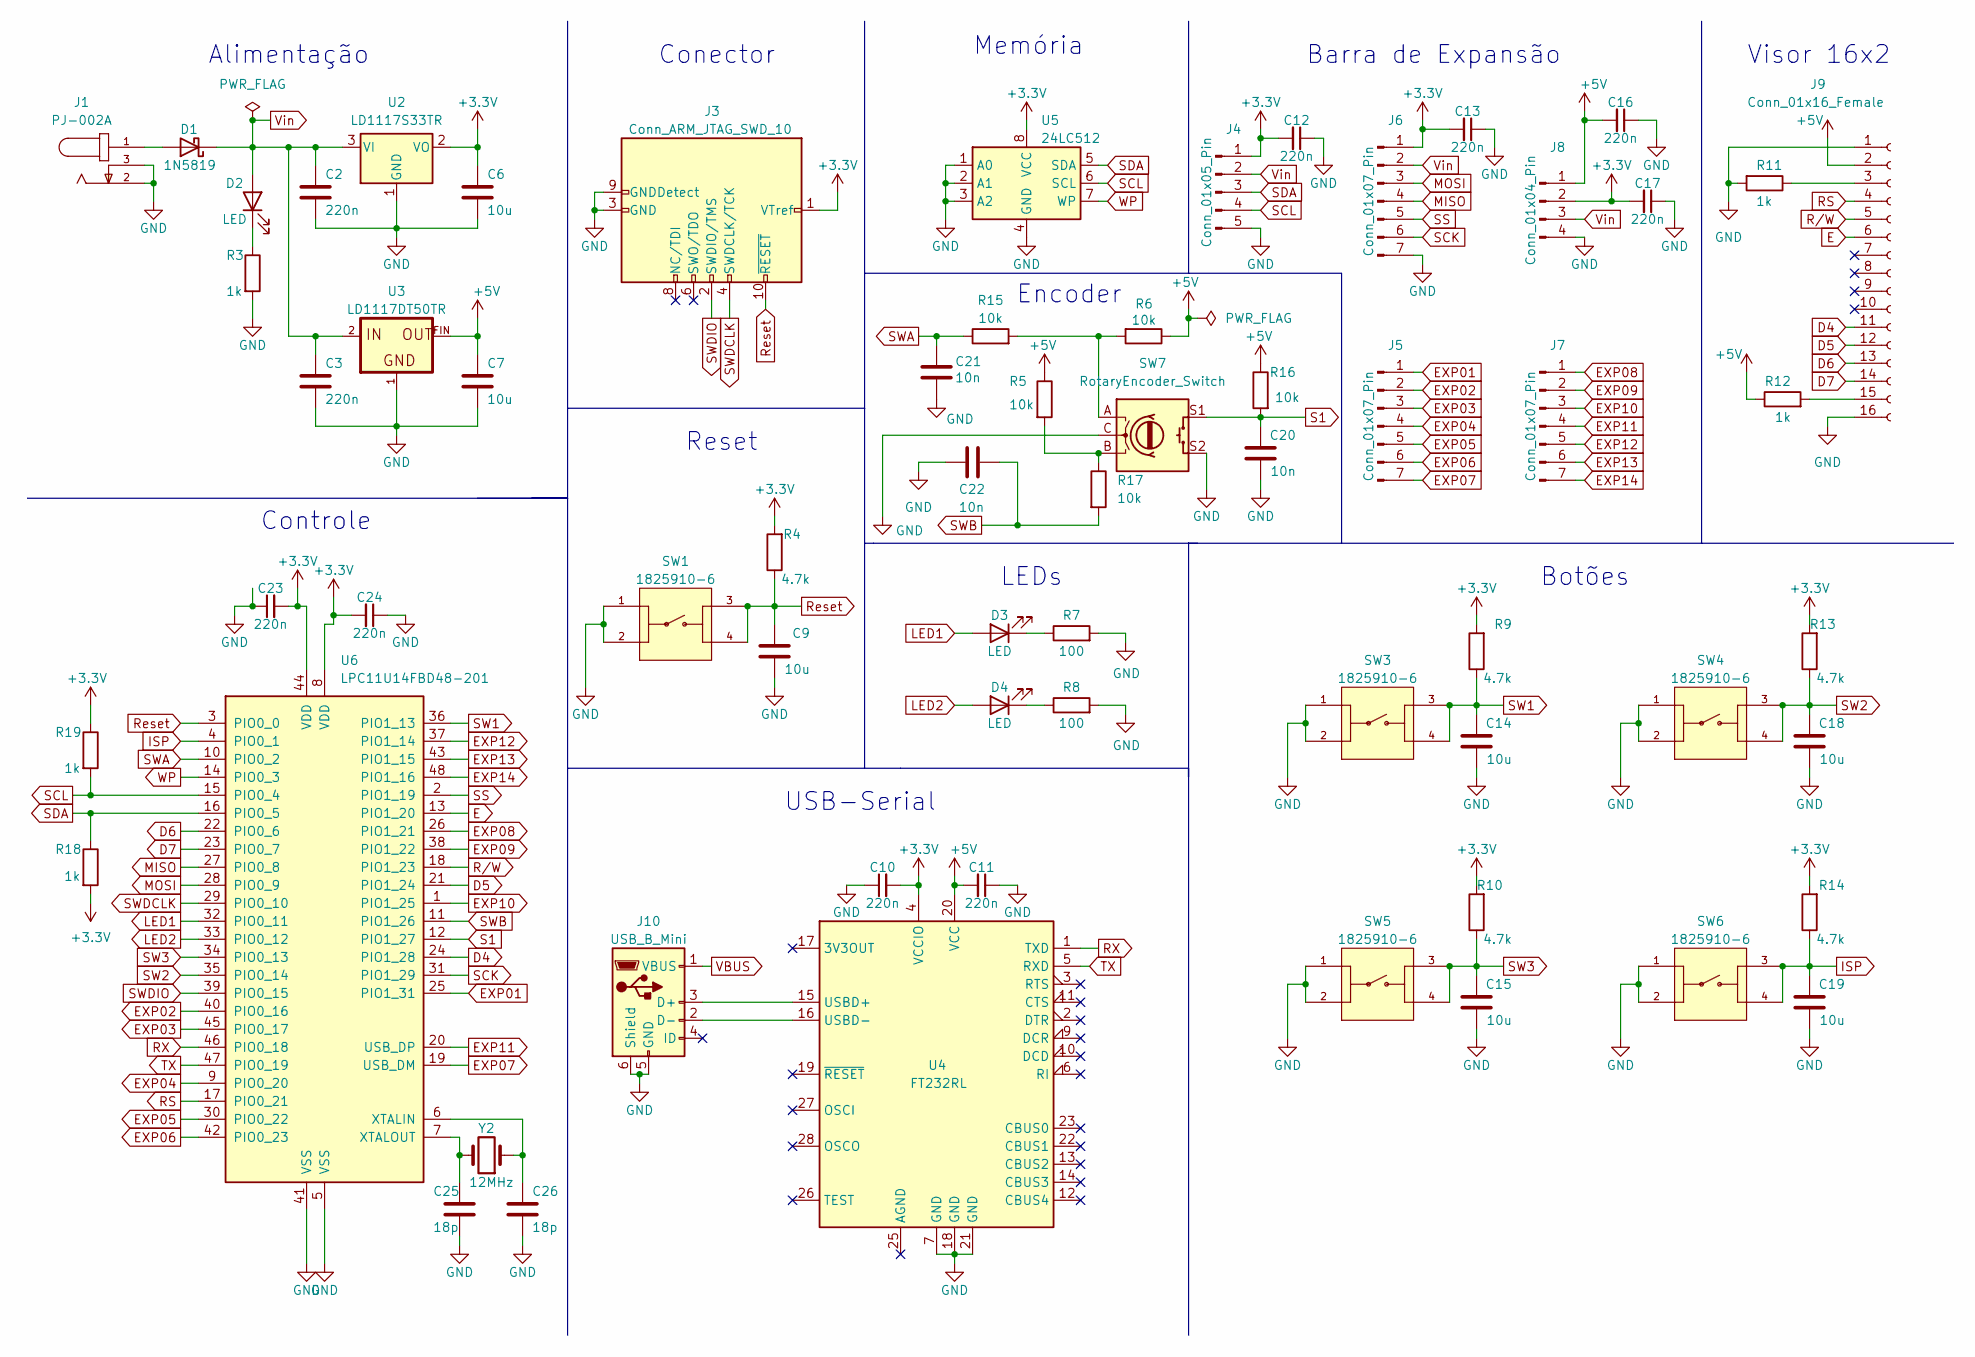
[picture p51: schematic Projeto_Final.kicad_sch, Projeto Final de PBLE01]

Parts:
C2, C3, C10, C11, C12, C13, C16, C17, C23, C24: 220n; C_0805_2012Metric
C6, C7, C9, C14, C15, C18, C19: 10u; C_0805_2012Metric
C20, C21, C22: 10n; C_0805_2012Metric
C25, C26: 18p; C_0805_2012Metric
D1: 1N5819; SOD3716X135N
D2, D3, D4: LED; LEDC3216X120N
J1: PJ-002A; CUI_PJ-002A
J3: Conn_ARM_JTAG_SWD_10; SHDR10W99P254_2X5_2032X889X947P
J4: Conn_01x05_Pin; PinHeader_1x05_P2.54mm_Vertical
J5, J6, J7: Conn_01x07_Pin; PinHeader_1x07_P2.54mm_Vertical
J8: Conn_01x04_Pin; PinHeader_1x04_P2.54mm_Vertical
J9: Conn_01x16_Female; PinHeader_1x16_P2.54mm_Vertical
J10: USB_B_Mini; 17340352
R3, R11, R12, R18, R19: 1k; R_0805_2012Metric
R4, R9, R10, R13, R14: 4.7k; R_0805_2012Metric
R5, R6, R15, R16, R17: 10k; R_0805_2012Metric
R7, R8: 100; R_0805_2012Metric
SW1, SW3, SW4, SW5, SW6: 1825910-6; SW_1825910-6-4
SW7: RotaryEncoder_Switch; PEC12R3222FS0024
U2: LD1117S33TR; SOT230P700X180-4N
U3: LD1117DT50TR; DPAK
U4: FT232RL; SOP65P778X200-28N
U5: 24LC512; SOIC127P600X175-8N
U6: LPC11U14FBD48-201; LQFP-48_7x7mm_P0.5mm
Y2: 12MHz; ATS12A

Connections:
+3.3V: C6.1, C10.2, C12.2, C13.2, C17.2, C23.2, C24.2, J3.1 (VTref), J4.1, J6.1, J8.2, R4.2, R9.2, R10.2, R13.2, R14.2, R18.2, R19.1, U2.2 (VO), U4.4 (VCCIO), U5.8 (VCC), U6.8 (VDD), U6.44 (VDD)
+5V: C7.1, C11.2, C16.2, J8.1, J9.2, R5.1, R6.1, R12.1, R16.1, U3.FIN, U4.20 (VCC)
D4: J9.11, U6.24 (PIO1_28)
D5: J9.12, U6.21 (PIO1_24)
D6: J9.13, U6.22 (PIO0_6)
D7: J9.14, U6.23 (PIO0_7)
E: J9.6, U6.13 (PIO1_20)
EXP01: J5.1, U6.25 (PIO1_31)
EXP02: J5.2, U6.40 (PIO0_16)
EXP03: J5.3, U6.45 (PIO0_17)
EXP04: J5.4, U6.9 (PIO0_20)
EXP05: J5.5, U6.30 (PIO0_22)
EXP06: J5.6, U6.42 (PIO0_23)
EXP07: J5.7, U6.19 (USB_DM)
EXP08: J7.1, U6.26 (PIO1_21)
EXP09: J7.2, U6.38 (PIO1_22)
EXP10: J7.3, U6.1 (PIO1_25)
EXP11: J7.4, U6.20 (USB_DP)
EXP12: J7.5, U6.37 (PIO1_14)
EXP13: J7.6, U6.43 (PIO1_15)
EXP14: J7.7, U6.48 (PIO1_16)
GND: C2.2, C3.2, C6.2, C7.2, C9.1, C10.1, C11.1, C12.1, C13.1, C14.1, C15.1, C16.1, C17.1, C18.1, C19.1, C20.1, C21.2, C22.2, C23.1, C24.1, C25.2, C26.2, J1.2, J1.3, J3.3 (GND), J3.5 (GND), J3.9 (GNDDetect), J4.5, J6.7, J8.4, J9.1, J9.16, J10.5 (GND), J10.6 (Shield), R3.2, R7.2, R8.2, R11.2, SW1.1, SW1.2, SW3.1, SW3.2, SW4.1, SW4.2, SW5.1, SW5.2, SW6.1, SW6.2, SW7.C, SW7.S2, U2.1 (GND), U3.1, U4.7 (GND), U4.18 (GND), U4.21 (GND), U5.1 (A0), U5.2 (A1), U5.3 (A2), U5.4 (GND), U6.5 (VSS), U6.41 (VSS)
ISP: C19.2, R14.1, SW6.3, SW6.4, U6.4 (PIO0_1)
LED1: D3.2 (A), U6.32 (PIO0_11)
LED2: D4.2 (A), U6.33 (PIO0_12)
MISO: J6.4, U6.27 (PIO0_8)
MOSI: J6.3, U6.28 (PIO0_9)
unnamed: D1.2 (A), J1.1
unnamed: D2.1 (K), R3.1
unnamed: D3.1 (K), R7.1
unnamed: D4.1 (K), R8.1
unnamed: J9.3, R11.1
unnamed: J9.15, R12.2
unnamed: J10.3 (D+), U4.15 (USBD+)
unnamed: J10.2 (D-), U4.16 (USBD-)
unnamed: R6.2, R15.2, SW7.A
unnamed: R5.2, R17.1, SW7.B
unnamed: C26.1, U6.6 (XTALIN), Y2.1
unnamed: C25.1, U6.7 (XTALOUT), Y2.2
RS: J9.4, U6.17 (PIO0_21)
RX: U4.1 (TXD), U6.46 (PIO0_18)
Reset: C9.2, J3.10 (~RESET), R4.1, SW1.3, SW1.4, U6.3 (PIO0_0)
R/W: J9.5, U6.18 (PIO1_23)
S1: C20.2, R16.2, SW7.S1, U6.12 (PIO1_27)
SCK: J6.6, U6.31 (PIO1_29)
SCL: J4.4, R19.2, U5.6 (SCL), U6.15 (PIO0_4)
SDA: J4.3, R18.1, U5.5 (SDA), U6.16 (PIO0_5)
SS: J6.5, U6.2 (PIO1_19)
SW1: C14.2, R9.1, SW3.3, SW3.4, U6.36 (PIO1_13)
SW2: C18.2, R13.1, SW4.3, SW4.4, U6.35 (PIO0_14)
SW3: C15.2, R10.1, SW5.3, SW5.4, U6.34 (PIO0_13)
SWA: C21.1, R15.1, U6.10 (PIO0_2)
SWB: C22.1, R17.2, U6.11 (PIO1_26)
SWDCLK: J3.4 (SWDCLK/TCK), U6.29 (PIO0_10)
SWDIO: J3.2 (SWDIO/TMS), U6.39 (PIO0_15)
TX: U4.5 (RXD), U6.47 (PIO0_19)
VBUS: J10.1 (VBUS)
Vin: C2.1, C3.1, D1.1 (K), D2.2 (A), J4.2, J6.2, J8.3, U2.3 (VI), U3.2
WP: U5.7 (WP), U6.14 (PIO0_3)

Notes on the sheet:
Alimentação
Controle
LEDs
Visor 16x2
Reset
Memória
USB-Serial
Barra de Expansão
Botões
Encoder
Conector

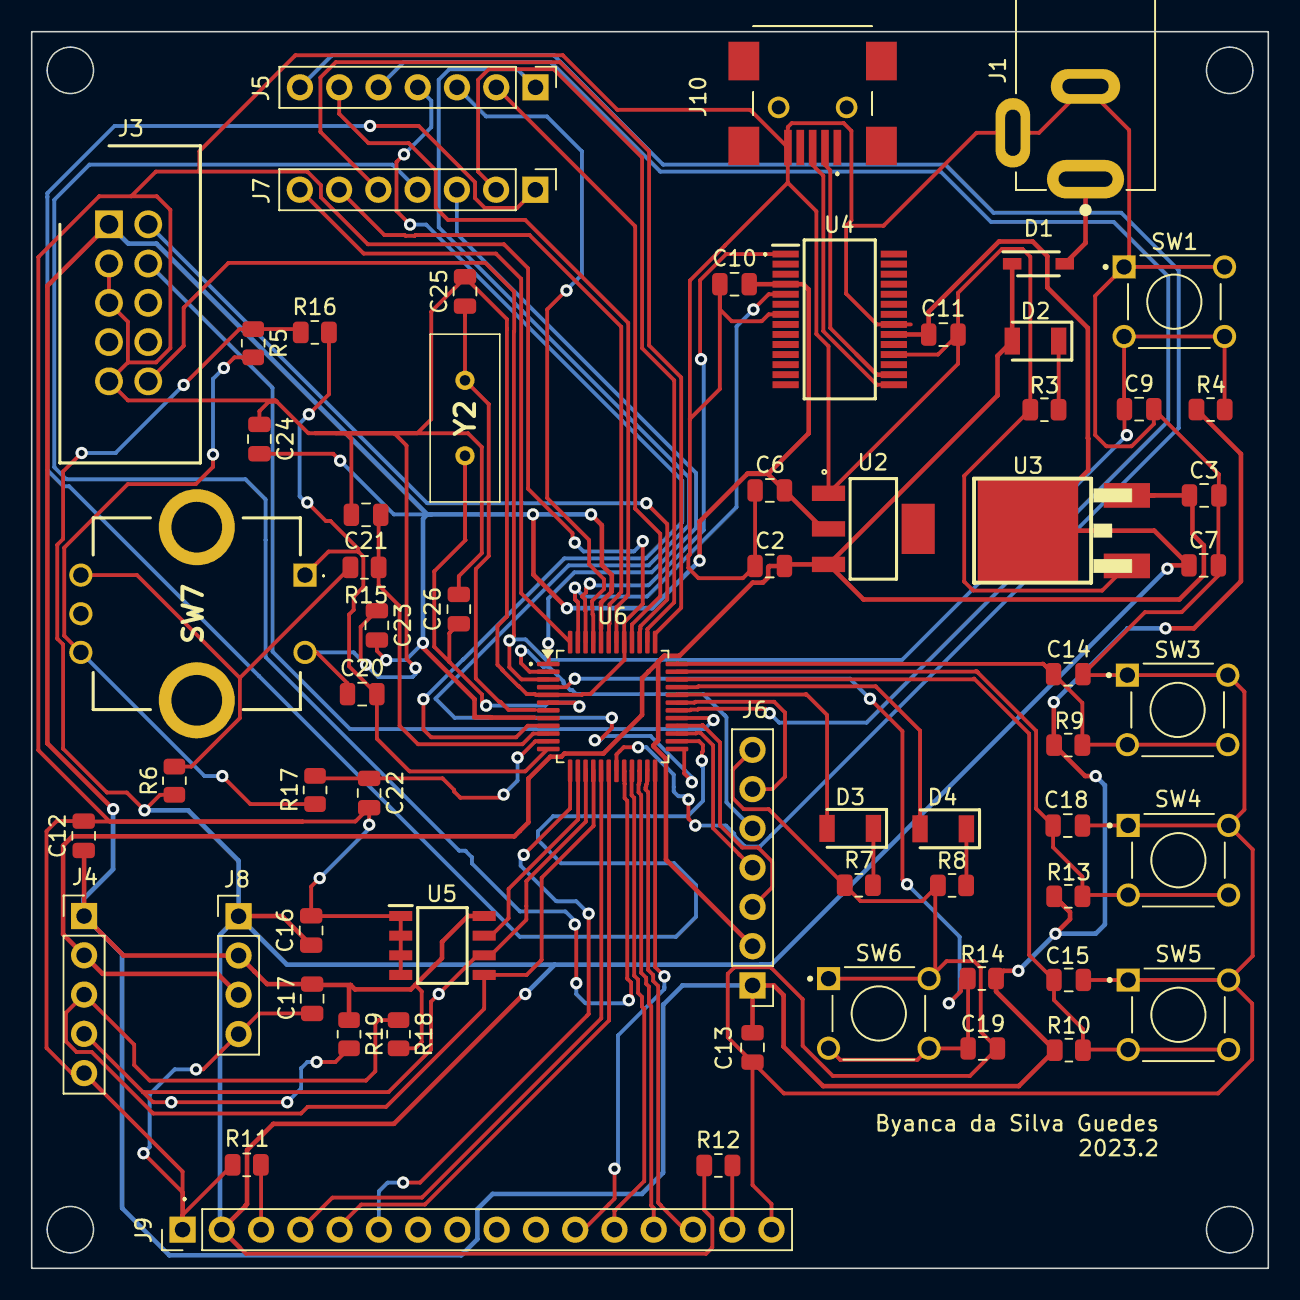
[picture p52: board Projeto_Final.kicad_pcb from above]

Board: 2 copper layers, 80.0 x 80.0 mm, 64 parts (0 on the bottom side), 58 nets.

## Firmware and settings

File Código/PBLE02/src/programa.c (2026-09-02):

#include "programa.h"

//hardware
#include "hardware/LCD.h"
#include "hardware/RTC.h"
#include "hardware/Teclado.h"
#include "hardware/ENCODER.h"
#include "hardware/LED.h"
#include "hardware/Serial.h"

//ctl
#include "ctl/output.h"
#include "ctl/event.h"
#include "ctl/var.h"
#include "ctl/stateMachine.h"
#include "ctl/timer.h"


const uint32_t OscRateIn = 20000000;
volatile uint32_t millis_counter = 0;

int main(void){
	//clock
	iniciaTimer();
	Chip_Clock_EnablePeriphClock(SYSCTL_CLOCK_GPIO);

	iniciaI2C();

	//hardware
	outputInit();
	iniciaLED();
	iniciaSerial();

	//software
	eventInit();
	iniciaSM();

	LCD_esconderCursor();
	LCD_clear();

	while(1){
		smLoop();
		processaComandoSerial();
	}
}

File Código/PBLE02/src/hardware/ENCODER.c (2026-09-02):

/*
 * encoder.c
 */

#include "encoder.h"

// Mapeamento dos pinos conforme o esquemático
#define ENC_PORT_A 0
#define ENC_PIN_A  2

#define ENC_PORT_B 1
#define ENC_PIN_B  26

#define ENC_PORT_SW 1
#define ENC_PIN_SW 27

/*
 * Aqui usamos os 2 bits (A,B) como um estado de 0 a 3 e uma tabela
 * com todas as transições possíveis entre estados consecutivos. Cada
 * transição válida vale +1 ou -1 (um "quarter-step"); transições
 * impossíveis (ruído/bounce) valem 0. Um clique físico do encoder
 * equivale a 4 quarter-steps, então só reportamos um movimento quando
 * o encoder volta ao estado de repouso (detent), com A=1 e B=1 (nível
 * alto pelos pull-ups quando o encoder não está sendo girado).
 *
 * indice = (estado_anterior << 2) | estado_atual
 */
static const int8_t tabelaQuadratura[16] = {
     0, -1,  1,  0,
     1,  0,  0, -1,
    -1,  0,  0,  1,
     0,  1, -1,  0
};

static uint8_t estadoAnterior = 0;  // ultimo estado (A<<1)|B
static int8_t  acumulador     = 0;  // soma dos quarter-steps desde o ultimo detent

void iniciaEncoder(void) {
    // 1. Habilita o clock para o bloco GPIO (redundante com o do LED, mas seguro)
    Chip_Clock_EnablePeriphClock(SYSCTL_CLOCK_GPIO);

    // 2. Configura os pinos como GPIO (FUNC0) e HABILITA os resistores de Pull-Up
    // O Pull-Up garante nível lógico ALTO quando o encoder estiver "aberto"
    Chip_IOCON_PinMuxSet(LPC_IOCON, ENC_PORT_A, ENC_PIN_A, (IOCON_FUNC0 | IOCON_MODE_PULLUP));
    Chip_IOCON_PinMuxSet(LPC_IOCON, ENC_PORT_B, ENC_PIN_B, (IOCON_FUNC0 | IOCON_MODE_PULLUP));
    Chip_IOCON_PinMuxSet(LPC_IOCON, ENC_PORT_SW, ENC_PIN_SW, (IOCON_FUNC0 | IOCON_MODE_PULLUP));

    // 3. Define a direção dos pinos como Entrada (Input = 0)
    Chip_GPIO_SetPinDIR(LPC_GPIO, ENC_PORT_A, ENC_PIN_A, 0);
    Chip_GPIO_SetPinDIR(LPC_GPIO, ENC_PORT_B, ENC_PIN_B, 0);
    Chip_GPIO_SetPinDIR(LPC_GPIO, ENC_PORT_SW, ENC_PIN_SW, 0);

    // 4. Salva o estado inicial (A,B) para referência da máquina de estados
    uint8_t A = Chip_GPIO_GetPinState(LPC_GPIO, ENC_PORT_A, ENC_PIN_A);
    uint8_t B = Chip_GPIO_GetPinState(LPC_GPIO, ENC_PORT_B, ENC_PIN_B);
    estadoAnterior = (A << 1) | B;
    acumulador = 0;
}

int leEncoder(void){
    uint8_t A = Chip_GPIO_GetPinState(LPC_GPIO, ENC_PORT_A, ENC_PIN_A);
    uint8_t B = Chip_GPIO_GetPinState(LPC_GPIO, ENC_PORT_B, ENC_PIN_B);
    uint8_t estadoAtual = (A << 1) | B;

    if (estadoAtual == estadoAnterior) {
        return 0; // nada mudou desde a ultima leitura
    }

    uint8_t indice = (uint8_t)((estadoAnterior << 2) | estadoAtual);
    acumulador += tabelaQuadratura[indice];
    estadoAnterior = estadoAtual;

    int movimento = 0;

    // Só reporta o clique quando o encoder volta ao repouso (A=1,B=1).
    //
    // Idealmente um clique fisico gera 4 quarter-steps (+4 ou -4), mas
    // como a leitura aqui e por polling (o loop principal tambem faz
    // LCD, serial, etc.), e facil perder alguma leitura intermediaria.
    // Por isso usamos apenas o SINAL do acumulado (nao o valor exato):
    // qualquer saldo positivo/negativo ao voltar ao repouso ja conta
    // como um clique no sentido correspondente. Isso torna a leitura
    // tolerante a passos perdidos, sem reintroduzir o bug de "sempre
    // o mesmo sentido" (transicoes invalidas continuam valendo 0).
    if (estadoAtual == 3) {
        if (acumulador > 0)
            movimento = 1;
        else if (acumulador < 0)
            movimento = -1;

        acumulador = 0; // sempre zera ao passar pelo detent
    }

    return movimento;
}

int leBotaoEncoder(void) {
    // Como usamos Pull-Up, o botão pressionado joga o sinal para 0 (GND)
    if (Chip_GPIO_GetPinState(LPC_GPIO, ENC_PORT_SW, ENC_PIN_SW) == 0) {
        return 1; // Pressionado
    }
    return 0; // Solto
}

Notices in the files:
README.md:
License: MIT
